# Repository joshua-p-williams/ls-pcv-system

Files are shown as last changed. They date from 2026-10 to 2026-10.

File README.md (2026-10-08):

# LS PCV System

Build a **crankcase health monitoring system** for a **2002 Pontiac Trans Am WS6 with a naturally aspirated 408 CID Gen III LS-based stroker** and Holley Terminator X. Measure crankcase pressure/vacuum to establish normal behavior, investigate changes over time, and design and validate the ventilation system.

This repository is an engineering notebook and a practical learning resource: mechanical design, hardware, firmware, calibration, and test results belong together. It explains how the parts work, why the design uses them, and how to assemble and evaluate the system as the project develops.

## Project purpose

Crankcase pressure is an additional **engine-health signal**. It reflects the balance between combustion gases leaking past the pistons into the crankcase (**blow-by**) and the positive crankcase ventilation (**PCV**) system removing those gases. Pressure also depends on ventilation restrictions, available intake vacuum and operating conditions. A change can therefore indicate a change in the engine, the ventilation system, or both. [Motorservice's discussion of excess crankcase pressure](https://www.ms-motorservice.com/MediaAssets/1727614_ks_50003605-02_web.pdf) describes both increased blow-by and ventilation faults as possible causes.

The goal is to measure that behavior repeatably, establish a baseline, and compare later observations under similar conditions. The instrumentation also gives ventilation design and tuning a measurable basis rather than relying on appearance, assumptions or the absence of visible oil leaks.

### Justifiable uses

- **Investigate increasing blow-by:** pressure changes may warrant checking ring, cylinder or piston condition after accounting for ventilation behavior; pressure alone does not measure blow-by flow.
- **Identify possible PCV restrictions or failures:** investigate plugged restrictors, blocked hoses, valve faults or catch-can problems when readings depart from the baseline.
- **Evaluate ventilation capacity under load:** measure behavior at high engine speed and wide-open throttle (WOT), when manifold-vacuum evacuation is reduced on this naturally aspirated engine.
- **Recognize abnormal positive pressure:** flag behavior that warrants investigation for oil leakage, seal problems, dipstick displacement or excessive oil carryover, without promising warning before damage occurs.
- **Compare PCV changes objectively:** evaluate restrictor sizes, relief-valve settings, hose routing and catch-can configurations using repeatable measurements.
- **Establish a fresh-engine baseline:** record known-good behavior to support later comparisons.
- **Provide a condition-monitoring signal:** reveal significant changes that may deserve attention even when drivability appears normal.
- **Support diagnostics:** correlate pressure with engine speed, load/manifold absolute pressure (MAP), throttle position and other available engine data.
- **Trend behavior over time:** supplement occasional compression and leak-down tests with observations from comparable operating conditions.
- **Evaluate ventilation strategies:** assess whether atmospheric venting, manifold-vacuum PCV or another arrangement meets the project's measured pressure and flow needs. Pressure performance alone does not establish suitability in every other respect.

### Intended role and interpretation

This is a **condition-monitoring and early-warning signal**, not a standalone instrument for identifying a specific mechanical failure. The same pressure change can result from increased gas production or reduced ventilation capacity. Further inspection, compression/leak-down testing and other evidence may be needed to distinguish causes.

The most useful indication is a repeatable departure from the engine's normal behavior under comparable conditions, rather than a single universal pressure threshold. Compare similar engine speed, load, temperature and ventilation configurations, using consistent sensor calibration and pressure-tap placement. A ventilation change may require a new baseline.

For a **hypothetical example, not project data or an alarm setting**:

> If the engine repeatedly produces +2 inH2O at 6,000 RPM/WOT and later produces +8 inH2O under comparable conditions, the increase warrants investigation. It does not, by itself, establish worn rings or any other specific failure.

The project has two connected purposes: monitor changes in crankcase behavior and provide the instrumentation needed to design and validate the ventilation system. Firmware, automated trending, alarm behavior and correlation with engine data remain development goals; the current prototype does not yet implement those capabilities. See the [measurement architecture](hardware/architecture/measurement-system.md), [firmware requirements](firmware/README.md) and [test plan](docs/testing/test-plan.md) for the work toward them.

## System concept

```text
Crankcase -> catch can -> interchangeable fixed restrictor -> manifold vacuum
                 |
                 +-> low-cracking-pressure relief -> atmosphere

Pressure measurement: upstream of the restrictor, referenced to atmosphere
Gauge: FTP sensor -> conditioning -> ADS1115 -> ESP32-S3 -> GC9A01 display
```

The [engine PCV overview](hardware/architecture/pcv-system.md) records the selected fresh-air and evacuation paths. Exact ports, fittings, physical hose routing and sensor mounting remain open.

## Current baseline

The baseline combines reported installation and purchase information, imported artifacts, and current design choices. Purchased and modeled components have not yet established measured system performance. The [original project context](docs/LS_PCV_SYSTEM_CONTEXT.md) preserves earlier reasoning and superseded proposals.

| Area | State |
| --- | --- |
| Catch can | Installed as an earlier project on 2026-09-13 in temporary vented mode; manifold-vacuum PCV remains incomplete |
| Restrictor | 3.0 mm baseline; 2.0 and 4.0 mm comparison variants; initial PAHT-CF print reported complete |
| Relief | Three EVIL ENERGY valves purchased; advertised 0.5 PSI opening pressure; approximately 0.1 PSI desired, modification/bench validation pending |
| Instrumentation | FTP sensor on hand; HiSport 13585316 pigtail not yet received; actual identity/pinout, fit and calibration pending |
| Power | [SSLHONG B09NVG35CX](hardware/components/gauge-power-supply/README.md) purchased for USD 13.99; advertised 8-60 V input, 5 V / 3 A USB-C output; validation pending |
| Gauge | ESP32-S3 bench/XIAO boards, GC9A01 TFTs, and ADS1115 modules purchased; ADC conditioning, wiring, final display layout, and enclosure pending; no firmware yet |
| Repository | Documentation, catch-can photos, native restrictor CAD, 3MF variants, and model views imported; measured data still pending |

Primary pressure unit: **inH2O**, relative to atmosphere; negative means vacuum. Approximately -3 to -8 inH2O at hot idle/light cruise is a provisional tuning target, not a GM specification or a validated limit. The 3 mm restrictor is a baseline, not a proven final choice.

## Repository map

| Location | Contents |
| --- | --- |
| [AGENTS.md](AGENTS.md) | Instructions for Codex and other coding assistants |
| [Hardware documentation](hardware/README.md) | Architecture, interfaces, wiring and component navigation |
| [Diagram inventory](hardware/DIAGRAMS.md) | Existing drafts and proposed diagrams/interface pages |
| [A04: engine PCV overview](hardware/architecture/pcv-system.md) | Planned airflow, relief, restrictor and pressure tap |
| [A01: overall gauge architecture](hardware/architecture/gauge-system.md) | Planned measurement, controller, display and power boundaries |
| [A02: power architecture](hardware/architecture/power-system.md) | Supply paths, returns and bench/vehicle/USB modes |
| [A03: measurement signal chain](hardware/architecture/measurement-system.md) | Calibration, validity, peak capture and display smoothing |
| [Diagramming standard](docs/diagramming-and-wiring-standard.md) | Formats, folder responsibilities, evidence and tooling |
| [W01 bench harness](hardware/wiring/bench/README.md) | Full wiring draft, proposed GPIOs, generated connection schedule and phased assembly checks |
| [L01 / Wokwi](simulation/wokwi/README.md) | Complete intended bench connections, visual-part mappings and future simulation limits |
| [Wokwi adoption](docs/wokwi-adoption.md) | Tool responsibilities and illustration/simulation scope |
| [cad/pcv-restrictor/](cad/pcv-restrictor/README.md) | Restrictor design intent and source/export conventions |
| [Hardware components](hardware/components/README.md) | Component descriptions, design decisions and import records |
| [hardware/bom/parts.md](hardware/bom/parts.md) | Parts, procurement status, and unresolved selections |
| [Gauge electronics](hardware/components/gauge-electronics/README.md) | Integration and reading/building path; separate N16R8, XIAO and GC9A01 component guides |
| [Pressure sensor and pigtail](hardware/components/fuel-tank-pressure-sensor/README.md) | Purchased parts, connector references, and verification needs |
| [ADS1115 acquisition](hardware/components/adc/README.md) | ADC selection, preliminary conditioning, and sampling plan |
| [Gauge power supply](hardware/components/gauge-power-supply/README.md) | Converter selection, power plan, and mounting reference |
| [Check valve / relief](hardware/components/check-valve-relief-valve/README.md) | Purchased valve, vendor claims, and relief-validation needs |
| [Datasheets](hardware/datasheets/README.md) | Preserved vendor revisions and official source links |
| [firmware/](firmware/README.md) | Gauge requirements and planned ESP32-S3 development environment |
| [docs/testing/](docs/testing/test-plan.md) | Planned bench and vehicle validation |
| [Open questions](docs/open-questions.md) | Follow-up questions, evidence needed and bench-harness dependencies |
| [docs/status.md](docs/status.md) | Next work and unresolved decisions |
| [Catch-can installation](docs/installation/2026-09-13-catch-can.md) | Earlier vented installation, timeline, and photos |
| [data/](data/README.md) | Calibration and measurement record conventions |
| [Original context](docs/LS_PCV_SYSTEM_CONTEXT.md) | Historical rationale; superseded choices are not current instructions |

Create `cad/gauge/` and `docs/research/` with their first useful content. Native FreeCAD source belongs in `cad/<component>/source/`; the current restrictor 3MF variants are together in `cad/pcv-restrictor/printing/`. Add intentional STL/STEP exports under a component's `exports/` if needed. Keep installation photos in `media/photos/`, model views/diagrams in `media/diagrams/`, and vendor illustrations in `media/reference/`.

## Working in this repository

Start with this README and the relevant component document. Use the original context for background; dated measurements and updated design documents should explain any changes to that baseline. Keep assumptions, published claims, physical observations, and measured results distinct.

Use the BOM for current purchase/inventory facts, component READMEs for current design details, and `docs/status.md` for open work. Dated installation/import records preserve what was observed or imported at that time. Native CAD defines saved geometry; physical records define what was actually built and measured. Reconcile conflicts explicitly instead of assuming the historical context or a filename is authoritative for every question.

Use UTF-8, LF line endings, descriptive lowercase kebab-case names where practical, and explicit units. Preserve native CAD source and raw measurements. For important changes, record the reason, evidence, validation, and unresolved questions alongside the affected component.

There are no firmware dependencies, build commands, or automated tests yet. Review Markdown links, units, and consistency, and run `git diff --check` for unstaged changes and `git diff --cached --check` for staged changes. Review new untracked files separately; before committing, ensure the staged versions include the intended edits. Add build/test instructions when executable code is introduced.

## Private intake workflow

Place new source material in `_staging/inbox/<batch>/` (for example, a dated project folder). The entire root `_staging/` directory is ignored by Git. Assistants may use `_staging/work/<batch>/` for processing while preserving your inbox originals.

Ask for a batch to be imported. The import should select useful engineering content, remove personal/sensitive information and embedded image metadata, and place reviewed public copies in the appropriate project folders. A public import record should explain provenance, transformations, omissions, and unresolved claims without linking to private files. Originals stay in the inbox unless you request cleanup.

Ignored directories are local only. On a fresh clone, create the inbox with `New-Item -ItemType Directory -Force _staging/inbox` in PowerShell. Git ignore is protection against accidental adds, not encryption or a substitute for reviewing public files; never force-add the staging tree.

## Next steps

1. Verify physical variants, measured bores, and slicer behavior against the [adopted restrictor CAD design](cad/pcv-restrictor/README.md).
2. Confirm current parts status and final plumbing; the earlier vented installation is documented separately.
3. Finalize ADS1115 conditioning/configuration and verify sensor, board, and display electrical interfaces before bringing up the ESP32-S3/GC9A01 prototype.
4. Characterize the sensor and relief valve on the bench before vehicle tuning.

This design is specific to this engine until evidence supports broader use. The gauge is a diagnostic instrument, not a certified safety device. See the [test plan](docs/testing/test-plan.md) for validation gates.

License selection is pending; this scaffold does not add a license grant.

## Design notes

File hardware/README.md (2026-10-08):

# Hardware documentation

Start with the [diagram inventory](DIAGRAMS.md) to choose upcoming documentation and the [diagramming/wiring standard](../docs/diagramming-and-wiring-standard.md) for formats, responsibilities, evidence labels and tooling.

- [Components](components/README.md): component descriptions, design notes and import records.
- [Architecture](architecture/README.md): system, PCV, power and measurement relationships. Current drafts: [A04: engine PCV overview](architecture/pcv-system.md), [A01: overall gauge architecture](architecture/gauge-system.md), [A02: power architecture](architecture/power-system.md), and [A03: measurement signal chain](architecture/measurement-system.md).
- [Pinouts](pinouts/README.md): module and connector identities and interface evidence.
- [Wiring](wiring/README.md): separate bench and vehicle harnesses.
- [Wokwi illustrations and simulation](../simulation/wokwi/README.md): L01's initial component-and-wire view, virtual/physical mappings and future ESP32 simulation.
- [Schematics and layouts](schematics/README.md): optional spatial illustrations and future circuit projects.
- [BOM](bom/parts.md): existing procurement authority.
- [Datasheets](datasheets/README.md): preserved reference revisions.

Use the [gauge integration guide](components/gauge-electronics/README.md#reading-and-building-path) for the learning and assembly path. Separate component guides cover the [N16R8 development board](components/esp32-s3-dev-board/README.md), [XIAO](components/xiao-esp32s3/README.md), [GC9A01 display](components/gc9a01-display/README.md), [ADC](components/adc/README.md), [sensor/pigtail](components/fuel-tank-pressure-sensor/README.md), [power supply](components/gauge-power-supply/README.md), and [relief valve](components/check-valve-relief-valve/README.md). Interface pages link to these explanations; the BOM retains procurement responsibility.

## Organization

Keep this directory as the entry point for hardware documentation. Only shared navigation and inventory documents live directly here; group substantive content by purpose in the directories above. New component records belong in `components/<component>/` and are listed in the [component index](components/README.md).

Architecture, pinouts, harnesses, schematics, procurement and datasheets remain shared categories alongside `components/`. Reuse those categories before introducing a new one. Native CAD and media retain their existing repository locations; component pages connect the relevant records through links.

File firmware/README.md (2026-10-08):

# Crankcase pressure gauge firmware

Status: planned; no firmware, dependencies, or build/test commands yet. The selected direction is **ESP32-S3**, with an N16R8 development board and XIAO ESP32-S3 finished-gauge target. The first display is a **240 x 240 GC9A01 SPI TFT**. Planned development uses VS Code, PlatformIO, the Arduino framework for ESP32, and C/C++. See [gauge integration guide](../hardware/components/gauge-electronics/README.md) and [procurement BOM](../hardware/bom/parts.md). This supersedes the earlier Nano/OLED candidates.

Separate PlatformIO environments should eventually share application code while isolating board-specific GPIO/configuration. Exact board definitions, platform/library versions, and pins remain unselected; no environment files are created by this import.

See [A01: overall gauge architecture](../hardware/architecture/gauge-system.md) for acquisition, controller, display and control boundaries, and [A04: PCV system overview](../hardware/architecture/pcv-system.md) for the pressure being observed. Both are planned-system drafts, not verified hardware configurations.

See [A03: pressure measurement signal chain](../hardware/architecture/measurement-system.md) for acquisition/calibration responsibilities, fault handling and separation of peak capture from display smoothing.

Use [P01: bench-board interface](../hardware/pinouts/esp32-s3-devkit.md) and the [W01 proposed controller table](../hardware/wiring/bench/generated/connections.md#proposed-controller-assignments) when defining the N16R8 environment and GPIO configuration. W01 owns the proposed wiring; actual board identity and assignments still require verification.

Use [P02: XIAO interface](../hardware/pinouts/xiao-esp32s3.md) for the XIAO alias/GPIO mapping and pin-budget constraints; the final project assignments remain open.

## Board configurations

The [Wokwi bench illustration](../simulation/wokwi/README.md) covers the intended measurement chain using original visual placeholders where no functional model is selected. No runnable project simulation exists yet. When PlatformIO environments are introduced, add `wokwi.toml` beside the maintained diagram under `simulation/wokwi/`, with paths to actual firmware/ELF outputs and explicit registration of any compiled custom chips; select that configuration in VS Code. Preserve hardware GPIO decisions, identify synthetic measurements and keep measurement logic independent of physical versus simulated acquisition. Visual stubs provide no device behavior; virtual geometry does not establish physical compatibility.

Use explicit build-time configurations for the N16R8 development board and standard XIAO ESP32-S3, selected through separate PlatformIO environments when firmware is introduced. Both use ESP32-S3, so chip identity alone does not identify the carrier or its wiring. Automatic board detection is not a requirement; the build/upload target must be chosen explicitly.

Each configuration must identify its board and harness revision, GPIO mapping, bus assignments, enabled peripherals/controls, and applicable memory, USB and upload settings. Use named functions such as display chip-select and ADC clock rather than scattering board-specific pin numbers through application code. Keep peripheral settings and calibration identity explicit where the assembled hardware differs; calibration is not interchangeable merely because the controller profile changes.

Share measurement, calibration, peak tracking and display behavior across boards. Require a supported board configuration rather than silently falling back to another pin map, and expose the selected configuration in startup diagnostics. Check both builds and validate each on its matching hardware; building successfully does not verify wiring or power compatibility. Exact environment IDs, GPIOs and implementation remain pending.

## Intended first implementation

- Read the actual GM-style FTP sensor through the selected ADS1115 external ADC and required signal conditioning; the shared 5 V supply and +/-6.144 V range are selected; the initial analog filter is 470 ohm / 1 uF; rate/address candidates, filter response and any additional protection remain under review. See the [ADC plan](../hardware/components/adc/README.md).
- Apply measured calibration and display signed pressure in `inH2O`.
- Provide deliberate atmospheric zero and min/max reset controls.
- Capture positive and negative peaks independently of display smoothing.
- Detect implausible readings and invalid calibration visibly rather than presenting them as valid zero pressure.

Never automatically zero while the engine runs. Zero requires the pressure port to be equalized to atmosphere. One multifunction button is selected; its initial gesture mapping is selected below; physical wiring remains open. Persistent user settings are required as described below; storage details, warning thresholds, sampling rate and filtering parameters remain design decisions.

W01 selects native ESP32-S3 USB for programming/console/debugging; configure the matching USB interface when firmware is introduced and preserve GPIO19/20. UART COM remains a separate recovery option, not the W01 source. Firmware must run the gauge without a computer attached. USB diagnostics must not indefinitely block startup or acquisition while waiting for host enumeration or a serial-console connection.

## Multifunction button

Use one multifunction button for both controller configurations, with [BetterButton](https://github.com/joshua-p-williams/BetterButton) as the planned input library. Its README documents click, double-click and long-press events, a normally open button from GPIO to ground, and an internal pull-up configured by `begin()`. This is the intended interface direction; the physical switch, GPIO, cable and any additional filtering remain to be selected for the harness.

The reviewed [header](https://github.com/joshua-p-williams/BetterButton/blob/master/BetterButton.h) defines 2000 ms long-press, 500 ms double-click monitoring and 60 ms debounce constants. These are upstream reference values, not accepted gauge timing requirements. The README and header were reviewed; implementation audit, ESP32-S3 compatibility and behavior under display/acquisition load remain pending. Pin an exact revision and retain license attribution when integrating; no dependency or source code has been imported yet.

Read button events regularly and handle each returned event once. Keep gesture detection separate from gauge actions and avoid blocking measurement or peak capture. Q24 selects the following initial actions in the normal gauge view:

| Gesture | Action |
| --- | --- |
| Click | Clear min/max using the accepted peak-reset behavior; do not change calibration or zero |
| Double-click | Unassigned; no gauge action |
| Long press | Open an atmospheric-zero confirmation prompt; do not change zero merely by opening it |

Q25 selects the atmospheric-zero prompt behavior:

- Long press from the normal gauge view opens the prompt with **Cancel** selected. Opening it does not change zero.
- Show a reminder to equalize the sensor to atmosphere before confirming.
- A single click toggles between **Cancel** and **Zero**.
- A double-click selects the highlighted action: Cancel dismisses unchanged; Zero requests deliberate atmospheric zero using a valid measurement/configuration.
- Inactivity dismisses the prompt without changing zero. The timeout duration remains a firmware tuning parameter.

Keep prompt actions separate from the normal-view peak-reset action; a prompt click must not clear min/max. Verify that the double-click selecting Zero does not first toggle the selection as a single-click action. The interaction does not establish atmospheric conditions automatically or replace calibration/validity checks.

 Distinguish normal-view and prompt-state handling, and verify that double-click/long-press recognition does not also invoke a single-click reset. Gesture timing and physical behavior require testing on both controllers. A long press is not proof that the pressure port is at atmosphere. Deliberate zero must retain the atmospheric-condition requirement. Q23 selects the brightness policy below. The initial mapping remains in effect until a later settings-menu design explicitly replaces it.

## Brightness and persistent settings

Use a fixed brightness default for the initial build. Keep the requested brightness/default configurable in software where the verified display hardware supports adjustment. The numeric default, range and mechanism remain TBD. P05/Q06 have not established backlight control on this seven-pin module; a software setting alone cannot establish that capability. Do not add an unverified dimming circuit or GPIO merely to expose a setting, and do not present an unsupported brightness setting as functional.

Plan persistent user settings for later firmware and in-car configuration: explicit initial defaults apply when no valid saved settings exist, and accepted saved choices are restored after power loss/restart. This is the requested EEPROM-style persistence behavior; the storage API/backend and data format remain to be selected during implementation. No external EEPROM component is selected. Keep user preferences distinct from calibration records and board pin configuration; this decision does not settle calibration or peak persistence.

A future single-button settings menu is proposed: long press to enter the menu, single click to advance through items, and double-click to select or edit. It is not yet the finalized interaction mapping. Resolve entry/exit, editing, confirmation, cancellation, save behavior and atmospheric-zero access under Q26, reconciling Q24/Q25 when that menu is adopted. Menu interaction must not suspend acquisition or peak capture.

Persist accepted changes rather than continuously writing unchanged settings. Define validation, format versioning, recovery from invalid/incomplete saved data and restoration of defaults. Verify retention across restart and behavior after interrupted saves on each controller configuration. Firmware and storage implementation remain future work.

## Hardware prerequisites

Document verified sensor terminal positions, signal voltage range, external ADC input limits/reference and bus logic, board power inputs, display supply/interface, grounding, and power protection. W01 proposes N16R8 GPIOs for the ADC's I2C and display's SPI interfaces; XIAO allocation remains separate. A 5 V sensor supply does not establish compatibility with a 3.3 V input. Draft wiring identifies unresolved connections with question IDs; confirm compatibility before treating those connections as assembly-ready or attaching hardware.

Use calibration of the actual sensor rather than an assumed OE transfer function. Retain raw ADC data and reference information alongside the [calibration records](../data/README.md).

The ADS1115 and sensor share 5 V, with A0 single-ended and +/-6.144 V range selected for the assumed 0-5 V signal. The ESP32 side remains 3.3 V through an I2C translator. Remove divider compensation from this configuration; 187.5 uV/count is the nominal ADC voltage conversion at the selected range, not a pressure calibration. [W01](../hardware/wiring/bench/README.md#adc-bring-up-candidate) retains provisional address, rate and polling settings. Measure acquisition timing independently of display refresh and record the hardware/configuration with calibration.

## Implementation boundaries

Keep acquisition, calibration, filtering, peak capture, display, buttons, and persistence separable without creating a framework before it is needed. Optional serial/SD logging and Holley integration can follow the standalone gauge.

Render a shared gauge state rather than coupling sensor/calibration code to GC9A01 or its 240 x 240 resolution. The initial goal is one pressure display; multiple small displays or a larger approximately 2.1-inch module remain future options pending readability evaluation.

When firmware implementation begins, document exact tool versions, setup, build, upload, and test commands here. Software checks should cover calibration/sign conventions, invalid inputs, peak preservation, and zero/reset behavior; bench checks must establish actual electrical and timing behavior.

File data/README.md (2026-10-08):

# Calibration and test records

No measurements have been imported yet. Create `calibration/` and `logs/` with their first real records; do not populate them with invented example readings.

See [A03: pressure measurement signal chain](../hardware/architecture/measurement-system.md) for the distinction between raw counts, calibrated pressure, display values and calibration/zero changes.

## Storage conventions

- Keep original acquisition files unchanged, including native logger formats.
- Use CSV for portable tabular exports with explicit units in column names. Preserve timestamps or elapsed time, and raw ADC counts alongside calibrated pressure when available.
- Give each run a stable ID such as `2026-10-05-run-001`; use ISO dates and record timezone for wall-clock timestamps.
- Use a neighboring Markdown file with the same stem for setup, provenance, and observations.
- Store processed results separately with links to raw inputs and the script or calculation used. Do not overwrite original data during recalibration.
- Missing values are missing, not zero. Explain blanks, dropped samples, fault flags, and unavailable channels.

## Calibration metadata

Record sensor ID/exact part, terminal mapping, date, pressure reference and sign convention, supply/reference voltage, ADC module identity/resolution, gain, conversion rate/mode, channel/address, conditioning component values, hardware/firmware revision, atmospheric zero procedure, applied pressures, raw readings, repetitions, fitted model/coefficient units, residuals, and validity range. Identify which calibration a vehicle run uses.

## Vehicle-run metadata

Record run ID, date/timezone, vehicle configuration, source commit when available, restrictor measured bore, hose routing, relief configuration and test record, pressure tap, calibration ID, sample rate, filtering/peak method, operating conditions, and observations. Include actual channels and their units; RPM/MAP/TPS are optional if not recorded.

Suggested pressure channel names: `elapsed_ms`, `raw_adc_counts`, `adc_input_voltage_v`, `sensor_voltage_v`, `pressure_inh2o`, `display_pressure_inh2o`. Record the actual ADC range; the selected shared-5 V design has no divider correction. Keep sensor and ADC-node measurements distinct when investigating filter drop or wiring error. Historical divider configurations require their own recorded ratio. This is a naming guide, not a required logger schema or fabricated dataset. A voltage column requires a known conversion/reference; a computed voltage is not an independently measured value.

Follow the [test plan](../docs/testing/test-plan.md) and keep assumptions separate from evidence.

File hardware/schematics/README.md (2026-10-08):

# Schematics and physical layouts

Follow the [standard](../../docs/diagramming-and-wiring-standard.md). Use [Wokwi](../../simulation/wokwi/README.md) for instructional electronics component-and-wire views and temporary solderless breadboard illustrations. L01's complete intended bench connection view lives there; it does not reproduce a permanent protoboard's solder-hole map or actual module footprints.

Create `drawio/` with the first selected installation/spatial illustration that other tools do not express well; use editable `.drawio.svg` with embedded diagram data. Detailed permanent perfboard mapping may use DIY Layout Creator if needed; it is not a current dependency.

A physical-layout illustration is not an electrical schematic or dimensional CAD authority. Circuit schematics, if needed, belong in a named circuit subdirectory with native KiCad files and reviewed exports. Analog conditioning or protection complexity may justify a schematic even without a custom PCB. No detailed carrier layout or circuit schematic has been created yet; see the [inventory](../DIAGRAMS.md).

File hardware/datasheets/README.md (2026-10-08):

# Vendor datasheets

Reference copies preserve the document revision used by the project. Vendor copyright, attribution, and notices remain intact; these documents are not project-authored material. Check the official source for later revisions before relying on a stored copy for new design work.

| Local reference | Publisher | Document / revision | Printed revision date | Imported | Official source |
| --- | --- | --- | --- | --- | --- |
| [ADS111x datasheet](ads1115-datasheet.pdf) | Texas Instruments | SBAS444E, Rev. E | December 2024 | 2026-10-06 | [TI ADS1115 datasheet](https://www.ti.com/lit/ds/symlink/ads1115.pdf) |

The 57-page PDF covers ADS1113, ADS1114, and ADS1115. It was supplied in the `ADC` source batch and copied without modification. Document metadata identifies TI and its publishing tools; no personal annotations or embedded attachments were found. The printed revision date identifies the datasheet revision, even though PDF generation timestamps are later.

Verified the document title/revision, rendered the first page for visual inspection, and confirmed source and repository copies have identical SHA-256:

```text
eefff4d412ce2dcd7e659f47238edc9b2fa02e5971f2625af730502033701834
```

See the [ADC hardware reference](../components/adc/README.md) for how the device is intended to be used. The datasheet does not authenticate the purchased third-party breakout modules.

## ESP32-S3-WROOM-1 and WROOM-1U

[Local module datasheet](esp32-s3-wroom-1_wroom-1u-datasheet-v1.8.pdf): Espressif Systems, version 1.8, revision history dated 2026-03-02, 53 pages. Imported 2026-10-06 from `bench-board-verification`. [Official source](https://www.espressif.com/sites/default/files/documentation/esp32-s3-wroom-1_wroom-1u_datasheet_en.pdf).

Preserved unchanged, including publisher notices. Reviewed metadata, attachment absence and link-only annotations; no personal annotations or local-file links were found. Rendered the cover and checked module variants and revision history. This reference does not establish the third-party carrier's schematic or authenticate the received module. See the [board evidence record](../components/esp32-s3-dev-board/bench-board-reference.md).

Source and repository SHA-256 match:

```text
27d71971da07c280c6068d08c74720d1a25b8f20cf8494dc1765bdd28d40d435
```

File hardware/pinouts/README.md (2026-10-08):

# Module and connector interfaces

Create a module page when selected from the [inventory](../DIAGRAMS.md). Follow the [standard](../../docs/diagramming-and-wiring-standard.md); each page identifies its source evidence and outstanding physical checks.

Each page records exact module/revision, connector identity, viewing orientation and evidence, followed by a table with terminal/cavity, printed label, function, voltage domain, direction, evidence state and source. Explicitly distinguish chip pins from module headers and GPIO aliases. Put unresolved details in a short verification checklist. Link to the authoritative harness for destinations.

Initial candidates are the N16R8 bench board, XIAO ESP32-S3, ADS1115 module, GC9A01 display, purchased FTP sensor/pigtail, and SSLHONG converter. Verify actual variants; generic chip documentation does not prove a module's header order. Optional controls follow selection.

[P01: ESP32-S3 N16R8 bench board](esp32-s3-devkit.md) provides an image-based header map, GPIO restrictions and pending interface assignments. Physical board verification remains open.

[P03: ADS1115 module](ads1115.md) documents the image-based header order, TI pin functions, address options, 5 V ADC supply and translated 3.3 V controller interface; physical module verification and configuration remain open.

[P02: XIAO ESP32-S3](xiao-esp32s3.md) documents the manufacturer edge-pin map, aliases, power references and allocation constraints for the finished-gauge controller.

[P04: FTP sensor and pigtail](ftp-sensor.md) records connector-view conventions, unresolved terminal assignments, planned electrical/pressure interfaces and the evidence needed before wiring.

[P05: GC9A01 display](gc9a01.md) documents the pictured SPI header, controller signal budget and selected 3.3 V supply/logic and remaining current/backlight checks.

[P06: SSLHONG converter](buck-converter.md) records labeled input polarity, the USB-C power-output boundary and checks for power distribution, returns and USB coexistence.

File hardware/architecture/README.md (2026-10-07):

# System architecture

Use Markdown with embedded Mermaid for conceptual PCV, gauge, power and measurement relationships. See the [standard](../../docs/diagramming-and-wiring-standard.md) and [inventory](../DIAGRAMS.md).

The [engine PCV overview](pcv-system.md) describes the planned airflow and instrumentation. Each selected page should define its scope, show known subsystem boundaries, distinguish proposed/current states and label unresolved interfaces. Do not use architecture diagrams as pin-to-pin assembly instructions. Firmware-specific diagrams belong near firmware and test workflows near test procedures; index both centrally.

The [overall gauge architecture](gauge-system.md) expands A04's gauge block into measurement, controller, display, control and power boundaries.

The [gauge power architecture](power-system.md) expands A01 into supply paths, return references, operating modes and unresolved power decisions (A02).

The [pressure measurement signal chain](measurement-system.md) details calibration, zero, validity and independent peak/display paths (A03).

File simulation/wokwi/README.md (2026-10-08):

# Wokwi bench illustration and simulation

**L01 state: Draft; complete intended bench connectivity, not assembly-ready.** [diagram.json](diagram.json) illustrates the controller substitute, display, ADS1115, BSS138 translator, FTP sensor, built RC filter, button and supply distribution. The [W01 harness](../../hardware/wiring/bench/README.md) owns the electrical design; [interface-map.json](interface-map.json) maps its terminals into this view. The complete USB cable is annotated because the virtual board has no matching cable endpoint.

See the [adoption decision](../../docs/wokwi-adoption.md), [standard](../../docs/diagramming-and-wiring-standard.md) and [inventory](../../hardware/DIAGRAMS.md). No gauge firmware or functioning peripheral models are included. Construction remains solderable protoboard with secure connections, removable modules and mechanical support.

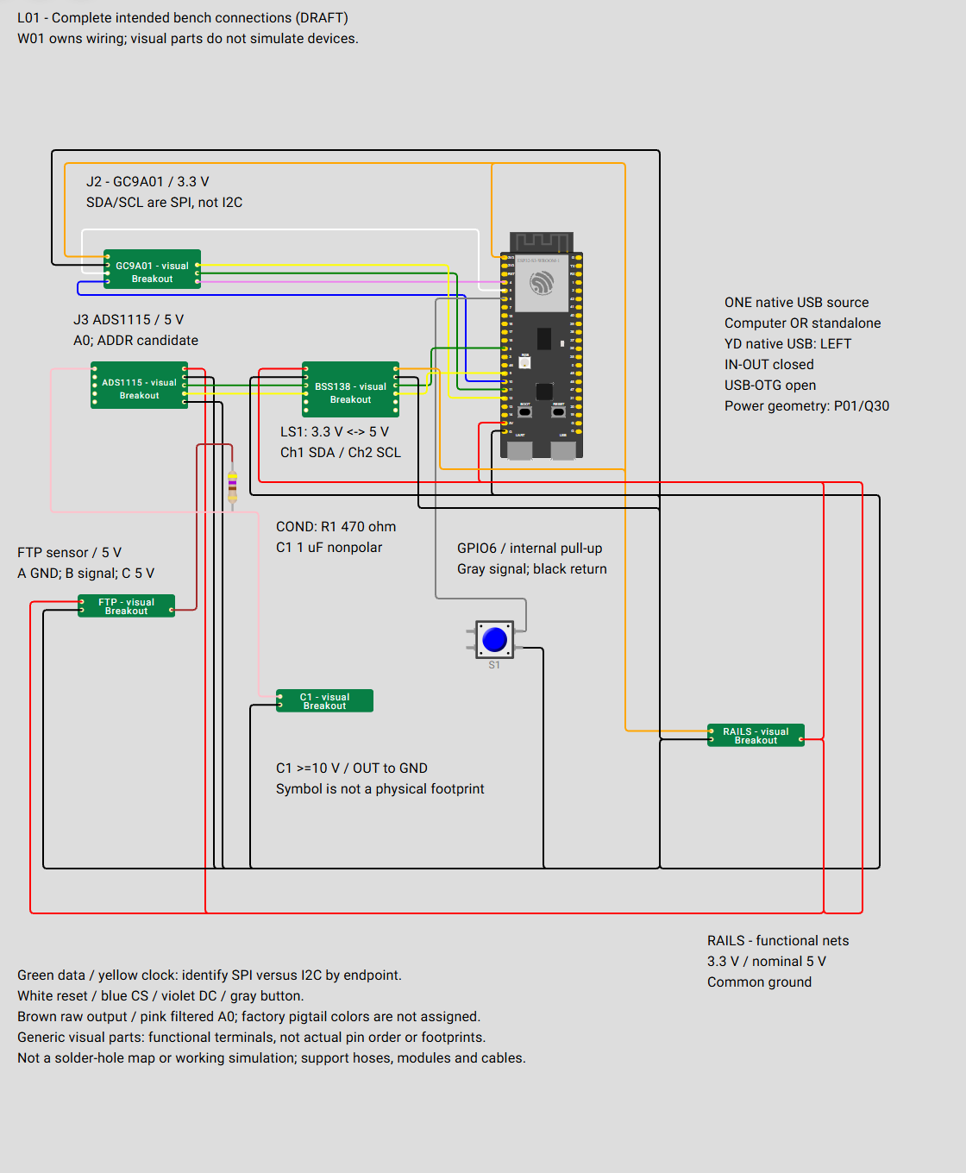
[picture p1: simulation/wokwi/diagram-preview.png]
L01 bench component-and-wire illustration


Open the [full PNG](diagram-preview.png) to zoom. This is a generated preview of [diagram.json](diagram.json), not an additional wiring source.

## Read the connections

**FTP.B** carries the raw sensor output through the brown lead to **R1**, the selected 470 ohm series resistor. The other lead is **COND.OUT**, the pink node shared by ADC **A0** and **C1**. C1 is the selected 1 uF nonpolar capacitor from OUT to ground. This shows the [RC filter](../../hardware/components/rc-input-filter/README.md)'s series/shunt topology; there is no divider or simulated filter response. The pink R1-to-C1 connection represents an internal node, not another required harness cable.

ADC and sensor share nominal **5 V**. ADC SDA/SCL connect through **LS1.HV1/HV2** to **LV1/LV2**, then controller GPIO8/9 at **3.3 V**. LV/HV supply references stay separate; both translator ground pads join common return. Channels 3/4 are unused. See the [translator](../../hardware/components/i2c-level-shifter/README.md) and [ADC interface](../../hardware/pinouts/ads1115.md).

Display VCC is **3.3 V**, with W01's five SPI/control wires. Display SDA/SCL mean SPI data/clock, not the ADC I2C bus. No MISO or backlight wire is added. ADC ADDR-to-GND is a candidate under Q08/Q18; A1-A3, ALERT and unused translator channels remain unconnected.

**S1** connects GPIO6 to ground when pressed. Planned firmware enables the internal pull-up: released HIGH, pressed LOW. The generic switch's `1.l`/`1.r` legs are internally common, as are `2.l`/`2.r`; the drawing uses opposite contacts `1.r` and `2.r`. No button supply is needed. See [button requirements](../../firmware/README.md#multifunction-button).

Colors follow [W01](../../hardware/wiring/bench/generated/connections.md#wire-color-convention): black ground, red nominal 5 V, orange 3.3 V, green data, yellow clock, white reset, blue CS, violet DC, gray button, brown raw analog and pink filtered A0. Endpoints distinguish SPI from I2C. These describe added wiring, not factory pigtail colors.

## Representation and mapping

J1 is Wokwi's ESP32-S3-DevKitC-1 using its [official definition](https://github.com/wokwi/wokwi-boards/blob/main/boards/esp32-s3-devkitc-1/board.json), substituting for the purchased YD-style N16R8. Attributes approximate 16 MB flash / 8 MB octal PSRAM and select native USB serial; GPIO19/20 stay reserved.

**Virtual header positions, footprint, USB ports and power paths differ.** Follow [P01](../../hardware/pinouts/esp32-s3-devkit.md) and [the power plan](../../hardware/components/esp32-s3-dev-board/power-plan.md). W01 selects one source at native USB, IN-OUT closed, USB-OTG open, and L21 nominal 5 V distribution. Native USB is left on the purchased board's front view. The virtual 5V terminal only illustrates that functional feed; it does not validate jumpers, diode drop or current capacity.

| Part | Representation |
| --- | --- |
| J1 | Native board GPIO functions; supply aliases `3V3.1`, `GND.1`, `5V` |
| J2 / J3 | Original GC9A01 / ADS1115 visual parts with all module terminal names |
| LS1 | Original BSS138 visual part with all channel/reference names and both ground aliases |
| FTP | Original visual part; A/B/C functions from the adopted [P04 map](../../hardware/pinouts/ftp-sensor.md) |
| RAILS | Separate functional 3V3, GND and 5V nodes, not a purchased terminal block |
| R1 | Native 470 ohm resistor; pin 1=COND.IN, pin 2=COND.OUT |
| C1 | Original visual part; OUT/GND are node aliases on a nonpolar capacitor, not polarity |
| S1 | Generic normally open button; opposite contacts map CONTACT_A/B |

Custom symbols use generic breakout presentation. **Leg order/package shape do not reproduce actual connector order or footprints.** Use hardware pinout/component references to identify real terminals. Exact aliases are in [interface-map.json](interface-map.json), checked against W01.

## Open online

1. Open a [new ESP32-S3 project](https://wokwi.com/projects/new/esp32-s3).
2. For each of the six names in the [visual-parts guide](chips/README.md), click **+**, select **Custom Chip**, enter the exact name, choose C and click **Create Chip**.
3. Replace the created `.chip.json` and `.chip.c` contents with the matching repository files. Online filenames are flat; repository files are grouped under `chips/`. Move or remove the automatically added instances as you go so they do not cover the editor toolbar; the final JSON restores them in their intended positions.
4. Finally replace `diagram.json` with [this source](diagram.json), removing the temporary instances and restoring the maintained view.
5. Hover over endpoints for labels. Use **F** with the diagram focused or the **Fit** menu, then zoom/pan as needed. See [editor controls](https://docs.wokwi.com/guides/diagram-editor).

Viewing needs no simulation run or chip compilation. Saving online is optional; Git holds the source. The template sketch is unrelated example code. The original C stubs only print an illustration notice when initialized; they implement no device behavior or gauge firmware.

## VS Code and future simulation

Use the **Wokwi Simulator** extension's [setup guide](https://docs.wokwi.com/vscode/getting-started). [Editor plans](https://docs.wokwi.com/vscode/diagram-editor) currently allow viewing/text editing on Community/Hobby; graphical editing requires Hobby+ or Pro. Keep credentials local.

**Expanded custom parts require registration in VS Code.** JSON alone may show missing chips and omit wires. [Custom-chip configuration](https://docs.wokwi.com/vscode/project-config#custom-chips) needs compiled `.chip.wasm`, adjacent definitions and `[[chip]]` entries, not yet provided. Use the online workflow for the complete editable illustration.

No active `wokwi.toml` or firmware build exists. When firmware is introduced, place its Wokwi configuration beside the diagram, reference actual firmware/ELF outputs under `firmware/`, and use **Wokwi: Select Config File** for this subfolder. Follow the [configuration](https://docs.wokwi.com/vscode/project-config) and [PlatformIO](https://docs.wokwi.com/vscode/platformio) guides; keep generated binaries local.

## Model coverage and next work

Native controller/button representations are supported, but have no project firmware to run. ADS1115, GC9A01, translator, sensor, distribution and C1 are **terminal-only visual parts**. They implement no conversion, SPI commands, translation, pressure output, internal pad joining, supply distribution or capacitance. R1's native simulation is [limited](https://docs.wokwi.com/parts/wokwi-resistor); RC response is not validated. USB behavior is annotated, and the vehicle converter/XIAO configuration remains outside this N16R8 view.

ADS1115/GC9A01 are absent from the documented [built-in list](https://docs.wokwi.com/getting-started/supported-hardware). A [community ADS1115 example](https://wokwi.com/projects/375022400134910977) was located, but its reuse license and coverage are not established; no code was imported. No GC9A01 candidate was established by this review. The [original definitions](chips/README.md) use the documented [custom format](https://docs.wokwi.com/chips-api/chip-json).

Future synthetic measurements can exercise shared calibration, validity, peaks, display and button logic. They do not test an ADC driver or I2C fault without the corresponding model/bus path. Keep acquisition separate from display smoothing and never automatically zero with the engine running. Add scenarios with useful content and describe what each tests. Physical rails/current, filter response, sensor calibration and retention still require actual tests.

## Check and maintain

### Refresh the PNG

[render-preview.mjs](render-preview.mjs) loads the source and six visual definitions into an unsaved online Wokwi project and captures only the diagram canvas in light mode. It does not save, share or start the simulation. The PNG contains no editor UI or template sketch. Node.js and Puppeteer are optional documentation tools; they are not firmware dependencies. Run from the repository root:

```powershell
npm install --prefix _staging/work/wokwi/tools puppeteer@25.12.0
node simulation/wokwi/render-preview.mjs
```

The renderer accepts an optional path to an existing npm tooling directory as its first argument. It needs internet access to Wokwi and may need adjustment if the online editor UI changes. Output is [diagram-preview.png](diagram-preview.png), captured at 1120 x 1360 pixels using Puppeteer 25.12.0 / Node.js 24.15.0. Inspect the image after regeneration and refresh it whenever diagram connections, labels, positions or custom visual definitions change. The crop removes surrounding editor controls without changing diagram content.

### Check connectivity

Reuse W01's [pinned Python tooling](../../hardware/wiring/bench/README.md#rendering-and-validation); this checker uses existing PyYAML, not a firmware dependency. From the repository root:

```powershell
& _staging/work/w01/tools/venv/Scripts/python.exe simulation/wokwi/check.py
```

[check.py](check.py) compares all harness endpoints/colors with W01, validates native/custom pins and unique IDs, and checks the internal R1/C1 connection. Only the annotated whole USB cable is omitted. After an authorized W01 change, refresh projected connections with:

```powershell
& _staging/work/w01/tools/venv/Scripts/python.exe simulation/wokwi/check.py --sync
```

Unchanged directed connections retain routes; changed wires may need routing. Update aliases when interfaces change, then inspect the full view and check documentation links/whitespace. Keep unrelated positions stable; do not change hardware decisions to fit virtual parts.

Validation used Python 3.12.10 and W01's existing PyYAML environment: 20 parts and 29 wires passed endpoint/color, unique-ID, native/custom pin and RC-topology checks. The six original definitions were loaded into an unsaved online Wokwi ESP32-S3 project and the complete view was rendered and visually inspected using Puppeteer 25.12.0 / Node.js 24.15.0. The editor reported no missing chips or diagnostics. Relative-link/case and Git whitespace checks passed. These checks establish documentation consistency/presentation; no chip compilation, gauge firmware execution, physical fit or measured performance was tested.

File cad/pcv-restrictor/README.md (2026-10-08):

# PCV restrictor

The restrictor uses a short metering throat with interchangeable 2, 3 and 4 mm variants. The design files include native FreeCAD 1.1.1 CAD, three 3MF files and two model views; provenance is documented in the [import record](import-2026-10-05.md). An initial QIDI PAHT-CF print is reported; alternate variants are described inconsistently as printed and planned/printed, so their physical completion and measured bores remain unconfirmed.

See [A04: PCV system overview](../../hardware/architecture/pcv-system.md) for the restrictor between the proposed pressure tap and intake-vacuum return.

## Imported files

| Artifact | Purpose |
| --- | --- |
| [source/pcv-restrictor.FCStd](source/pcv-restrictor.FCStd) | Authoritative native model, currently 3 mm; editable feature tree |
| [printing/pcv-restrictor-2mm.3mf](printing/pcv-restrictor-2mm.3mf) | FreeCAD mesh export in millimeters; no slicer profile supplied |
| [printing/pcv-restrictor-3mm.3mf](printing/pcv-restrictor-3mm.3mf) | QIDI Studio project with 3 mm mesh and print settings |
| [printing/pcv-restrictor-4mm.3mf](printing/pcv-restrictor-4mm.3mf) | QIDI Studio project with 4 mm mesh and print settings |
| [Import record](import-2026-10-05.md) | Provenance, sanitization, validation, and evidence limits |

No STL or STEP exports were supplied or generated. Separate native source revisions for the 2 and 4 mm exports were not supplied. Public filenames use kebab-case; geometry and slicer settings were preserved.

## Adopted CAD design

The supplied native CAD geometry defines the current prototype design. It supersedes the earlier written dimensional targets; the comparison below retains those targets only as design history. Physical fit, durability and flow performance remain to be tested.

The supplied native model differs from the [historical context](../../docs/LS_PCV_SYSTEM_CONTEXT.md) and accompanying prose notes. These are native dimensions inspected in FreeCAD 1.1.1, not as-built measurements. Mesh inspection agrees apart from intentional metering variants and mesh approximation. All dimensions are in mm.

| Feature | Adopted CAD geometry | Superseded written target |
| --- | ---: | ---: |
| Metering ID | 3.0 native; 2.0 / 3.0 / 4.0 meshes | 3.0 baseline |
| Straight metering length | 3.0 | 3.0 |
| Overall length | 67.0 | Not specified |
| Maximum body OD | 14.0 | 14.0 |
| Main / barb straight passage ID | 6.4 | 8.0 main / 6.0 barb |
| Internal taper into throat | 8.0 long, 6.4 to metering ID | 6-8 long, 8 to 3 ID |
| Internal taper out of throat | 8.0 long, metering ID to 6.4 | 15 long, 3 to 8 ID |
| Separate 8 to 6 ID transition | Not present | 4-5 long |
| Barb root OD | 9.8 | 9.8 |
| Retention crest OD | 10.9 | Approximately 10.5 |
| Tip OD | Approximately 8.716 | Approximately 8.8-9.0 |
| Tip taper length | 3.0 | 3-4 |
| Straight root/clamp section | 15.0 each end | Clamp land approximately 8-10 |
| Tip-to-body-taper axial span | 19.0 each end; not measured hose engagement | Engagement approximately 16-18 |
| External body-to-root taper length | 3.0 each end | Approximately 7-8 |

Target hose ID is 3/8 in (9.525 mm). Compare 2.0, 3.0, and 4.0 mm metering variants; 2.5 and 3.5 mm may follow if measurements justify them.

## Design intent

### What the restriction changes

A **fixed restrictor** limits flow through a small passage rather than actively controlling a pressure setpoint. In this PCV system, the intake-vacuum path draws through the restrictor while blow-by and the fresh-air path affect crankcase pressure. The measured pressure is therefore a result of the whole system, not a pressure value assigned by the bore diameter.

The metering throat is the narrow passage that provides the intended restriction. Changing its diameter gives a repeatable design variable to compare on the bench and vehicle. Doubling a circular bore's diameter multiplies its area by four; that does not guarantee four times the flow, because pressure difference, passage geometry and gas behavior also matter. The adopted area calculations below explain why small diameter changes deserve measurement.

The catch can and restrictor have separate jobs: the can is intended to collect entrained liquid before the intake return, while the restrictor meters that return path. A clean-looking can, a modeled bore or an atmospheric zero reading alone does not establish the final PCV performance. Use the [test plan](../../docs/testing/test-plan.md) to compare actual configurations.

### Adopted prototype

The short metering section localizes restriction. The adopted internal tapers are symmetric: each is 8 mm long between the 6.4 mm passage and the metering throat. The earlier 15 mm diffuser and separate 8-to-6 mm passage transition are superseded proposals. The 3 mm throat is the initial tuning baseline, with 2 and 4 mm comparison variants; final sizing remains subject to measurements.

The actual 6.4 mm bore and 9.8 mm root OD leave nominal radial wall thickness `(9.8 - 6.4) / 2 = 1.7 mm`. This is a geometric calculation, not a strength or flow validation. Orifice areas are approximately 3.14, 7.07, and 12.57 mm² for 2, 3, and 4 mm respectively; area ratios alone do not establish actual flow.

The baseline material is QIDI PAHT-CF. Reported print orientation is vertical with the fitting axis along Z; keep support out of the passage. Inspect passages, hose-entry edges, and layer integrity. Record actual bore measurements and any finishing operation; a nominal filename does not establish the finished orifice diameter.

## Printing projects

The 3 and 4 mm projects identify QIDI Studio `02.07.02.60`, an X-Plus 4 printer, 0.4 mm nozzle, 0.2 mm layer height, and the `QIDI PAHT-CF @Qidi X-Plus 4 0.4 nozzle` filament profile. These are saved settings, not verified print-history records or universal printing recommendations. Slicer opening and slicing were not performed during import. Material suitability, finished bore, hose retention, sealing, and heat/vibration durability still require physical validation.

## CAD views

These are supplied model views, not photographs of printed parts; internal dimensions cannot be established from them alone.

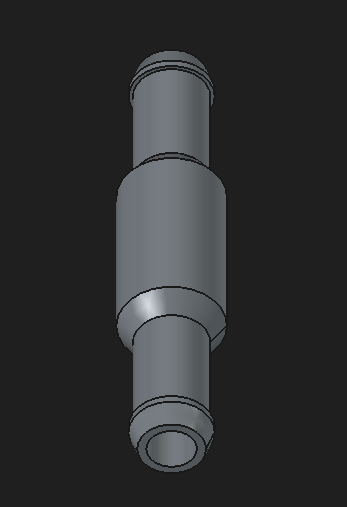
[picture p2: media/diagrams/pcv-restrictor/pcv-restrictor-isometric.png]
Isometric restrictor view


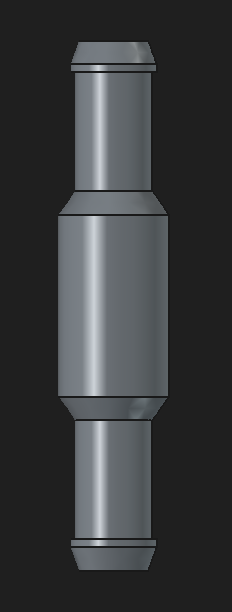
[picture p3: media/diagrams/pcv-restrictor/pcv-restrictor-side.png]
Side restrictor view


## Validation and further exports

Original and sanitized native files opened and fully recomputed in FreeCAD 1.1.1 with one valid solid and unchanged volume. All three meshes have valid indices and each undirected edge shared by two triangles. These checks do not establish physical suitability or constitute a full mesh self-intersection/slicer validation.

For future exports, record source revision, variant, units, application version, and tessellation settings. Export tessellation settings and exact source-to-export revision history were not supplied for this batch. Do not label these prototypes as validated releases.

Compare configurations using the [test plan](../../docs/testing/test-plan.md).

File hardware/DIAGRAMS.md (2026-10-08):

# Diagram and interface inventory

A01-A04 document the planned system architecture. P01-P06 document the controller, ADC, sensor, display and converter interfaces using available product imagery and manufacturer references. P04 adopts a sourced GM-family sensor map as a working assumption; physical verification remains pending throughout. The remaining entries are proposed documentation, grouped by priority and dependency. Follow the [standard](../docs/diagramming-and-wiring-standard.md).

Paths in code are planned destinations, not links to existing artifacts. As documentation is developed, add the artifact link and evidence state; use Proposed, Selected, Draft, Reviewed or Superseded for document progress. Track physical verification separately.

| ID | Priority | Candidate and question answered | Format / planned source | Readiness or dependency |
| --- | --- | --- | --- | --- |
| A01 | 1 | Overall gauge: how do sensor, conditioning, ADC, controller, display, controls and power relate? | Mermaid in [overall gauge architecture](architecture/gauge-system.md) | **Planned design**. Controller alternatives, signal/power boundaries and optional expansion; interfaces TBD |
| A02 | 1 | Power: where do power and returns flow in bench/vehicle and USB modes? | Mermaid in [power architecture](architecture/power-system.md) | **Planned design**. 3.3 V display and W01 USB arrangement selected; source/load validation, converter protection and simultaneous-power handling remain open |
| A03 | 1 | Measurement chain: how does pressure become calibrated readings, peaks and display values? | Mermaid in [measurement signal chain](architecture/measurement-system.md) | **Planned design**. Calibration, validity, zero, peak and display paths; timing/thresholds TBD |
| A04 | 1 | PCV system: where are the fresh-air path, catch can, restrictor, relief and pressure tap? | Mermaid in [PCV system overview](architecture/pcv-system.md) | **Planned design**. Planned routing; proposed sensor tap/mount and exact ports require review |
| P01 | 2 | N16R8 bench-board interface | Markdown [bench-board interface](pinouts/esp32-s3-devkit.md) | **Draft**. Header map and restrictions documented; native USB/jumper/L21 power arrangement selected from family schematic; normal received-board and load checks pending |
| P02 | 2 | XIAO ESP32-S3 interface | Markdown [XIAO interface](pinouts/xiao-esp32s3.md) | **Draft**. Manufacturer pin/alias map documented; revision, regulator-current discrepancy, USB handling and project assignments pending |
| P03 | 2 | ADS1115 module interface | Markdown [ADS1115 interface](pinouts/ads1115.md) | **Draft**. Image-based header map and TI electrical limits documented; fitted IC, board connections, pull-ups, address and configuration pending |
| P04 | 2 | FTP sensor and purchased pigtail interface | Markdown [FTP sensor interface](pinouts/ftp-sensor.md) | **Draft**. Pigtail view convention, planned functions and verification workflow documented; working A/B/C map adopted; as-built lead/fit checks and calibration pending |
| P05 | 2 | GC9A01 display interface | Markdown [GC9A01 interface](pinouts/gc9a01.md) | **Draft**. Seven-position SPI header and listed 3-5 V supply documented; 3.3 V VCC/logic selected; current/backlight, GPIO checks and operation pending |
| P06 | 2 | SSLHONG converter interface | Markdown [converter interface](pinouts/buck-converter.md) | **Draft**. Vendor-labeled input polarity and USB-C power output documented; actual wiring, output/return behavior, USB handling and protection pending |
| W01 | 3 | First bench harness: complete N16R8 single-display measurement-chain wiring with phased assembly/testing | [Guide and diagrams](wiring/bench/README.md), WireViz [source](wiring/bench/bench-harness.yml) | **Draft, not assembly-ready**. Proposed GPIOs and ADC setup; full drawing, four derived section views and connection schedule. Shared 5 V ADC/sensor and translated I2C selected; native USB/L21 takeoff and 3.3 V display selected (Q30/Q31); rail/load checks, translator bring-up, actual interfaces, wire sizing and filter power/protection review remain open; initial 470 ohm / 1 uF filter nodes are documented |
| W02 | 3 | FTP sensor subassembly | WireViz `wiring/bench/ftp-harness.yml` if separate | Verify terminals and conditioning boundary; otherwise include in W01 |
| W03 | 3 | Display subassembly | WireViz `wiring/bench/display-harness.yml` if separate | Confirm module and GPIO choices; otherwise include in W01 |
| W04 | 3 | ADC subassembly | WireViz `wiring/bench/adc-harness.yml` if separate | Confirm I2C, address, analog inputs and conditioning; otherwise include in W01 |
| F01 | 3 | Firmware acquisition/calibration/peak/display data flow | Mermaid in `../firmware/data-flow.md` | After acquisition/configuration decisions; no firmware implementation implied |
| T01 | 3 | Sensor calibration and relief-test workflows | Mermaid in `../docs/testing/test-plan.md` | Add only if a flow clarifies the existing procedure; link real data when available |
| L01 | 4 | Instructional bench component-and-wire illustration | Wokwi [guide](../simulation/wokwi/README.md), [JSON source](../simulation/wokwi/diagram.json) and [PNG preview](../simulation/wokwi/diagram-preview.png) | **Draft, complete intended connectivity**. All non-USB W01 conductors plus internal RC node; USB annotated. DevKitC substitutes for N16R8; unsupported modules use original terminal-only visual parts. Not physical footprints, assembly-ready wiring or working simulation; W01 owns connectivity |
| W05 | 4 | Vehicle gauge harness | WireViz `wiring/vehicle/gauge-harness.yml` | Separate design after source/fuse/ground/routing/connectors and bench findings are resolved |
| L02 | 4 | Gauge enclosure/electronics placement | Draw.io layout or CAD-associated view | After display/enclosure choices; choose destination with CAD work to avoid duplicate drawings |
| S01 | Conditional | Analog conditioning/protection circuit | KiCad under `schematics/` if warranted | Revisit if component-level connectivity needs a real schematic/ERC; not selected now |

## Next documentation

The architecture, P01-P06 interfaces and [W01 harness draft](wiring/bench/README.md) are in place. Use the [open-questions register](../docs/open-questions.md) to resolve the remaining design and interface checks before assembly-ready W01 wiring. W01's section views cover the display, ADC and sensor boundaries without separate competing sources; W02-W04 remain optional subassembly candidates.

[L01](../simulation/wokwi/README.md) now illustrates the complete intended bench wiring using native controller/button/resistor parts and original terminal-only placeholders. Preserve W01's 5 V ADC/sensor, translated I2C and 3.3 V display decisions. Functional models, VS Code custom-chip registration and actual firmware remain future work; see the [model limitations](../simulation/wokwi/README.md#model-coverage-and-next-work) and [adoption decision](../docs/wokwi-adoption.md).

## Inputs already available

Use [gauge electronics](components/gauge-electronics/README.md), [power](components/gauge-power-supply/README.md), [ADC](components/adc/README.md), [sensor](components/fuel-tank-pressure-sensor/README.md), [relief](components/check-valve-relief-valve/README.md), [adopted restrictor](../cad/pcv-restrictor/README.md), [test plan](../docs/testing/test-plan.md) and [current status](../docs/status.md). Existing CAD views and installation photos remain evidence in their component records, not new diagram deliverables.

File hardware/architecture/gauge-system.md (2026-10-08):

# Overall gauge architecture

A01 describes the planned single-channel, single-display gauge and its bench and XIAO controller variants. The embedded Mermaid is the conceptual source. Module interfaces and electrical validation remain pending.

## System boundaries

```mermaid
flowchart TD
    tap["PCV pressure tap: upstream of restrictor"]
    sensor["FTP pressure sensor"]
    conditioning["Analog filtering and protection"]
    adc["ADS1115 acquisition module: 5 V"]
    translator["Bidirectional I2C level translator"]
    controller["ESP32-S3 controller: one board per build"]
    display["GC9A01 display: 3.3 V; live pressure and min/max"]
    controls["User controls: zero and peak reset; hardware TBD"]
    source["Switched vehicle supply / selected bench source"]
    protection["Input fuse and protection: design TBD"]
    converter["SSLHONG converter: nominal 5 V output"]
    distribution["Power distribution and returns: rail details TBD"]
    future["Future channels / displays / logging / Holley link"]

    tap ---|"Pressure sense hose"| sensor
    sensor -->|"Analog voltage"| conditioning
    conditioning -->|"Filtered analog signal; no divider"| adc
    adc <-->|"I2C: 5 V side"| translator
    translator <-->|"I2C: 3.3 V side"| controller
    controls -->|"Deliberate user actions"| controller
    controller -->|"SPI and display control"| display
    source ==>|"Supply power"| protection
    protection ==> converter
    converter ==>|"5 V"| distribution
    distribution ==>|"Planned 5 V supply"| sensor
    distribution ==>|"Shared 5 V branch"| adc
    distribution ==>|"5 V side reference"| translator
    controller ==>|"3V3 low-side reference"| translator
    distribution ==>|"Verified board input required"| controller
    controller ==>|"Selected 3V3 module supply"| display
    controller -.->|"Optional expansion; not initial scope"| future

    classDef measurement fill:#e8f3fc,stroke:#245a81,color:#142c3e
    classDef power fill:#fff1d6,stroke:#956000,color:#493000
    classDef interaction fill:#e8f4e8,stroke:#376b37,color:#173717
    classDef optional fill:#f3f3f3,stroke:#666,color:#333,stroke-dasharray:5 5
    class tap,sensor,conditioning,adc,translator,controller measurement
    class source,protection,converter,distribution power
    class controls,display interaction
    class future optional
```

**Legend:** solid thin arrows are signals; the bidirectional arrow is the I2C interface; the line without an arrow is pressure sensing; thick arrows are conceptual power paths; the dashed arrow denotes optional future scope. Every path is planned. Arrow styles distinguish function, not evidence quality. The distribution block includes supply/return planning; separate ground wires and connector pins are not shown.

## Controller variants and first-build scope

Use one controller per build: the **ESP32-S3 N16R8 development board** for initial bench work, or the **Seeed Studio XIAO ESP32-S3** for the intended finished gauge and a matching bench configuration. These are alternative implementations of the controller block, not two processors connected together. Board-specific power inputs, GPIOs and firmware configuration must be documented separately. See [gauge electronics](../components/gauge-electronics/README.md).

Start with one FTP sensor, one ADS1115 module and one 1.28-inch GC9A01 display. Firmware converts readings using measured calibration, maintains signed pressure and independent positive/negative peaks, and renders live and min/max values in inH2O. Negative pressure means vacuum. Acquisition and peak capture remain independent of display smoothing. Invalid readings/calibration should be visible rather than presented as zero.

User controls provide deliberate atmospheric zero and peak reset; count, type and pin assignments are TBD. Zero requires the pressure port to be equalized to atmosphere and must not happen automatically with the engine running. No firmware or control hardware is implemented by this diagram. See [firmware requirements](../../firmware/README.md).

## Interfaces and unresolved decisions

| Boundary | Current intent | Still to establish |
| --- | --- | --- |
| PCV to sensor | Proposed tap at catch-can outlet before restrictor, as shown in [A04](pcv-system.md) | Physical tap, sense hose, mount/adapter, liquid protection and pressure difference from crankcase |
| Sensor to conditioning | Analog signal from the selected FTP sensor; planned 5 V sensor supply | Actual pinout, range, reference arrangement and calibration |
| Conditioning to ADC | Built 470 ohm / 1 uF RC filter ahead of 5 V ADS1115 A0; no divider | Actual stock parts, loading/response, power/fault behavior and input limits; [component guide](../components/rc-input-filter/README.md) |
| ADC to controller | I2C through translator: ADC at 5 V, ESP32 side at 3.3 V | hiBCTR BSS138 selected; actual pull-ups/bus checks, address, GPIOs and conversion rate pending; +/-6.144 V selected |
| Controller to display | SPI plus module control signals | 3.3 V VCC/logic selected from listing; GPIOs, current/backlight, driver and readability |
| Controls to controller | Deliberate zero and peak reset | Button count/type, wiring, debounce and interaction design |
| Power to electronics | Converter output feeds the planned gauge supply arrangement | Fuse/protection, rail generation/capacity, returns, grounding and load budget |

The [ADC notes](../components/adc/README.md) contain preliminary conditioning values, not a final schematic. This diagram deliberately shows the conditioning boundary rather than implying a direct sensor-to-ADC connection. [P04](../pinouts/ftp-sensor.md) supplies an adopted family terminal map; the measured transfer curve remains calibration work.

## Power scope

The selected [SSLHONG converter](../components/gauge-power-supply/README.md) supplies the nominal 5 V system for vehicle/converter operation. The FTP sensor and ADS1115 share that regulated branch. The ESP32's 3V3 output supplies the translator low-side reference and compatible peripherals; the translator high side uses the shared 5 V domain. This replaces the former 3V3 ADC arrangement. The [hiBCTR BSS138 module](../components/i2c-level-shifter/README.md) is selected; physical bus checks and rail capacity remain to be established; display VCC is selected at 3.3 V (Q31), with current/backlight behavior remaining to check.

A selected bench source can exercise the converter path shown here. W01 selects native USB for programming/debugging and single-source power with IN-OUT closed and USB-OTG open; simultaneous USB/converter power remains unresolved; this overview does not authorize connecting USB and converter power together. Power/ground connections for any active conditioning or controls will depend on their final circuits. [A02: power architecture](power-system.md) expands supply modes, rail responsibilities and return references.

## Future scope and validation

Additional conditioned sensors, displays, logging and a possible digital Holley interface remain optional. No expansion wiring, spare-pin assignment or timing capacity is established here. [A03: pressure measurement signal chain](measurement-system.md) expands calibration, validity handling and the separate peak/display paths. Detailed firmware and wiring remain separate work.

Before physical assembly, verify the component interfaces and power arrangement, then create the selected harness and follow the [test plan](../../docs/testing/test-plan.md). No bench or vehicle verification is claimed. Track further diagram selection in the [inventory](../DIAGRAMS.md).

## Diagram validation

Rendered and visually reviewed with Mermaid CLI 12.0.0 and Node 24.15.0. Checked label readability, signal/power distinction, branch routing and absence of clipping. This is presentation validation only. The preview remains private scratch output; the embedded Mermaid is the published source.

To reproduce, extract the Mermaid block to `gauge-system.mmd` in a scratch directory and run:

```powershell
npx.cmd --yes --package @mermaid-js/mermaid-cli@12.0.0 mmdc -i gauge-system.mmd -o gauge-system.png --size 2000 -b white
```

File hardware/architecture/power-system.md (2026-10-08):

# Gauge power architecture

A02 describes the planned power paths for the single-channel gauge using either the N16R8 bench board or the XIAO ESP32-S3. The embedded Mermaid views expand [A01](gauge-system.md). Exact pins, protection parts, fuse rating and simultaneous-power handling remain unresolved.

For the XIAO implementation, [P02](../pinouts/xiao-esp32s3.md) documents the manufacturer pin functions, USB-linked VBUS and conflicting regulator-current references. The available peripheral budget and combined-power arrangement remain unresolved.

[P06: converter interface](../pinouts/buck-converter.md) records the vendor-labeled input leads, USB-C output and converter checks needed to resolve these power paths.

The [selected N16R8 USB power plan](../components/esp32-s3-dev-board/power-plan.md) uses native USB, IN-OUT closed and USB-OTG open, with L21 supplying the shared nominal 5 V branch. This adopts the official V1.4 board-family circuit as a working assumption for the pictured V1.3 board. The input diode remains; Q05/Q12 retain actual voltage/load checks. Display VCC is selected at 3.3 V within its listed 3-5 V range (Q31).

## Supply and distribution

This view expands the converter modes and unresolved combined-source mode. The separate USB-only W01 path is defined in its [harness](../wiring/bench/README.md) and [board power plan](../components/esp32-s3-dev-board/power-plan.md); it does not pass through the vehicle converter or the unresolved combined-source boundary below.

```mermaid
flowchart TD
    vehicle["Switched vehicle supply"]
    bench["Bench DC supply: setting and limit TBD"]
    chosen["One selected DC source; not a combining circuit"]
    fuse["Input fuse: rating and location TBD"]
    protection["Input protection and filtering: design TBD"]
    converter["SSLHONG converter: nominal 5 V output"]
    railFive["5 V distribution"]
    sensor["FTP sensor: planned 5 V supply"]
    board["Selected ESP32-S3 board: verified power input"]
    railThree["Board-regulated 3.3 V: available capacity TBD"]
    adc["ADS1115 module: shared 5 V supply"]
    translator["I2C translator: separate 5 V and 3.3 V references"]
    display["GC9A01 module: selected 3.3 V supply"]
    usb["USB host: combined-source mode only"]
    usbBoundary["Simultaneous USB/converter handling: unresolved"]

    vehicle -.->|"Vehicle mode"| chosen
    bench -.->|"Bench converter mode"| chosen
    chosen ==> fuse ==> protection ==> converter
    converter ==>|"5 V"| railFive
    railFive ==> sensor
    railFive ==>|"Board input arrangement TBD"| board
    board ==> railThree
    railFive ==> adc
    railFive ==>|"High-side reference"| translator
    railThree ==>|"Low-side reference"| translator
    railThree ==>|"Selected 3.3 V VCC"| display
    usb -.-> usbBoundary
    usbBoundary -.->|"Mode-specific; verify before connecting"| board

    classDef supply fill:#fff1d6,stroke:#956000,color:#493000
    classDef load fill:#e8f3fc,stroke:#245a81,color:#142c3e
    classDef unresolved fill:#f3f3f3,stroke:#666,color:#333,stroke-dasharray:5 5
    class vehicle,bench,fuse,protection,converter,railFive,railThree supply
    class sensor,board,adc,translator load
    class display load
    class chosen,usb,usbBoundary unresolved
```

**Legend:** thick arrows are intended supply paths; dashed arrows are alternative sources, unresolved interfaces or candidate rails. All are planned, not tested. The source-selection node describes a build/operating choice, not a purchased switch, multiplexer or automatic supply-sharing circuit.

The converter's USB-C output is a power output, not the programming host. One selected controller is used per build. The sensor and ADC share regulated 5 V; the I2C translator separates its 5 V bus from ESP32 3.3 V logic. The board's 3V3 output supplies the translator low-side reference and compatible peripherals. No additional regulator is selected. Verify available current and actual distribution separately for N16R8 and XIAO. Display VCC uses board 3V3; module current/backlight behavior and rail margin remain checks.

## Returns and reference domains

```mermaid
flowchart LR
    sourceReturn["Selected DC source return"]
    inputReturn["Converter input negative"]
    outputReturn["Converter output return"]
    gaugeReference["Gauge supply return and signal reference"]
    analogReturns["FTP / conditioning / ADC returns"]
    digitalReturns["Controller / translator / display / controls returns"]
    hostGround["USB host ground: programming mode"]

    sourceReturn --- inputReturn
    inputReturn -.-|"Internal relationship: verify actual converter"| outputReturn
    outputReturn --- gaugeReference
    gaugeReference --- analogReturns
    gaugeReference --- digitalReturns
    hostGround -.-|"Additional path via selected board; assess"| digitalReturns
```

**Legend:** solid lines indicate intended return/reference relationships; dotted lines indicate relationships requiring verification. This is a logical reference view, not a prescribed star-ground layout, chassis-bond map, isolated-supply claim or wire routing. Separate analog and digital groups make noise/return-current review visible; they do not specify disconnected grounds.

Use a compatible common reference for sensor, conditioning, ADC, translator and controller as described in the [power component notes](../components/gauge-power-supply/README.md). Verify the converter's input/output return relationship and each board's USB-ground relationship before specifying physical bonds. Select the actual vehicle ground point, return conductors, splice locations and signal routing in the harness design. A USB host can add a return path; assess it with the selected power mode rather than assuming it is isolated.

## Operating modes

| Mode | Intended source | Scope and unresolved condition |
| --- | --- | --- |
| Vehicle operation | Switched vehicle supply through fuse/protection/converter | Normal target; no USB host in this baseline. Exact source, ground point and installed behavior remain unverified. |
| Bench converter evaluation | One selected bench DC source through the converter path | Input voltage/current limit must suit the actual converter and test plan. Verify unloaded output before connecting loads. |
| W01 USB development | Computer USB through N16R8 native USB | Selected operating approach: power plus programming/debugging, with converter disconnected. IN-OUT closed exposes L21 nominal 5 V; L1 supplies display/translator 3V3. Physical voltage and source/load margin remain Q05/Q12. |
| W01 standalone USB operation | Suitable standalone USB supply through N16R8 native USB | Selected alternative: disconnect computer, change source and restart. Supply selection and full-load capability remain pending; no simultaneous sources. |
| Converter-powered debugging with USB | Converter plus USB host | Unresolved: requires documented board power-path behavior and a selected backfeed/isolation strategy. Not an approved connection configuration yet. |

No onboard battery, direct bench 5 V injection or automatic source switching is selected. Q03 selects alternate USB sources for W01, with restart accepted between modes; see the [bench power requirements](../wiring/README.md#bench-power-requirements). Full-gauge USB operation is intended, not electrically verified. The distribution diagram retains the converter path for vehicle and converter evaluation work; W01 defines the selected USB-fed distribution separately, with phased electrical checks. Check signal connections to unpowered modules when choosing a test configuration.

## Rail and load responsibilities

| Domain | Intended users | Evidence / remaining work |
| --- | --- | --- |
| Vehicle/bench input | Converter through fuse and selected input conditioning | The converter's advertised 8-60 V range is a vendor claim, not automotive transient qualification; verify actual operating conditions. |
| Nominal 5 V | Selected controller's appropriate power input, shared FTP/ADS1115 branch and translator high side | Sensor requirements, converter output performance, connectors and board power path need verification. |
| Board-regulated 3.3 V | Controller internally, translator low side and compatible peripherals | Verify regulator margin, actual ADC module, I2C pull-ups and logic voltage. |
| Display supply | One GC9A01 module | 3.3 V VCC and logic selected from the purchased listing range and ESP32 compatibility; current/backlight and margin remain Q06/Q12. |
| Conditioning and controls | Depends on the chosen circuit | Passive elements need a reference; any active circuitry needs an explicitly selected supply. No extra regulator is selected here. |

The converter's advertised 5 V / 3 A output does not establish available current from a controller board's regulator. The earlier 0.5-1 A input-fuse range remains a preliminary note, not a selection. Component ratings, wire gauge, protection location and startup/operating currents must be reconciled together.

The [ADC decision](../components/adc/conditioning-review.md) removes analog divider scaling by sharing regulated 5 V between sensor and ADC. I2C translation maintains ESP32-compatible logic. Keep the sensor and ADC on the same branch; evaluate local rail differences, power transitions and translator behavior when one domain is absent. Sharing a supply does not establish ratiometric measurement or calibration accuracy because the ADS1115 uses an internal reference.

## Design and validation work remaining

1. Identify actual board revisions, power pins/connectors, USB power paths, regulator limits, display requirements and converter return relationships.
2. Measure converter output and rail noise under representative loads, including startup and display activity; record instrument, conditions and configuration.
3. Establish a power budget with measured startup/operating current and margin for the selected board, sensor, ADC and display. Do not reserve expansion capacity based only on the converter label.
4. Select fuse, wiring and input protection/filtering. Reverse-polarity and transient behavior, cranking dropout and recovery remain unresolved.
5. Resolve powered/unpowered signal behavior, grounding and USB backfeed before producing assembly-ready wiring.
6. Document and validate the selected bench configuration before deriving the separate vehicle harness. Follow the [test plan](../../docs/testing/test-plan.md) and retain [measurement records](../../data/README.md).

This architecture records current intent and pending decisions; it does not report electrical tests or define vehicle stop limits. Other diagrams remain selectable through the [inventory](../DIAGRAMS.md).

## Diagram validation

Both views were rendered and visually reviewed with Mermaid CLI 12.0.0 and Node 24.15.0. Checked labels, branching, alternative-path styling and return relationships; no clipping was observed. This validates presentation only. Previews remain private scratch output; the Markdown blocks are the published source.

To reproduce, extract the first and second Mermaid blocks to `power-system-1.mmd` and `power-system-2.mmd` in a scratch directory, then run:

```powershell
npx.cmd --yes --package @mermaid-js/mermaid-cli@12.0.0 mmdc -i power-system-1.mmd -o power-system-1.png --size 2000 -b white
npx.cmd --yes --package @mermaid-js/mermaid-cli@12.0.0 mmdc -i power-system-2.mmd -o power-system-2.png --size 1600 -b white
```

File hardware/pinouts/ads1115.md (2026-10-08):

# P03: ADS1115 module interface

**Document state: Draft.** This page maps the purchased ADC module's vendor-image header to TI ADS1115 functions for the bench and finished-gauge designs. Actual module revision, fitted IC and board connectivity remain unverified. Procurement and conditioning decisions belong in the [ADC component record](../components/adc/README.md).

## Identity and orientation

The [front image](../../media/reference/adc/adc-front.jpg) carries `GY-ADS1115/ADS1015`. This shared board marking does not identify the populated converter. Manufacturer, PCB revision and connector part number are unknown; do not infer ADS1115 resolution or timing from an I2C response alone.

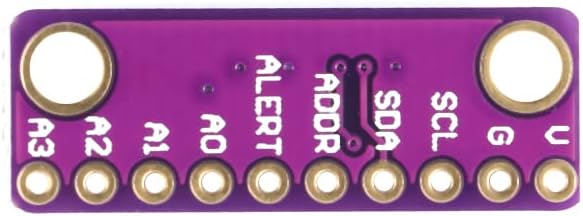
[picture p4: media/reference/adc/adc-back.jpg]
ADC module back with header labels


View the **back as pictured above**, with the two mounting holes at the top and the single ten-position header row at the bottom. Read left to right: `A3 A2 A1 A0 ALERT ADDR SDA SCL G V`. The positions below are documentation coordinates, not manufacturer pin numbers. A front-side view reverses this order; match the printed labels before wiring. Header pitch, installed connector and mating orientation require physical confirmation.

## Header map

Directions are relative to the ADC. Header order/labels have **Vendor Listing** evidence from the back image; electrical functions have **Manufacturer Spec** evidence from TI section 4, conditional on an ADS1115 and matching board traces. The shared 5 V supply and +/-6.144 V range are **Selected**; A0 wiring is planned. No row is bench verified.

| Back-view position, left to right | Printed label | ADS1115 function (IC pin) | Direction | Project voltage domain / use |
| --- | --- | --- | --- | --- |
| 1 | A3 | AIN3 (7) | Analog input | GND to VDD; future channel, unused handling TBD |
| 2 | A2 | AIN2 (6) | Analog input | GND to VDD; future channel, unused handling TBD |
| 3 | A1 | AIN1 (5) | Analog input | GND to VDD; future channel, unused handling TBD |
| 4 | A0 | AIN0 (4) | Analog input | Conditioned pressure signal, proposed single-ended input relative to GND |
| 5 | ALERT | ALERT/RDY (2) | Open-drain output | Unused in W01; a future connection needs a documented pull-up/translation arrangement |
| 6 | ADDR | ADDR (1) | Digital input | Address selection; strap and existing board bias TBD |
| 7 | SDA | SDA (9) | Bidirectional, open-drain | I2C data on 5 V side of translator |
| 8 | SCL | SCL (10) | Digital input | I2C clock from translator, 5 V side |
| 9 | G | GND (3) | Power return / reference | Shared ADC, controller and conditioning reference |
| 10 | V | VDD (8) | Power input | Shared regulated 5 V sensor/ADC branch |

Parenthesized numbers are **TI IC package pins**, from the ADS1115 column of Table 4-1 for RUG, DYN and DGS packages. They are not breakout header numbers, and the associations above still require continuity checks on the purchased module. Sources: [vendor back image](../../media/reference/adc/adc-back.jpg) and [TI datasheet, section 4](../datasheets/ads1115-datasheet.pdf#page=3).

## Power, logic and analog boundary

The design supplies this module and the FTP sensor from the same regulated 5 V branch; see [A02](../architecture/power-system.md). TI specifies a 2.0-5.5 V IC supply. Check module connections and decoupling during assembly; TI specifies 100 nF at VDD to GND. Include ADC consumption in the 5 V load budget, not the controller's 3V3 peripheral budget.

SDA and SCL connect through a bidirectional I2C voltage translator: 5 V pull-ups on the ADC side and 3.3 V pull-ups on the ESP32 side. Account for fitted module and translator pull-ups before adding resistors. TI specifies VIH >= 0.7 x VDD (3.5 V with a 5 V supply), so 3.3 V pull-ups alone do not guarantee a valid high at this ADC supply. Do not connect the two bus domains directly. The [hiBCTR BSS138 translator](../components/i2c-level-shifter/README.md) is selected under Q28 without an enable GPIO; physical pull-up/bus/power checks remain Q29. ALERT is unused with polling; any future use requires its own compatible interface. Sources: [TI sections 4, 5 and 7](../datasheets/ads1115-datasheet.pdf).

Each analog input must stay between **GND and VDD in normal operation**, regardless of PGA range. GND - 0.3 V and VDD + 0.3 V are stress limits, not design headroom. Sharing regulated 5 V with the nominal 5 V sensor removes the need for divider scaling; the initial [470 ohm / 1 uF RC filter](../components/rc-input-filter/README.md) is selected separately and does not establish arbitrary fault tolerance. Keep sensor and ADC on the same branch without independently switching one during normal use. Assess local rail differences, startup/shutdown and retained filter charge under Q17. Sources: [TI sections 5.1 and 5.3](../datasheets/ads1115-datasheet.pdf#page=4).

Select **+/-6.144 V** to cover the assumed 0-5 V sensor signal without divider scaling. Actual input remains limited by VDD. At this range the nominal LSB is 187.5 uV; single-ended readings use the positive portion of the signed conversion range. This is code spacing, not pressure accuracy. Calibrated negative pressure comes from the atmospheric reference, not a negative A0 voltage. Sources: [TI section 7.3.3](../datasheets/ads1115-datasheet.pdf#page=15) and [A03](../architecture/measurement-system.md).

## I2C address and acquisition choices

TI defines these **7-bit** addresses; they are not shifted read/write address bytes:

| ADDR connection | Address |
| --- | --- |
| GND | `0x48` |
| VDD | `0x49` |
| SDA | `0x4A` |
| SCL | `0x4B` |

The module's existing strap/bias and project address are TBD. Do not assume `0x48` or connect ADDR to a different net without checking existing board connections. TI recommends using GND, VDD and SCL selections first; SDA selection has an additional timing requirement. See [TI section 7.5.1.1](../datasheets/ads1115-datasheet.pdf#page=20).

A0 single-ended pressure acquisition is proposed. The +/-6.144 V range is selected; data rate, mode, bus speed and polling remain bring-up candidates. The [component record](../components/adc/README.md#sampling-peaks-and-calibration) owns sampling goals and calibration requirements. Record configuration with measurements and verify fresh-conversion timing; a successful bus scan alone does not confirm converter identity or performance.

[W01](../wiring/bench/README.md#adc-bring-up-candidate) now proposes N16R8 bus GPIOs, a GND address strap and an initial acquisition configuration with readiness polling. These are candidates pending module and circuit checks, not verified settings. W01 owns exact destinations; [P02: XIAO](xiao-esp32s3.md) still requires its own allocation. Optional ALERT use would add a GPIO requirement. This interface page does not assign harness connector identifiers.

## Verification before harness design

- [ ] Identify the received module and IC markings; compare conversion format and timing against the claimed ADS1115. Record each module used for calibration.
- [ ] Confirm the pictured header order, connector orientation and continuity to IC supply, ground and signal pins.
- [ ] Identify pull-up values/rails, ADDR bias and decoupling. Verify 5 V ADC supply and separate 5 V / 3.3 V bus levels through the translator before controller connection.
- [ ] Finalize conditioning, rail/fault limits, power sequencing and unused-channel handling; validate the ADC-node voltage across the intended sensor range.
- [ ] Select address, controller GPIOs, gain, rate, conversion mode and readiness method; verify communication and fresh conversions on the bench.
- [ ] Link measured results and the resulting harness. Calibrate the complete sensor/conditioning/ADC chain before interpreting pressure.

## Source reference

Electrical functions above use the preserved [TI ADS111x datasheet](../datasheets/ads1115-datasheet.pdf), **SBAS444E, December 2024**. Its [provenance and checksum](../datasheets/README.md) identify the local revision. Header evidence is the supplied vendor imagery preserved in the [component record](../components/adc/README.md#supplied-board-references); it does not establish the received board's schematic or tested behavior.

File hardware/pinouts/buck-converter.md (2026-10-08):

# P06: SSLHONG converter interface

**Document state: Draft.** This page records the pictured input leads and USB-C power output of the selected SSLHONG converter, plus the checks needed for bench and vehicle integration. Actual polarity, output performance and power-path behavior remain unverified. The [power component record](../components/gauge-power-supply/README.md) owns procurement, advertised specifications and mounting dimensions.

## Identity and connection reference

The purchased listing is SSLHONG B09NVG35CX. The supplied product label states DC-DC conversion, 8-60 V input and 5 V / 3 A maximum Type-C output. An exact model/revision beyond the listing identity is not established.

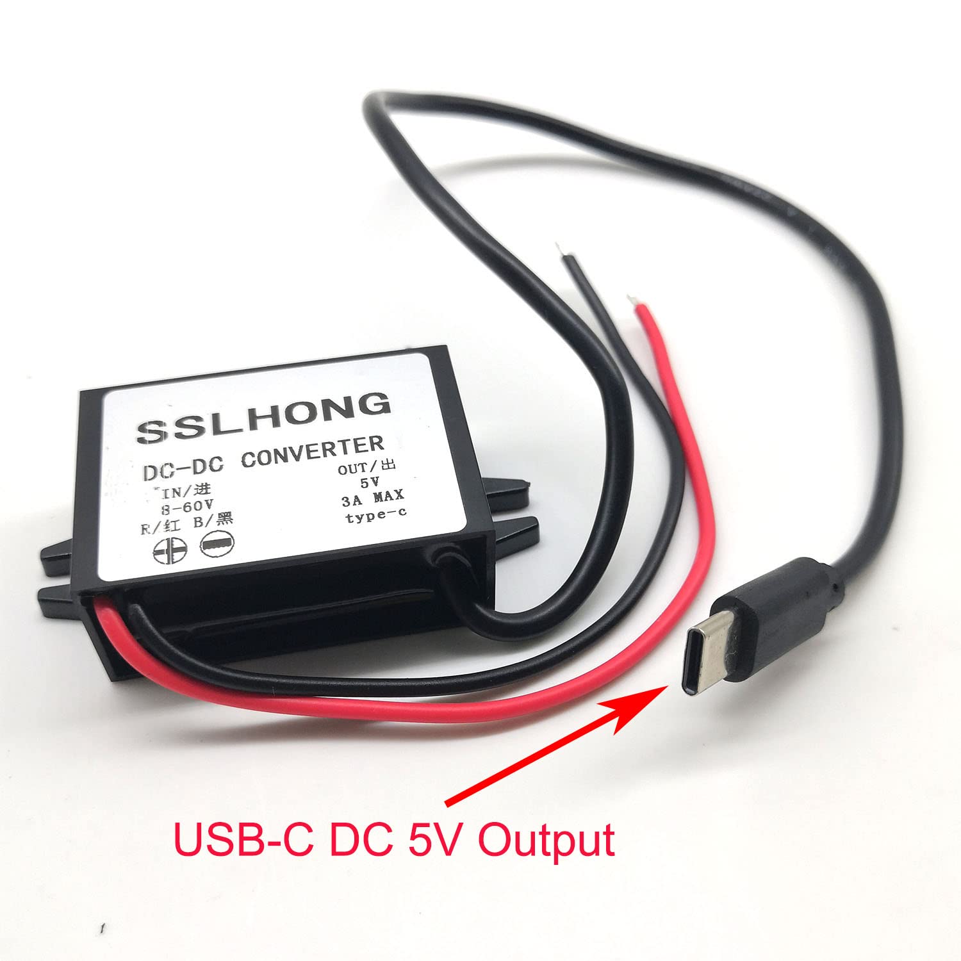
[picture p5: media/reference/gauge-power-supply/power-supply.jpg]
Vendor converter label, input leads and output plug


Use the **label-facing product view** above to identify the two separate input leads and the captive output cable. The label associates `R` / red with input positive and `B` / black with input negative. This is a vendor-labeled association, not a generic wire-color rule. Match the actual unit's label before connection. Cable position in the image does not define a terminal number.

The output is pictured as a USB-C plug. Its individual contacts, internal wiring and configuration circuitry are not established by this image. No cavity numbering or USB contact map is assigned here. If a breakout or adapter is selected, document its exact part, connector view and verified terminal mapping in the harness; do not infer its pad order from this photo.

## Interface map

Directions are relative to the converter. All pictured functions and ratings below have **Vendor Listing** evidence from the product image and [component record](../components/gauge-power-supply/README.md#published-specifications). None is bench verified.

| Connection / identification | Function | Direction | Domain / evidence limit |
| --- | --- | --- | --- |
| Separate red lead; label `R`, positive symbol | DC input positive | Power input | Advertised 8-60 VDC relative to input negative; actual unit labeling and lead specification require verification |
| Separate black lead; label `B`, negative symbol | DC input negative | Input return | Return to the selected DC source; internal relationship to output return unknown |
| Captive USB-C plug, labeled output | Regulated power delivery to the load | Power output and return | Advertised 5 VDC, 3 A maximum; actual contact wiring, tolerance and load capability unverified |
| USB-C shell and any other contacts | Functions not established by available references | Unknown | Do not treat shell as a designed return or assume data, configuration or shielding connections |

The 3 A figure is an advertised **output** limit. It does not specify input current, fuse size, usable controller `3V3` capacity or proven continuous output under installation conditions. The 8-60 V input range does not establish automotive transient qualification or behavior below 8 V during cranking.

## Power integration

Follow [A02: power architecture](../architecture/power-system.md) for source selection, returns and operating modes. The planned path is switched vehicle supply or one selected bench DC source, through the chosen fuse/input protection, into the converter. Its nominal 5 V output then supplies the designed gauge distribution. Exact source, fuse, conductors, connectors and protection remain TBD; the component record's preliminary fuse range is not a selected harness specification.

The selected ESP32-S3 board regulates the planned controller/peripheral `3V3` rail. Check the appropriate board input and power paths in [P01: bench board](esp32-s3-devkit.md) or [P02: XIAO](xiao-esp32s3.md). The sensor remains planned for 5 V subject to [P04](ftp-sensor.md); display VCC is selected at 3.3 V in [P05](gc9a01.md), with rail capacity still to verify. A USB-C plug does not by itself define how the separate sensor and display branches receive power.

A02's input/output return relationship remains unresolved. Verify it on the actual converter and document intended source, gauge and USB-host return paths. Do not claim galvanic isolation from an open continuity reading or assume a particular chassis bond from enclosure appearance.

The converter output is a power source, not the USB programming host. USB data, Power Delivery, current advertisement and attachment behavior have not been established by the supplied reference. Validate compatibility with the exact intended board or breakout, including both plug orientations where applicable. Do not connect the converter output to a host USB port or combine it with host-supplied power through an improvised adapter.

For USB-only controller bring-up, A02 keeps the converter disconnected. Converter-powered debugging with a USB host remains unresolved until the selected board and adapter power paths are documented and a backfeed strategy is selected. Reverse-current blocking and unpowered-converter behavior are not established by the converter label.

## Mechanical and harness boundary

Use the [dimension reference](../components/gauge-power-supply/README.md#mechanical-reference) when planning placement, then verify the actual mounting ears, fasteners, cable clearance and retention. Lead lengths, conductor gauge, insulation ratings, input termination and output strain relief are TBD. The advertised IP67 rating does not establish sealing of the exposed input splices, USB connection or completed gauge.

W01 and W05 will own bench and vehicle connectivity respectively; see the [inventory](../DIAGRAMS.md). Record any output breakout/pigtail and distribution connectors there, with orientation, polarity and current suitability. This page does not prescribe cable cutting or select an adapter.

## Verification before harness design

1. Identify the received converter and compare its label, input leads and output plug with the reference. Record any model/revision and differences before using the advertised ratings.
2. With power disconnected, verify the chosen test adapter's contact mapping and inspect connections for shorts. Characterize input/output return and shell relationships without treating a continuity check as an isolation qualification.
3. Define a current-limited bench source and input protection appropriate to the actual unit. Verify input polarity before energizing. Check output polarity and voltage through the intended connector/test fixture before attaching gauge electronics; record attachment conditions if output depends on a connected load.
4. Evaluate the intended load progressively. Record input voltage/current, startup behavior, output at the load, ripple, cable drop and temperature under representative conditions. Compare results with the requirements of the connected devices rather than assuming the label supplies a complete tolerance specification.
5. Check shutdown, supply interruption and recovery, including powered/unpowered signal paths. Evaluate cranking conditions within a defined test plan; do not use the vehicle or attached controller as an exploratory transient/protection test fixture.
6. Finalize the power budget, fuse, conductors, protection, return routing and USB programming arrangement from the results. Link the resulting harness and [measurement records](../../data/README.md); follow the [test plan](../../docs/testing/test-plan.md) before vehicle integration.

## Source reference

The [product image](../../media/reference/gauge-power-supply/power-supply.jpg) supplies the visible polarity and output-label evidence. The [dimension image](../../media/reference/gauge-power-supply/power-supply-dimensions.jpg) supplies mounting references. Their provenance and advertised protection claims are preserved in the [component record](../components/gauge-power-supply/README.md). No internal schematic, USB implementation specification or measured converter performance is currently recorded.

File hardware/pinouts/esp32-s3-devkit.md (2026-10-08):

# ESP32-S3 N16R8 bench-board interface

P01 documents the bench controller used by the [gauge architecture](../architecture/gauge-system.md). The header map below is transcribed from the supplied product image. Electrical functions are qualified against Espressif references where applicable; the received board, PCB revision and wiring have not been verified. The purchased board has not yet arrived; all supplied images are online references. [W01](../wiring/bench/README.md#proposed-signal-allocation) proposes project GPIO assignments, subject to actual-board verification.

## Board identity and evidence

| Item | Available evidence | Remaining check |
| --- | --- | --- |
| Purchase identifier | Amazon ASIN B0D93DLB6Q; see [component record](../components/esp32-s3-dev-board/README.md) | Identify actual PCB manufacturer and revision |
| Module marking in product image | `ESP32-S3-WROOM-1`, `N16R8` | Compare with the received module |
| Memory configuration | Espressif identifies WROOM-1-N16R8 as 16 MB quad-SPI flash and 8 MB octal-SPI PSRAM | Confirm populated variant and detected memory during bring-up |
| Header arrangement | Two rows of 22 positions in the product image | Compare every label and orientation on the physical board |
| Other visible features | Two USB-C receptacles, RST/BOOT buttons and RGB LED | USB roles, bridge chip, LED GPIO, regulator and power-path circuit |

Module specifications do not identify the carrier PCB or establish that it uses Espressif's DevKitC-1 circuit. The [Espressif module datasheet](https://www.espressif.com/sites/default/files/documentation/esp32-s3-wroom-1_wroom-1u_datasheet_en.pdf) defines the N16R8 memory configuration; it does not define this carrier's connectors or regulator capacity.

## Additional board-family references

The [bench-board evidence record](../components/esp32-s3-dev-board/bench-board-reference.md) provides additional front/back product images and annotated port/header references. They corroborate the 44-position map and suggest the YD-style family; the rear reference reads `YD-ESP32-23`, `2022-V1.3`. These are pictured markings, not a verified received revision (Q04).

In the front-view orientation below, the annotations identify left USB-C as native USB/OTG and right USB-C as CH343P USB-to-UART. Port operation and actual routing remain to be checked under Q05. Serial-console access through a UART bridge and native USB/JTAG debugging are distinct functions.

The [selected USB power plan](../components/esp32-s3-dev-board/power-plan.md) adopts the designer's V1.4 circuit as the working family reference: IN-OUT closed exposes the internal USB-fed rail at left row 21 / 5Vin; USB-OTG remains open. Native USB is selected for power and debugging (Q30). The pictured V1.3 revision is not claimed identical; routine rail/current checks remain Q05/Q12.

The [local module datasheet v1.8](../datasheets/esp32-s3-wroom-1_wroom-1u-datasheet-v1.8.pdf) preserves the manufacturer reference for N16R8 memory and module restrictions.

## Header orientation and label map

View the component side, with the antenna at the top and both USB-C receptacles at the bottom, exactly as pictured. Count each row independently from top to bottom. **Left/right and row numbers below are documentation coordinates**, not manufacturer connector designators or chip pin numbers. Looking from the solder side reverses left and right.

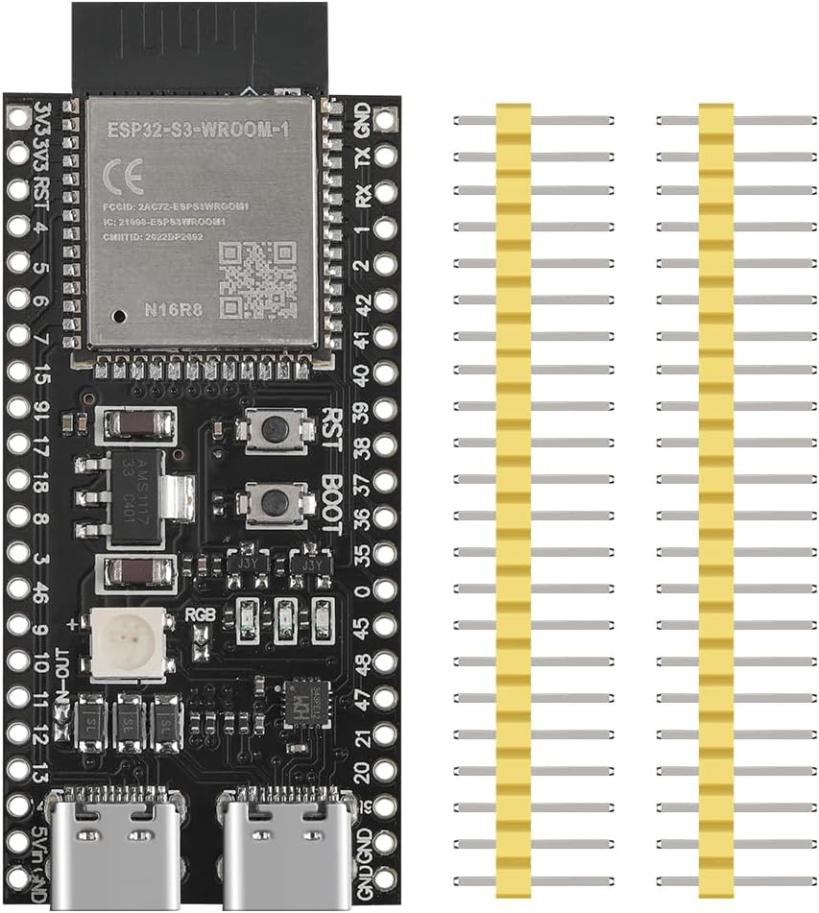
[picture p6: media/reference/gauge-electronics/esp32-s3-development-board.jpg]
Supplied product image of the N16R8 development board


Every entry in this table has **Vendor Listing** evidence: it describes the pictured silkscreen, not a continuity-tested signal. The bottom-left power label is transcribed as `5Vin`; confirm the complete label on the actual PCB before using it.

| Row from antenna end | Left label | Right label |
| --- | --- | --- |
| 1 | `3V3` | `GND` |
| 2 | `3V3` | `TX` |
| 3 | `RST` | `RX` |
| 4 | `4` | `1` |
| 5 | `5` | `2` |
| 6 | `6` | `42` |
| 7 | `7` | `41` |
| 8 | `15` | `40` |
| 9 | `16` | `39` |
| 10 | `17` | `38` |
| 11 | `18` | `37` |
| 12 | `8` | `36` |
| 13 | `3` | `35` |
| 14 | `46` | `0` |
| 15 | `9` | `45` |
| 16 | `10` | `48` |
| 17 | `11` | `47` |
| 18 | `12` | `21` |
| 19 | `13` | `20` |
| 20 | `14` | `19` |
| 21 | `5Vin` | `GND` |
| 22 | `GND` | `GND` |

Numeric silkscreen labels are interpreted as GPIO numbers by comparison with Espressif's [DevKitC-1 v1.0 header reference](https://documentation.espressif.com/esp-dev-kits/en/latest/esp32s3/esp32-s3-devkitc-1/user_guide_v1.0.html). That reference maps TX/RX to UART0 GPIO43/GPIO44 and RST to the enable/reset function. These are comparison mappings, not confirmation that the purchased carrier is an official DevKitC-1. Verify its traces or board documentation before treating this map as assembly instructions.

## Power, reset and communication interfaces

| Header location / label | Intended function and direction | Domain | Evidence and project use |
| --- | --- | --- | --- |
| Left rows 1-2 / 3V3 | Board-regulated supply output for this design | Nominal 3.3 V | Pictured labels; source selected for the I2C translator low side and compatible peripherals. Verify the two pins' relationship, actual voltage and available current. No direct external 3.3 V injection is selected. |
| Left row 21 / 5Vin | Selected USB-derived output in W01 with IN-OUT closed | Nominal 5 V after USB input diode | Board-family schematic adopted under Q30; feeds sensor, ADC and translator HV. No external supply injection selected; check actual voltage/load during bring-up. |
| Left row 22; right rows 1, 21-22 / GND | Supply return and signal reference | Ground | Pictured labels; verify common return and USB-ground relationships. |
| Left row 3 / RST | Reset/enable input | Board control signal | Comparison reference; confirm reset circuit and active level before external use. Not a spare GPIO. |
| Right row 2 / TX | UART0 transmit, comparison mapping GPIO43 | 3.3 V logic design domain | Reserve for console/programming until onboard bridge routing is established. |
| Right row 3 / RX | UART0 receive, comparison mapping GPIO44 | 3.3 V logic design domain | Reserve for console/programming until onboard bridge routing is established. |
| Right rows 20 / 19 and 19 / 20 | GPIO19 USB D- and GPIO20 USB D+ | Native USB interface | Chip functions documented by Espressif; actual USB-C routing unverified. Preserve for native USB. |
| Other numeric labels | GPIO input/output roles depend on configuration and restrictions below | 3.3 V logic design domain | W01 proposes gauge signals; header exposure does not prove availability. |

The [power architecture](../architecture/power-system.md) defines supply modes. Keep board-derived `3V3` distinct from the shared 5 V sensor/ADC supply and converter output. Display VCC is selected at 3.3 V under Q31, within its listed 3-5 V module range. Regulator margin and simultaneous USB/external-power behavior remain unresolved; selected wiring is a design assumption, not a measured rail.

## GPIO restrictions and allocation policy

Espressif's [GPIO reference](https://docs.espressif.com/projects/esp-idf/en/v5.3.3/esp32s3/api-reference/peripherals/gpio.html) identifies boot-strapping, USB and memory-interface restrictions. The policies below preserve those resources until the board and firmware configuration are known.

| Pins / pictured locations | Constraint | Allocation policy |
| --- | --- | --- |
| GPIO35, 36, 37 / right rows 13, 12, 11 | The N16R8 variant uses octal PSRAM; these module pins serve memory even though exposed on this carrier. | Exclude from gauge wiring. |
| GPIO0, 3, 45, 46 / right row 14, left row 13, right row 15, left row 14 | Boot-strapping pins; external circuits can affect startup. | Avoid for initial peripheral assignments. |
| GPIO19, 20 / right rows 20, 19 | Native USB signals. | Reserve for USB bring-up/debugging. |
| GPIO43, 44 / TX, RX | UART0 comparison mapping; possible bridge connection. | Reserve until programming/console use is resolved. |
| GPIO39-42 / right rows 9-6 | JTAG functions in the DevKitC comparison reference. | Preserve if external JTAG is needed; otherwise evaluate during pin assignment. |
| RGB LED connection | Board-family research identifies GPIO48 as a candidate; the received connection is unverified. | Reserve GPIO48 provisionally; confirm the actual circuit and RGB jumper before reuse. |

The memory restriction follows the [WROOM-1 module specification](https://www.espressif.com/sites/default/files/documentation/esp32-s3-wroom-1_wroom-1u_datasheet_en.pdf) and the chip GPIO reference. GPIO33-34 are not shown on these headers; do not infer missing pins from a generic ESP32-S3 pinout. No table here labels unallocated pins as tested or universally safe.

## Gauge interface allocation

| Interface | Required signals | Direction at controller | Assignment |
| --- | --- | --- | --- |
| ADS1115 | SDA, SCL | Bidirectional data; controller-generated clock | Proposed in [W01 controller table](../wiring/bench/generated/connections.md#proposed-controller-assignments); 3.3 V bus to translator; ADC side is 5 V |
| GC9A01 | Clock, MOSI/data, CS, DC, reset | Outputs | Proposed in W01 controller table; module logic/supply checks pending |
| Controls | Deliberate zero and peak reset | Inputs | One multifunction button selected; GPIO proposed in W01 controller table |
| ADC ready notification | ALERT/RDY if selected | Input | W01 proposes polling, leaving ALERT unwired; Q18 pending verification |
| FTP pressure signal | Analog to conditioning and ADS1115 | No direct MCU analog connection | See [measurement chain](../architecture/measurement-system.md) |

Firmware should use explicit GPIO numbers in the bench-board configuration rather than photo row numbers or XIAO aliases. Board environment, flash/PSRAM settings and shared application structure remain in the [firmware plan](../../firmware/README.md). Pinout documentation describes available interfaces; [W01](../wiring/bench/README.md) owns proposed destinations and wiring.

## Verification needed before bench assembly

1. Compare the received board labels/orientation with the listing and adopted family reference during assembly; record the build identity and any discrepancies. New photographs or independent identity authentication are not prerequisites for continuing design.
2. Obtain a schematic for that carrier if available. Verify power/ground/reset connectivity with the board unpowered, and identify regulator, USB bridge and RGB LED connections.
3. Establish supported power modes and measure 3V3 before attaching peripherals. Determine usable regulator current with the board's own consumption and intended loads included.
4. Confirm programming/console port roles, detected module memory and successful boot before using proposed I2C/SPI/control GPIOs.
5. Follow the selected power plan and W01 phase checks; record results and revise the documented assumptions if a concrete discrepancy appears.

The header transcription and cited restrictions have been reviewed as documentation. No continuity checks, power measurements, firmware builds or physical tests have been performed for P01. Purchase details remain in the [BOM](../bom/parts.md).

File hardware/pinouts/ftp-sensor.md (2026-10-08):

# P04: FTP sensor and pigtail interface

**Document state: Draft.** This page adopts a sourced GM-family terminal map for the purchased FTP sensor and HiSport pigtail. Applying the family map to the listed replacement is a working assumption. Physical fit and lead continuity are assembly checks; sensor calibration follows bring-up.

## Parts and evidence

| Item | Recorded identity | Evidence and limits |
| --- | --- | --- |
| Sensor | Aftermarket listing B0CNZ2Q1F2; cross-references 16196060 / 16238399 / 12219388 | **Working assumption based on Vendor Listing**: use this replacement family for design. Sensor is on hand and reported unmarked; no further identity check is required absent a discrepancy |
| Pigtail | HiSport listing B09NVW46W2, advertised as 13585316 | **Vendor Listing**. Three-terminal connector and leads pictured; exact housing/terminal identifiers and fit remain unverified |

The [component record](../components/fuel-tank-pressure-sensor/README.md) owns purchase details, source links, dimensions and image provenance. PT2782 and PT2646 are historical cross-references. Use advertised sensor/pigtail compatibility as the prototype basis; a separate authenticity check is not required.

The terminal reference is GM Service Information, **Document ID 1706435, page 19 of 45**, Engine Controls Connector End Views for the 2007 Cadillac Escalade / related C/K applications, preserved in an [externally hosted GM service-document copy](https://forum.efilive.com/attachment.php?attachmentid=8885&d=1282840114#page=19). It depicts the female harness connector, OEM 12059595 / service 88986451, with latch up, A at left and C at right, and assigns A low reference, B pressure signal and C 5 V reference. These reference connector numbers are not additional purchases. The page was visually checked against its table; applying it to the purchased replacement family is an explicit design inference, not a measured pinout. The external document is linked rather than republished.

## Connector views and position record

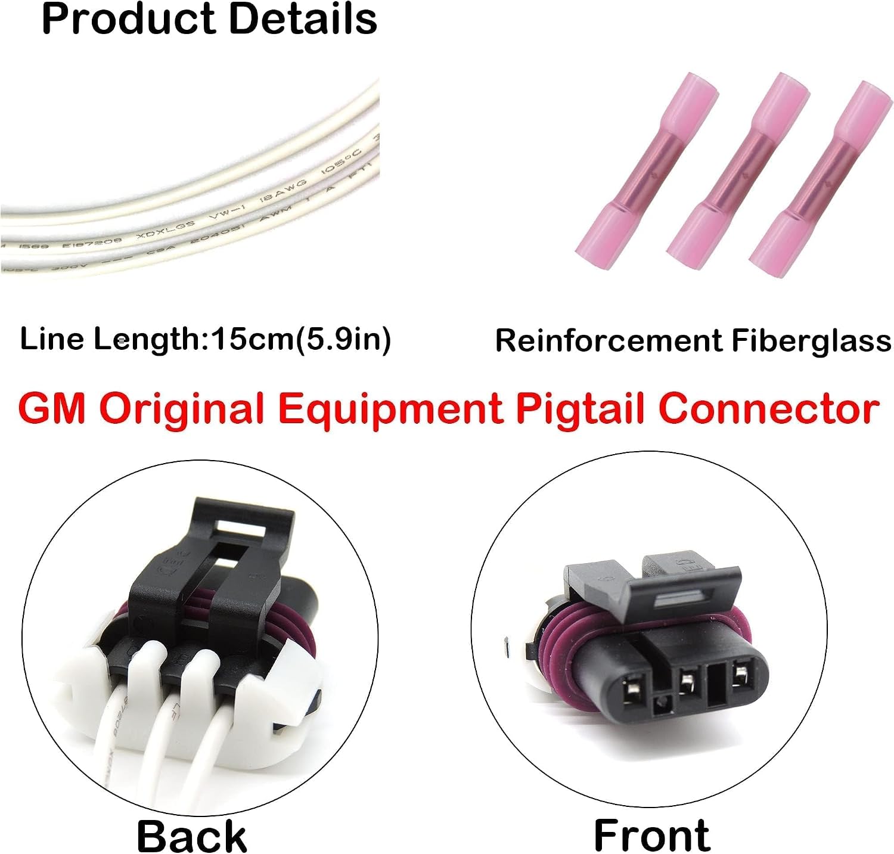
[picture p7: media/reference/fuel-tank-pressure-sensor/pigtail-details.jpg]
Vendor pigtail views


Use the lower-right **Front** inset as the pigtail **mating-face view**: look into the three terminal openings with the latch above the row. The lower-left **Back** inset shows the wire-entry side. These are angled vendor views, not orthographic connector drawings. Left and right reverse when switching between mating-face and wire-entry views while keeping the latch above the row.

The positions below use the GM female connector mating-face convention. They apply to the pigtail with its latch above the row, not the wire-entry side. A/B/C are adopted reference IDs even if the purchased housing has no readable letters.
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

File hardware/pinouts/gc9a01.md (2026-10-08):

# P05: GC9A01 display interface

**Document state: Draft.** This page maps the vendor-image header for the selected Hosyond 1.28-inch round TFT and records the electrical checks needed for one display on either ESP32-S3 controller. Actual module identity, supply compatibility and operation remain unverified. The [display component page](../components/gc9a01-display/README.md) records the selection and explains its role; the BOM owns procurement status.
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

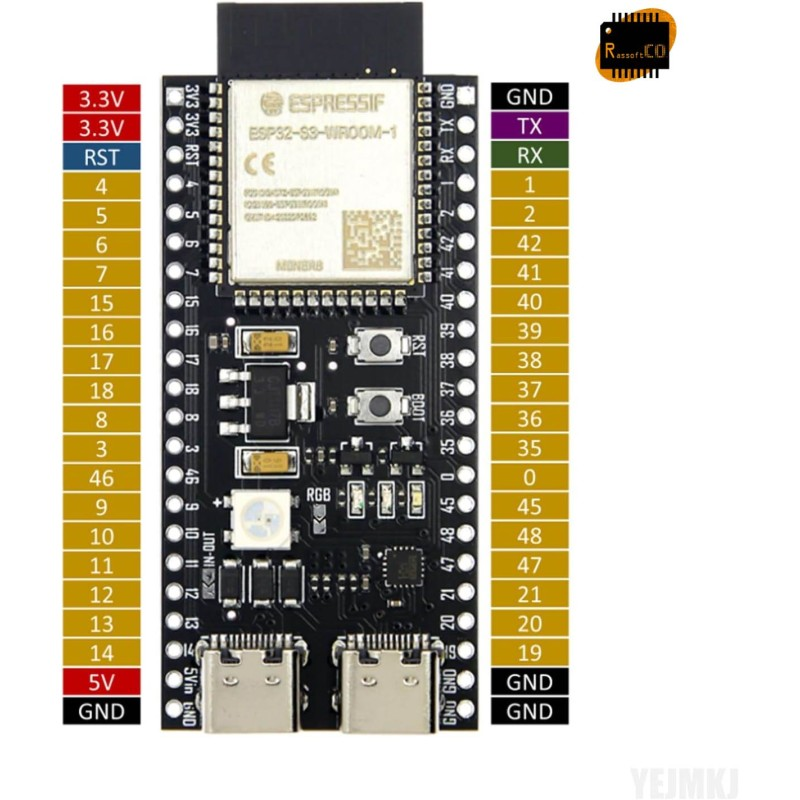
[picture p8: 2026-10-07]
media/reference/gauge-electronics/bench-board/header-reference.png

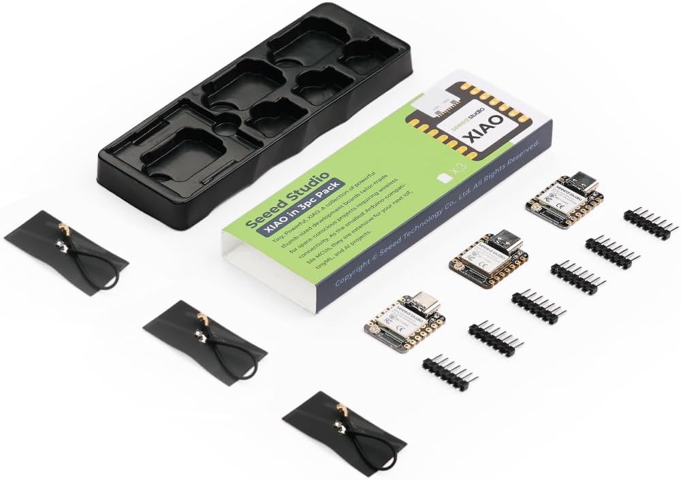
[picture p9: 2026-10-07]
media/reference/gauge-electronics/xiao-esp32s3-pack.jpg

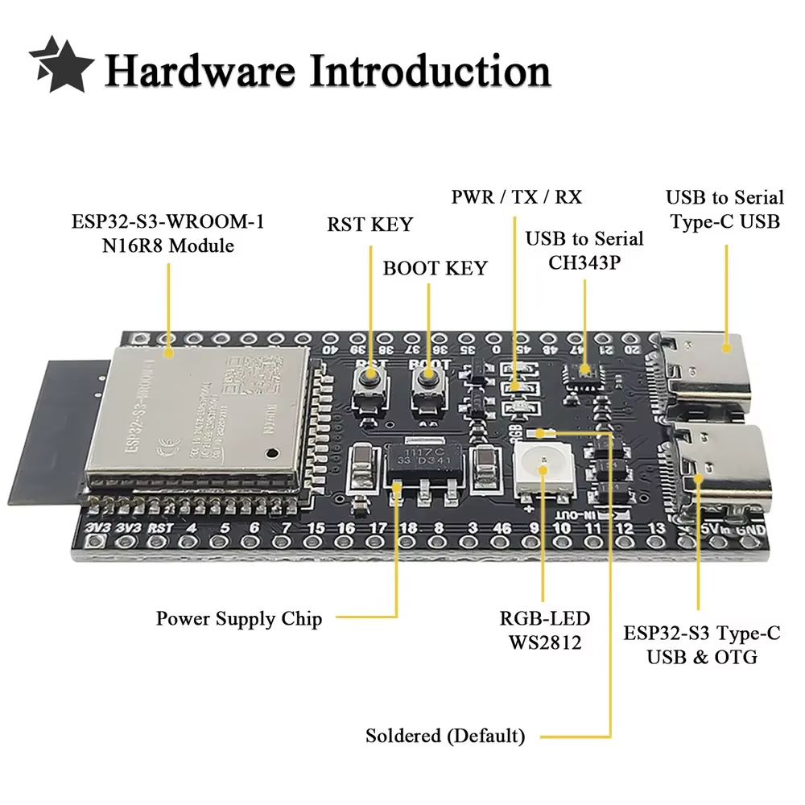
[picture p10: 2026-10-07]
media/reference/gauge-electronics/bench-board/hardware-introduction.png

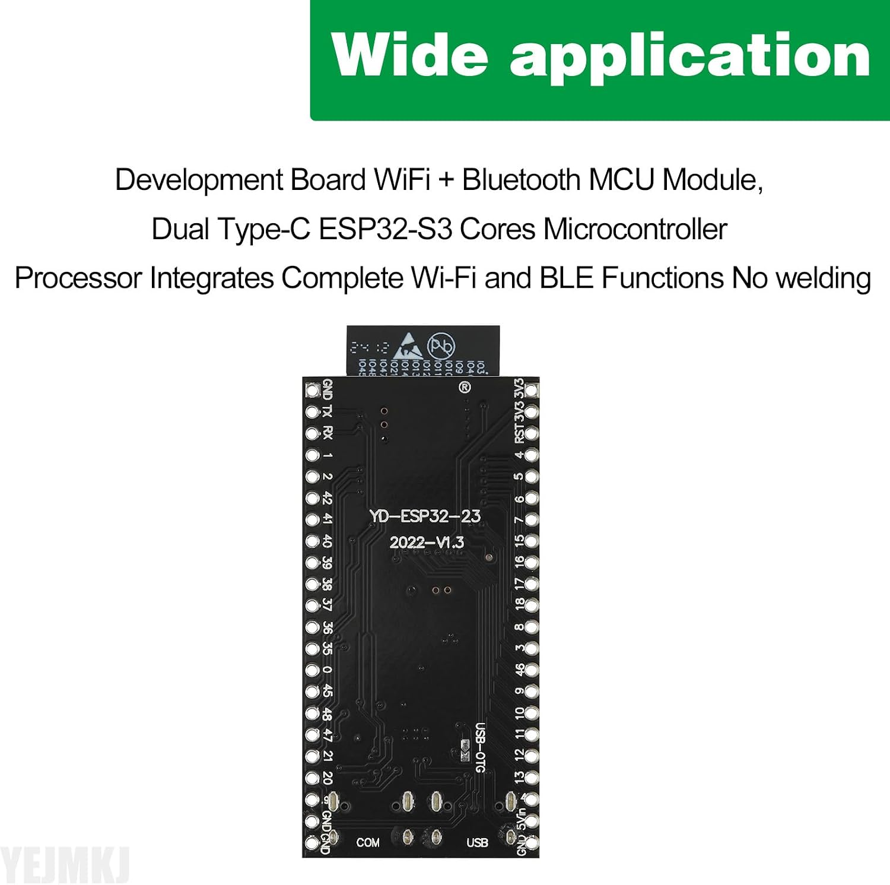
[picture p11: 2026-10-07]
media/reference/gauge-electronics/bench-board/board-back-reference.png

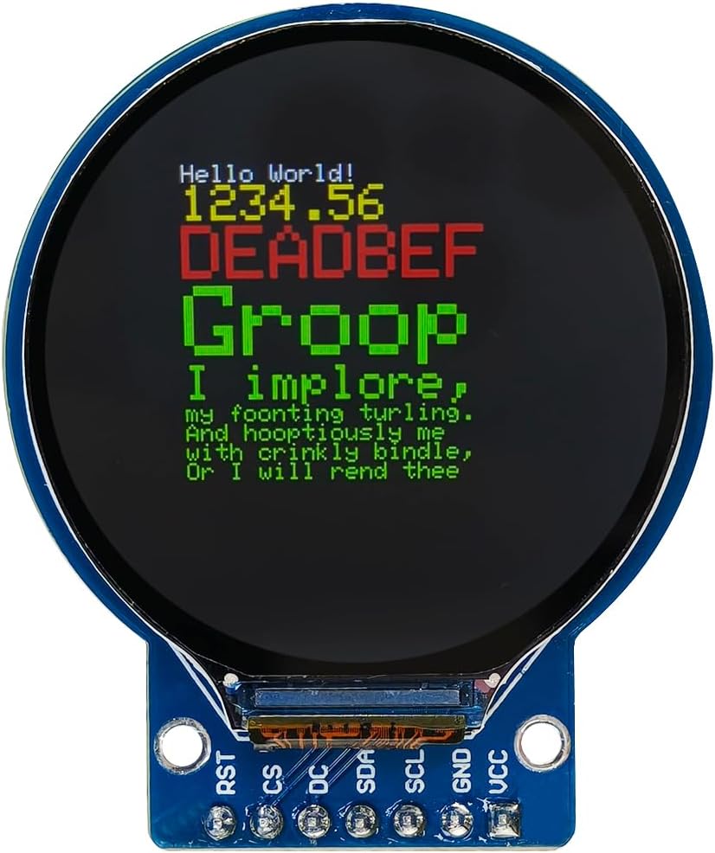
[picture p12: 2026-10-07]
media/reference/gauge-electronics/gc9a01-display.jpg

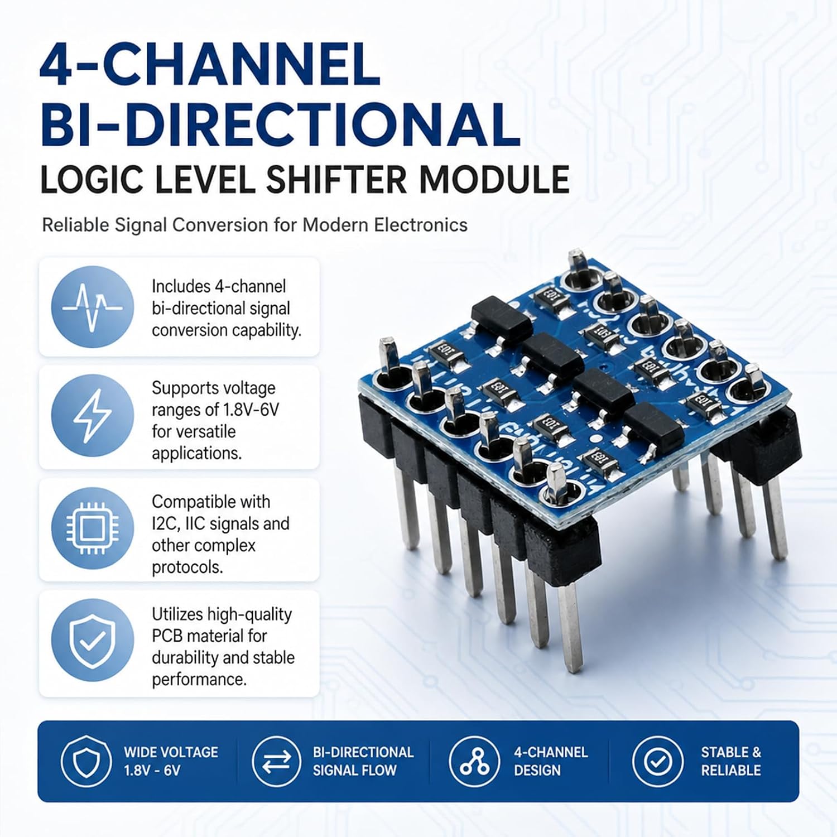
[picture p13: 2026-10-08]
media/reference/i2c-level-shifter/module-overview.jpg

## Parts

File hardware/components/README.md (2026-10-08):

# Hardware components

Component-specific descriptions, design decisions, integration notes and import records belong in `hardware/components/<component>/`. Each component or closely related group has a `README.md` as its entry point.

Read a component page first to understand its job and operating principle, then follow its links to exact interfaces, wiring and tests. The [documentation improvement plan](../../docs/component-documentation-plan.md) tracks the instructional pass and adopted electronics organization.

| Component or group | Contents |
| --- | --- |
| [Gauge electronics](gauge-electronics/README.md) | Integration guide and reading/building path |
| [N16R8 development board](esp32-s3-dev-board/README.md) | Bench controller, memory, power/debugging and board evidence |
| [XIAO ESP32-S3](xiao-esp32s3/README.md) | Compact controller, pin aliases, power and firmware configuration |
| [GC9A01 display](gc9a01-display/README.md) | TFT/SPI concepts, module selection and readability |
| [I2C level shifter](i2c-level-shifter/README.md) | Digital bus translation, purchased module, terminals and pull-ups |
| [RC input filter](rc-input-filter/README.md) | Built resistor/capacitor circuit, operating principle, values and assembly |
| [ADC](adc/README.md) | ADS1115 modules, conditioning and acquisition requirements |
| [Pressure sensor and pigtail](fuel-tank-pressure-sensor/README.md) | Selected FTP sensor, connector references and calibration prerequisites |
| [Gauge power supply](gauge-power-supply/README.md) | Converter specifications, integration and mounting references |
| [Check valve / relief valve](check-valve-relief-valve/README.md) | Relief component, published specifications and validation needs |

## Adding a component

Create a descriptive lowercase kebab-case folder here and add it to this index. A component may be a purchased module or a built subassembly such as the RC input filter; document its function either way. For built circuits, record the internal connectivity and design values, while the BOM distinguishes constituent stock parts from purchases. Explain the component's purpose, selected design, source evidence and unresolved integration details. Keep closely related items together when they share a useful record; create additional subfolders only with content that needs them.

Lead with what the component is, how it works and why the project uses it. Define new terminology and include a practical example when useful. Explain the important interface implications and link to the pinout/harness for exact connections. Label example values as hypothetical, separate published claims from measurements, and keep purchase/import history after the instructional and design material. This approach also applies to mechanical components and future firmware or assembly guides.

Use the shared hardware categories for other artifacts: [architecture](../architecture/README.md), [pinouts](../pinouts/README.md), [wiring](../wiring/README.md), [schematics](../schematics/README.md), [BOM](../bom/parts.md), and [datasheets](../datasheets/README.md). Link to these records from the component page. Purchase inventory belongs in the BOM; native CAD belongs under `cad/`; product reference images remain under `media/reference/<component>/`.

The [hardware index](../README.md) defines the overall organization. Component folders belong here rather than directly under `hardware/`.

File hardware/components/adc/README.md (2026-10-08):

# ADS1115 acquisition modules

In the PCV/crankcase-pressure monitor we’ve been designing, the **ADS1115 is there primarily because we care about accurately measuring very small changes in the FTP sensor’s analog voltage**. It sits between the pressure sensor and the ESP32.

The basic chain is:

**Crankcase pressure → FTP sensor → analog voltage → ADS1115 → digital I²C data → ESP32 → display/logging**

### What the ADS1115 actually is

The ADS1115 is a **16-bit analog-to-digital converter (ADC)**. It has four analog inputs, an internal voltage reference, a programmable gain amplifier (PGA), and communicates with the ESP32 digitally using I²C. TI specifies up to 860 samples/sec and four single-ended analog channels. [Texas Instruments](https://www.ti.com/product/ADS1115?DCM=yes\&ds_k=ADS1115+Datasheet\&utm_source=chatgpt.com)

So when the FTP sensor says something like:

> "The pressure I'm seeing corresponds to 2.487 volts."

the ADS1115 measures that voltage very precisely and sends a number to the ESP32.

The ESP32 then applies our calibration equation:

$$
V_{\text{sensor}} \rightarrow P_{\text{crankcase}}
$$

and gives us something useful such as:

**−1.8 inH₂O**<br>
or<br>
**−4.5 mbar**<br>
or<br>
**−0.065 PSI**

depending on how we decide to display it.

---

## Why not just connect the FTP sensor to the ESP32?

The ESP32 has ADC inputs, so a design could use them with suitable input conditioning. The 5 V sensor output cannot simply be connected to a 3.3 V input.

The ESP32-S3 already contains ADC inputs.

But crankcase pressure is a particularly good application for the ADS1115 because we're looking for **small pressure differences around atmospheric pressure**, not something enormous like 0–100 PSI.

For example, imagine the FTP sensor operates over roughly a 0.5–4.5 V range. A very small crankcase-pressure change might only move its output by a few millivolts.

For a simplified comparison, a 12-bit converter spanning 0-3.3 V would have nominal code spacing of:

$$
\frac{3.3V}{4096} \approx 0.806\,mV/\text{count}
$$

This calculation is an illustration, not a characterization of the ESP32-S3's actual input range or accuracy, which also depends on attenuation, calibration, noise and nonlinearity.

The ADS1115 gives us **16-bit conversion plus a precision internal reference and PGA**. TI specifically designed it for precision sensor measurement. [Texas Instruments](https://www.ti.com/product/ADS1115?DCM=yes\&ds_k=ADS1115+Datasheet\&utm_source=chatgpt.com)

At the ±6.144 V range, for example, the ADS1115 scale is about:

$$
187.5\,\mu V/\text{count}
$$

or:

**0.1875 mV per count.**

That is finer code spacing than the simplified 12-bit comparison. **Resolution is not accuracy:** a smaller voltage step does not remove sensor error, noise or calibration error. The complete chain still needs the project's calibration procedure.

And at lower PGA ranges, the ADS1115 gets even more sensitive.

---

# The "amplifier" part is a little misleading

The Amazon description calling it an **"Amplifier Module"** can make it sound like we're using it to boost the FTP sensor's voltage.

We're not, really.

The ADS1115 has a **Programmable Gain Amplifier (PGA)** internally. It changes the measurement range of the converter.

TI gives these programmable full-scale ranges:

- ±6.144 V
- ±4.096 V
- ±2.048 V
- ±1.024 V
- ±0.512 V
- ±0.256 V [Texas Instruments](https://www.ti.com/lit/ds/symlink/ads1115.pdf?utm_source=chatgpt.com)

Suppose we were measuring a signal that only moved between 0 and 0.5 V.

Instead of wasting most of the ADC's available measurement range, we could configure it for ±0.512 V and get much greater effective resolution.

That's what the "gain" feature is doing.

It **does not produce a boosted analog output** for us.

---

# Why this matters especially for the PCV system

The goal isn't merely:

> "Do I have vacuum?"

We want to characterize what the PCV system is actually doing with the engine, the catch can, and the interchangeable restrictors.

We want to eventually be able to log things like:

| Engine condition | Crankcase pressure |
|---|---:|
| Engine off | ~0 relative pressure |
| Warm idle | Negative pressure in inH2O; value to measure |
| 1,700 RPM cruise | Signed pressure in inH2O; value to measure |
| Deceleration | Signed pressure in inH2O; value to measure |
| Wide-open throttle (WOT) | Signed pressure in inH2O; value to measure |
| 3 mm restrictor | X |
| 2 mm restrictor | X |
| 4 mm restrictor | X |

That's considerably different from simply installing an idiot light.

As a **hypothetical comparison, not project measurements or acceptance targets**, consider:

**2 mm restrictor:** -7 inH2O at idle<br>
**3 mm restrictor:** -3 inH2O at idle<br>
**4 mm restrictor:** -1 inH2O at idle<br>
**Wide-open throttle:** +5 inH2O

that's extremely useful information.

Compare measured pressure with manifold absolute pressure (MAP), engine speed (RPM) and operating condition to evaluate restrictor sizing. The hypothetical values above do not predict how the actual variants will behave.

The ADS1115 provides the voltage measurements for these comparisons; sensor calibration and repeatable test conditions determine whether the pressure results are meaningful.

---

# Think of each piece this way

In our system:

**FTP sensor = pressure → electricity**

It physically senses the crankcase pressure and generates an analog voltage.

**ADS1115 = electricity → accurate number**

It measures that voltage accurately.

**ESP32-S3 = number → intelligence**

It converts voltage into pressure, applies calibration, filters the reading, drives the display, logs data, possibly communicates over Wi-Fi/Bluetooth, etc.

So:

```text
        PCV / Catch Can
              │
              │ pressure tap
              ▼
        ┌─────────────┐
        │ FTP Sensor  │
        └──────┬──────┘
               │
         Analog voltage
               │
               ▼
        ┌─────────────┐
        │   ADS1115   │
        │  16-bit ADC │
        └──────┬──────┘
               │
              I²C
         SDA + SCL
               │
               ▼
        ┌─────────────┐
        │  ESP32-S3   │
        └──────┬──────┘
               │
        Calculate pressure
        filter / log / display
```

---

## There's one important electrical issue we need to handle

This is the piece we particularly want to remember when we wire the bench.

**The ADS1115's programmable ±6.144 V range does NOT mean we can put 6.144 V into it regardless of its power-supply voltage.**

The allowable analog input voltage is constrained by the ADC's supply rails.

The ADS1115 itself can operate from **2.0–5.5 V**. [Texas Instruments](https://www.ti.com/product/ADS1115?DCM=yes\&ds_k=ADS1115+Datasheet\&utm_source=chatgpt.com)

So if our FTP sensor is powered from 5 V and is capable of producing approximately **0.5–4.5 V**, we can't casually do this:

```text
5V FTP sensor
     │
0.5-4.5V output
     │
     ▼
ADS1115 powered at 3.3V   ← problem
```

because the sensor can produce a voltage above the ADS1115's 3.3 V supply.

We need to deliberately choose the architecture.

### One good architecture

The selected bench and gauge architecture is:

```text
              regulated 5V
                 │
        ┌────────┴─────────┐
        │                  │
        ▼                  ▼
   FTP Sensor          ADS1115
        │                  │
        └── 0.5-4.5V ─────► A0
                           │
                           │ I²C
                           ▼
                     level shifting
                           │
                         3.3V
                           │
                           ▼
                       ESP32-S3
```

That lets the ADS1115 comfortably measure the entire sensor output.

The **SDA/SCL lines must not feed 5 V into the ESP32's 3.3 V GPIO**. Use a bidirectional I²C translator, with pull-ups in each voltage domain. At a 5 V supply the ADS1115 requires a logic high of at least 3.5 V, so moving its pull-ups to 3.3 V alone is not a guaranteed interface. The [hiBCTR BSS138 module](../i2c-level-shifter/README.md) is selected under Q28; physical pull-up and bus checks remain Q29.

There are other valid ways to build it, including running the ADS1115 at 3.3 V and scaling the FTP output with a resistor divider.

---

## And we get three extra analog channels for free

That's another reason I like it for the project.

The ADS1115 gives us:

**A0, A1, A2, A3**

We're presently using one for crankcase pressure.

That leaves three precision analog channels available for future experimentation.

For example:

```text
ADS1115
│
├─ A0 → Crankcase FTP pressure
├─ A1 → Future sensor
├─ A2 → Future sensor
└─ A3 → Future sensor
```

So we could eventually measure another pressure transducer, battery/system voltage through an appropriate divider, a second PCV pressure point, or some other analog diagnostic channel.

---

### The shortest explanation

If someone asked why the thing is in the PCV controller, I'd say:

> **The FTP sensor produces an analog voltage representing crankcase pressure. The ADS1115 is a high-resolution 16-bit ADC that accurately measures that voltage and sends the result digitally to the ESP32. We use it instead of relying on the ESP32's comparatively crude onboard ADC because we're trying to measure very small crankcase pressure changes accurately.**

# ADS1115 Module Selection

Selected external ADC: **ADS1115 modules**, [Amazon B0BXDLZLZS](https://www.amazon.com/dp/B0BXDLZLZS). Supplied notes confirm **three modules purchased for USD 5.98 total**. Planned allocation is one bench module, one finished-gauge module, and one spare/expansion module. The modules have not yet arrived; chip identity and operation remain unverified.

The intended measurement path is FTP sensor, input filtering/protection, ADS1115 on 5 V, then translated I2C to ESP32-S3. The controller handles calibrated pressure, peak tracking, and display rendering. An external ADC keeps the acquisition design consistent between the N16R8 bench board and XIAO controller; changing the actual ADC or analog circuit still calls for calibration review.

See [A01: overall gauge architecture](../../architecture/gauge-system.md) for the ADC between analog conditioning and the controller, with signal and power boundaries distinguished.

See [A03: pressure measurement signal chain](../../architecture/measurement-system.md) for how conversion counts become calibrated pressure, validity state, peaks and display values.

See [P03: ADS1115 module interface](../../pinouts/ads1115.md) for header orientation, terminal functions, address options and electrical verification before wiring.

## Device specification reference

The exact reference revision is stored as the [local ADS111x datasheet](../../datasheets/ads1115-datasheet.pdf). See the [datasheet index](../../datasheets/README.md) for document identity, provenance, and checksum; retain the official TI links below for checking updates.

TI specifies the ADS1115 as a 16-bit delta-sigma ADC with a multiplexer for four single-ended or two differential measurements, programmable gain, internal reference/oscillator, and four selectable I2C addresses. Supply range is 2.0-5.5 V; the IC temperature range is -40 to +125°C. These IC specifications do not qualify the purchased breakout assembly. Reference: [TI ADS111x datasheet, SBAS444E, December 2024](https://www.ti.com/lit/ds/symlink/ads1115.pdf), consulted 2026-10-06.

Nominal output rates are **8, 16, 32, 64, 128, 250, 475, and 860 SPS**. The PGA range does not permit analog inputs beyond the supply rails in normal operation. Inputs are multiplexed, so the maximum conversion rate is not available independently on every channel at once. See sections 5.3, 7.3, and 8 of the [TI datasheet](https://www.ti.com/lit/ds/symlink/ads1115.pdf).

## Supplied board references

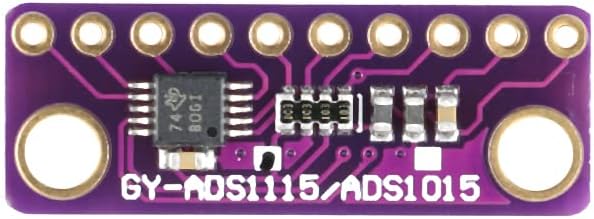
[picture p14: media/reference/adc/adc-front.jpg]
Vendor ADC front view


Vendor ADC back view

The front silkscreen says `GY-ADS1115/ADS1015`, which does not establish which device is populated. Verify the received IC and behavior before relying on ADS1115 specifications. The rear image labels `V`, `G`, `SCL`, `SDA`, `ADDR`, `ALERT`, and `A0` through `A3`. These vendor views do not establish the actual board schematic, pull-up supply, address configuration, or ESP32 GPIO assignments.

See the [N16R8](../esp32-s3-dev-board/README.md), [XIAO](../xiao-esp32s3/README.md) and [GC9A01](../gc9a01-display/README.md) introductions for how computation and display complement ADC acquisition. The [integration guide](../gauge-electronics/README.md#reading-and-building-path) provides a reading and assembly path.

## Preliminary electrical plan

- **Selected:** power the ADS1115 and FTP sensor from the same regulated nominal 5 V branch. This supersedes the earlier controller-3V3 ADC supply.
- Keep the ESP32 I2C side at 3.3 V and add a bidirectional I2C level translator to the ADC's 5 V side. The hiBCTR BSS138 module is selected under Q28; fitted pull-up and bus checks remain Q29; no direct 5 V bus connection to the ESP32 is intended.
- Use A0 single-ended for pressure and **+/-6.144 V full-scale range** for the assumed 0-5 V signal. Analog voltage must still remain between ground and ADC VDD; the range setting does not permit a 6.144 V input on a 5 V-powered part.
- Remove analog divider scaling from the baseline. Use the initial [470 ohm / 1 uF RC input filter](../rc-input-filter/README.md). Stock parts, response and power/protection behavior remain Q17. TI's 100 nF supply decoupling recommendation is separate from the A0 signal capacitor.
- ADDR-to-GND / 0x48, single-shot 128 SPS and readiness polling remain W01 bring-up candidates. ALERT stays unused.

The [conditioning review](conditioning-review.md) owns this decision, its rationale and remaining implementation work. It applies to the N16R8 bench and XIAO target; each still needs its own power distribution and GPIO configuration. [P03](../../pinouts/ads1115.md) describes the two voltage domains. The purchased module has not arrived; normal assembly checks confirm its connections against the listing.

## Sampling, peaks, and calibration

The notes propose approximately 100-200 samples/sec for acquisition and 20-30 display updates/sec. These are goals, not measured performance or final configuration. Choose a supported conversion rate (128 SPS lies within the proposed acquisition range), then measure effective throughput and peak response. Polling faster does not create new conversions. Channel expansion and display work must not silently reduce the pressure sample rate.

Keep peak capture separate from display smoothing, and evaluate the entire sensor, analog filter, ADC, and software response before claiming short spikes are captured. Resolution alone does not establish pressure accuracy or noise performance.

Calibrate the complete installed sensor/filter/ADC chain against a known pressure reference. Preserve raw counts, gain/rate/channel settings, module identity, analog component values, and calibration revision. Zero, slope, noise, linearity, and repeatability require measurement; a new module is not automatically interchangeable without rechecking calibration.

Future options include additional conditioned sensors, multiple displays, or additional addressed ADC modules. The notes prefer obtaining MAP digitally from Holley rather than using an analog channel; no Holley interface is implemented or verified. These options do not expand the initial one-pressure-channel scope.

## Import record - 2026-10-06

Imported project notes and two third-party product images from batch `ADC`. Public images are in `media/reference/adc/`; purchase details and selections are reflected in the [BOM](../../bom/parts.md), [gauge plan](../../components/gauge-electronics/README.md), and [firmware plan](../../../firmware/README.md).

Reviewed visible images for personal identifiers; none were observed. Removed embedded JPEG application/comment metadata without recompression, verifying unchanged orientation, dimensions, and decoded pixels. Preserved product labels; inbox originals remain unchanged. Product URL uses the canonical ASIN path.

Reviewed TI's supply, logic thresholds, gain scaling and input constraints for the shared 5 V design. No physical wiring, calibration, electrical testing or firmware build was performed. The [test plan](../../../docs/testing/test-plan.md) remains the basis for physical validation.

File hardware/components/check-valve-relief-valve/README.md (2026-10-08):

# Check valve / proposed pressure relief

## One-way flow and pressure relief

A **check valve** permits flow in one direction and resists flow in the reverse direction. In a spring-loaded design, forward pressure must overcome the closing force before the valve begins to open. That differential pressure is called **cracking pressure**. It is different from the pressure rating of the valve body and from the pressure needed to pass a useful flow rate.

This project proposes using the purchased check valve on a catch-can branch directed outward to atmosphere. During crankcase vacuum, that branch should remain closed rather than admitting unmetered air. During positive pressure, a suitably low opening threshold could provide an additional outward path. The restricted intake-vacuum branch remains a separate path; the relief valve does not meter normal manifold-vacuum evacuation.

### Why a check valve is still only a relief candidate

A one-way fuel valve is not automatically a characterized crankcase pressure-relief device. Its opening threshold, flow capacity, reverse leakage and behavior in vapor all matter here. A valve might begin opening at an acceptable pressure yet still require substantially more pressure to pass the required flow.

The supplied vendor image advertises 0.5 PSI cracking pressure, approximately **13.8 inH2O**. The project's provisional relief target is approximately **2.77 inH2O** (0.1 PSI). That difference explains the interest in characterization and possible spring changes; it does not establish a suitable modification. Reducing spring force can also change closure and leakage, so opening, reseating and reverse-flow checks belong together in the [bench-test plan](../../../docs/testing/test-plan.md).

The lesson for this component is to separate **direction**, **opening pressure** and **flow capacity**. None can be inferred solely from the hose size or maximum-pressure claim. The supplied internal illustration below is evidence of advertised construction, not a measured spring specification.

## Selected hardware

Purchased item: **EVIL ENERGY 1/2 in (12 mm) aluminum one-way fuel check valve**, black, three-piece pack with hose clamps, Amazon ASIN **B0FQJ71WZW**. Three valves were purchased for **USD 18.04 total**. See the [BOM](../../bom/parts.md).

This check valve is a candidate for the separate catch-can-to-atmosphere relief path. Receipt, disassembly, modification, installation, and bench performance have not been confirmed.

See [A04: PCV system overview](../../architecture/pcv-system.md) for the outward-only relief branch from the catch can to atmosphere and its relationship to the restricted intake return.

## Vendor reference images

These product-listing illustrations accompany the [Amazon listing](https://www.amazon.com/dp/B0FQJ71WZW). They are vendor claims, not inspection photographs of the purchased units or independent verification. Source branding and visible labels are preserved; images are third-party reference material, not project-created artwork.

### Published specifications

The supplied illustration states 6061-T6 aluminum, an anodized finish, **0.5 PSI opening pressure**, and **87 PSI maximum pressure**. The maximum-pressure claim is not an opening setting or evidence of adequate relief flow.

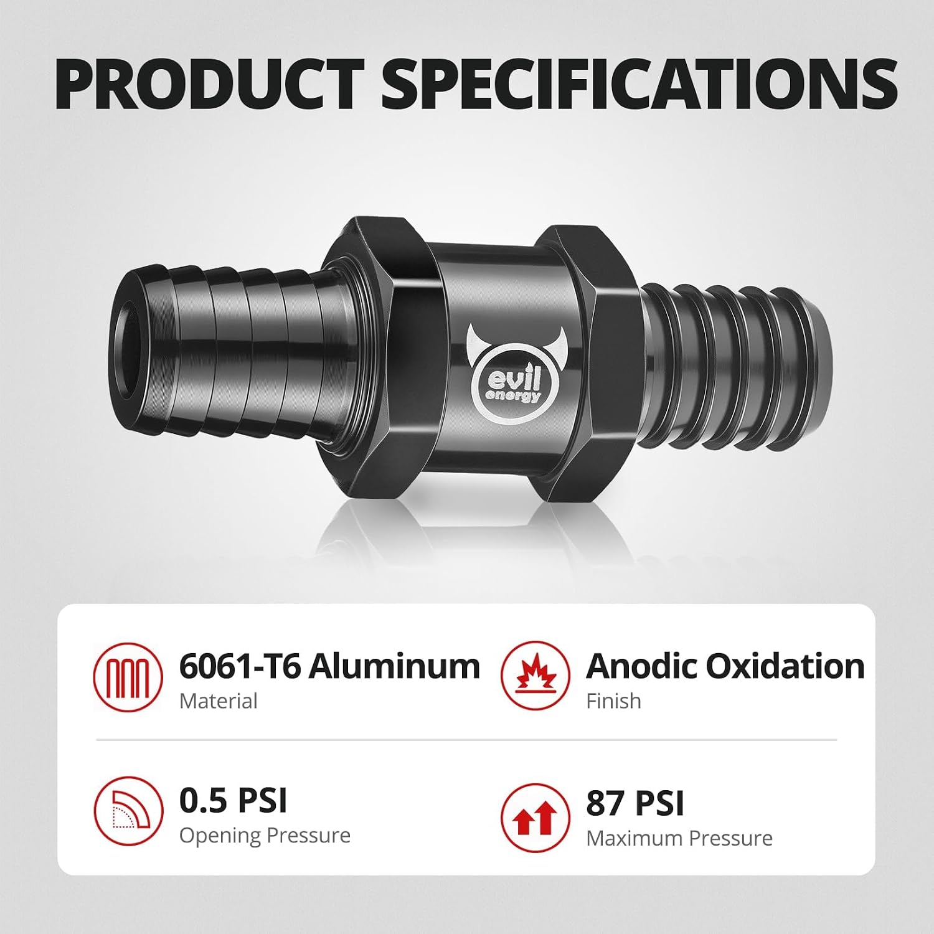
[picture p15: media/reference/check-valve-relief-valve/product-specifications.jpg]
Vendor specification illustration


### Internal construction

The exploded illustration labels an aluminum body, NBR O-ring, NBR gasket, and 304 stainless steel spring. Actual component dimensions and materials have not been inspected or verified.

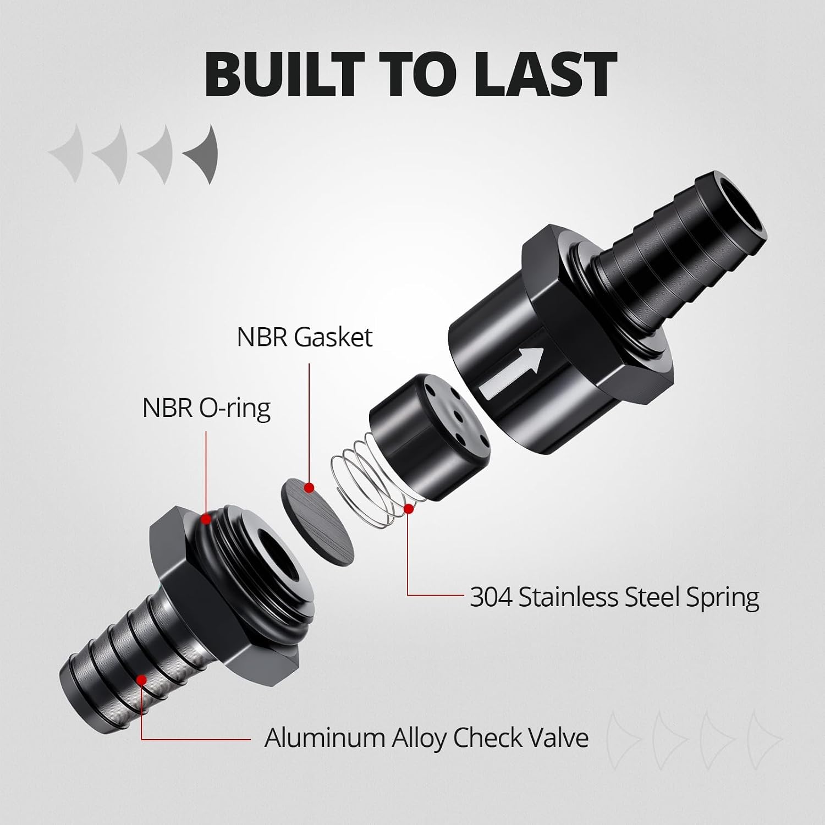
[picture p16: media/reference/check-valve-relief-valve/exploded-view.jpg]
Vendor exploded illustration


### Compatibility claims

The vendor illustration lists oil, coolant, air, diesel, methanol, ethanol, and E85. These claims do not establish durability or sealing performance in this project's crankcase-vapor environment.

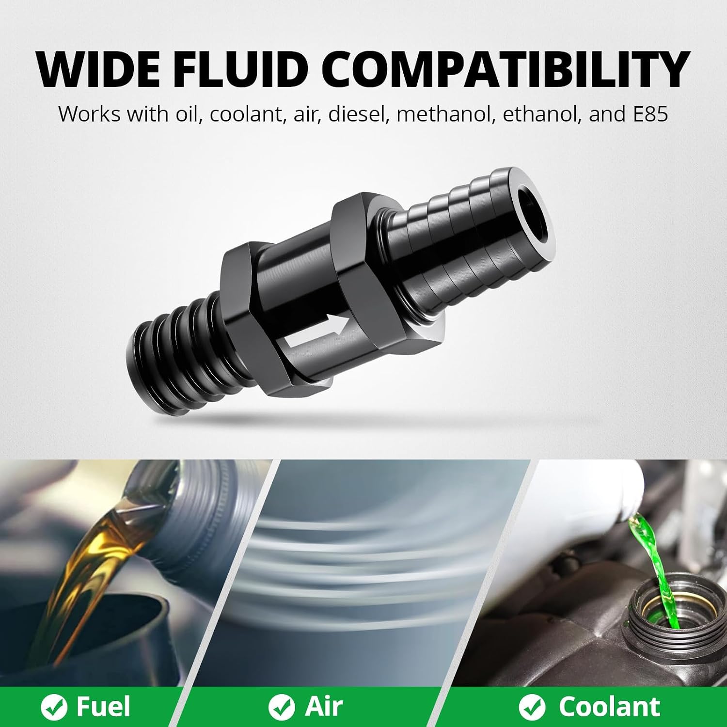
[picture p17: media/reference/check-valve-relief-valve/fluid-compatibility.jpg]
Vendor fluid compatibility illustration


## Validation still required

The listed 0.5 PSI opening pressure is approximately 13.8 inH2O, above the project's provisional relief-opening target of approximately 0.1 PSI (2.77 inH2O). The images support the origin of the published claim; they do not establish the purchased valves' actual cracking pressure.

Follow the [relief bench-test plan](../../../docs/testing/test-plan.md): confirm flow direction, measure opening/reseating pressure and reverse leakage, record any spring changes, and assess flow capacity separately. No spring change or acceptance of this valve as a validated relief device is implied by this import.

## Import record - 2026-10-06

Imported all three images from supplied batch `check-valve-relief-valve`. Inbox originals remain unchanged. Public copies use descriptive filenames under `media/reference/` to distinguish vendor illustrations from project photographs and CAD views.

| Supplied filename | Public filename |
| --- | --- |
| `713ecekBA6L._AC_SL1500_.jpg` | `product-specifications.jpg` |
| `61a4Vq6yuwL._AC_SL1500_.jpg` | `exploded-view.jpg` |
| `71h2DoDb4aL._AC_SL1500_.jpg` | `fluid-compatibility.jpg` |

Reviewed visible content for personal identifiers; none were observed. Removed JPEG application/comment metadata, preserving orientation and decoded pixels without recompression. Verified image decoding, dimensions, pixel equality, and absence of embedded metadata in the public copies. No visual redactions, generative edits, or physical tests were performed.

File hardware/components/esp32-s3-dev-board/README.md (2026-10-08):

# ESP32-S3 N16R8 bench development board

## What the board does

This board runs the bench gauge program: it reads the ADS1115, applies pressure calibration, tracks peaks, handles the button and updates the display. It is the selected controller for [W01](../../wiring/bench/README.md), where accessible headers support probing, protoboard construction and USB debugging. The [XIAO ESP32-S3](../xiao-esp32s3/README.md) is the compact finished-gauge target.

**ESP32-S3** names the microcontroller family. A **module** combines the chip with supporting parts; the **carrier/development board** provides headers, power and programming interfaces. Two carriers can use the same processor while exposing different pins and power paths. The board therefore needs its own [P01 interface map](../../pinouts/esp32-s3-devkit.md), rather than treating a chip pinout as a wiring diagram.

### Flash, RAM and N16R8

The purchased listing describes **16 MB flash and 8 MB PSRAM**, reflected in its N16R8 designation. Flash retains firmware and other stored content without power. RAM holds working state; PSRAM is additional working memory available to software. Extra memory can support buffers, but does not by itself increase sensor accuracy or guarantee acquisition timing. Pins associated with the memory configuration must remain available to that hardware; use P01's restrictions when assigning gauge signals.

As a practical distinction, a program image belongs in flash, while a temporary display buffer belongs in RAM. Calibration/settings persistence needs an explicit software storage design; it is not achieved by leaving a value in working RAM.

## Selected hardware and evidence

Purchased listing: [Amazon B0D93DLB6Q](https://www.amazon.com/dp/B0D93DLB6Q), reported **USD 7.99**. Quantity was not explicitly specified. The board has not yet arrived; supplied images are online references, not photographs of received hardware. The [BOM](../../bom/parts.md) owns procurement status.

Vendor development board image

The [bench-board evidence record](bench-board-reference.md) collects the YD-style candidate, pictured labels, USB roles and jumper questions. The [original electronics import record](../gauge-electronics/README.md#import-record---2026-10-06) retains provenance for the image above. Media paths remain unchanged.

## Power, signals and debugging

W01 selects computer USB for power/debugging or standalone USB for operation without a computer, one source at a time. Disconnect and restart when switching. The [selected power/debug plan](power-plan.md) uses native USB, IN-OUT closed and USB-OTG open. Left row 21 / 5Vin supplies the nominal 5 V branch, while left row 1 / 3V3 supplies the display and translator LV. This is a documented board-family assumption; rail and load checks remain Q05/Q12.

The sensor and ADC share a regulated 5 V branch. ESP32 signals remain 3.3 V, so the ADC's I2C data and clock connect through a bidirectional translator. The display uses a separate SPI interface. Exact GPIOs and electrical endpoints belong in P01 and W01; the [gauge integration guide](../gauge-electronics/README.md) explains the complete chain.

Firmware should select a board-specific pin/power configuration while sharing acquisition, calibration and UI logic with the XIAO build. No firmware implementation or successful bench operation is implied by this selection.

## Learning and bring-up

Follow [W01's phased assembly](../../wiring/bench/README.md#phased-assembly-and-verification). Controller-only startup checks programming and the chosen power path. Adding peripherals then tests combined load and interfaces. A successful unloaded boot does not prove that the board can supply the complete gauge.

Record the actual board, rail readings and configuration when hardware arrives. Q04/Q05/Q12/Q14 in the [question register](../../../docs/open-questions.md) track the remaining board, power and allocation work.

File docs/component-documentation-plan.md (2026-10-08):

# Component documentation improvement plan

The repository combines an engineering record with explanations that help readers understand and reproduce the project. Component READMEs introduce the underlying concepts; interface pages, harness sources, the BOM and test records retain responsibility for precise implementation details.

## Instructional approach

Each component page should answer the following questions, using only the sections and examples that are useful for that part:

1. What is it, and what does it do in this system?
2. How does it work, and which terms does a new reader need?
3. Why is it used here, and what tradeoff does that choice make?
4. How does it connect to the surrounding components?
5. What can an assembly check or experiment demonstrate, and what remains unknown?

Explain concepts before specifications and import history. Keep a distinction between hypothetical examples, selected design values, vendor claims and measured results. Link to the authoritative interface, harness or procedure instead of copying its tables. Explanations should follow the current shared-5 V ADC architecture and use inH2O for project pressure examples.

## Adopted electronics organization

The electronics use separate component folders, with a shared integration guide:

| Destination under `hardware/components/` | Responsibility |
| --- | --- |
| `esp32-s3-dev-board/` | N16R8 bench controller, chip/module/carrier distinctions, memory, USB and board-specific evidence |
| `xiao-esp32s3/` | Compact finished-gauge controller, aliases/pin budget and board power constraints |
| `gc9a01-display/` | TFT/display-controller concepts, SPI and display-control signals, layout/readability and module limitations |
| `gauge-electronics/` | Short integration guide explaining how the controller, ADC, translator, display and button work together; retain the original multi-component import record |

The bench-board evidence page is stored with its controller. Keep existing media paths stable; update relative links, plain-text references and any section anchors affected by the split. P01/P02/P05 remain the authoritative interface maps, and the BOM remains the procurement record. The sensor/pigtail stays together because it forms one useful interface assembly.

## Work sequence and progress

- [x] Establish the instructional purpose in the repository entry point, component index and AGENTS.md.
- [x] Add an initial explanation of sensor/calibration, converter/power and check-valve/relief concepts alongside the existing technical records.
- [x] Add an electronics introduction distinguishing acquisition, computation and display responsibilities.
- [x] Separate N16R8, XIAO and GC9A01 component pages; move bench-board evidence to N16R8, retain the shared integration/import guide and update references.
- [x] Review the ADC introduction for input-interface consistency, resolution versus accuracy and explicit hypothetical examples in inH2O, preserving its educational intent.
- [x] Introduce the restrictor's flow role, bore-area comparison and distinction from the catch can using the existing CAD record.
- [x] Connect the ADC introduction to the separate controller/display pages.
- [ ] Extend the catch-can/PCV explanation using the existing installation and architecture records.
- [x] Add a reading path through concepts, interfaces, complete wiring, phased assembly and calibration in the [gauge integration guide](../hardware/components/gauge-electronics/README.md#reading-and-building-path).

For each completed change, check links and filename case, current design consistency and whitespace. Render and inspect any changed diagrams. Documentation review does not establish physical performance or replace calibration and bench results.

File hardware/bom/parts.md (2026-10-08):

# Parts and procurement

This record tracks reported purchases, inventory status and unresolved selections. Prices are actual reported purchase amounts, not current quotes. Quantities distinguish individual items from packs where known; TBD means unknown, not zero or not required. Purchased does not imply received, installed, or tested. Published specifications and compatibility claims still require verification on the actual parts.

| Category / part | Manufacturer / identifier | Source | Status | Qty | Cost | Specification / purpose / notes |
| --- | --- | --- | --- | --- | --- | --- |
| Catch can | EVIL ENERGY; product B087LZHFGC reported | Amazon, purchase reported | Installed 2026-09-13 in earlier project | 1 | USD 35.29 | Reported purchase price; 300 ml baffled can; temporary vented mode, not completed manifold PCV; see [installation record](../../docs/installation/2026-09-13-catch-can.md) |
| PCV hose | Manufacturer / PN TBD | TBD | In use | TBD | TBD | 1/2 in SAE 30R7 reported; final routing/lengths TBD; restrictor targets 3/8 in ID hose |
| Catch-can bracket | Custom aluminum angle / steel assembly | Fabricated | Installed 2026-09-13 in earlier project | 1 assembly | TBD | Two reported 3.5 mm pop rivets, M10 x 1.5 bolt/washer, Permatex Seal+Lock; inspection after heat cycles pending |
| Restrictor filament | QIDI PAHT-CF | TBD | Used for initial print | TBD | TBD | Record spool and print settings with future builds |
| 3 mm restrictor | Custom | Printed | Initial print reported; CAD and QIDI project imported | TBD | TBD | Baseline; measured bore and vehicle validation pending; see [actual CAD dimensions](../../cad/pcv-restrictor/README.md) |
| 2 mm restrictor | Custom | Printed | FreeCAD mesh imported; physical print status unconfirmed | TBD | TBD | Comparison variant; no slicer settings supplied |
| 4 mm restrictor | Custom | Printed | QIDI project imported; physical print status unconfirmed | TBD | TBD | Comparison variant; saved profile does not establish print completion |
| Relief/check valve | EVIL ENERGY; Amazon ASIN B0FQJ71WZW | [Amazon listing](https://www.amazon.com/dp/B0FQJ71WZW), purchase reported | Purchased; receipt/installation unconfirmed | 3 valves (one 3-piece pack) | USD 18.04 total | Listed specifications: black aluminum one-way fuel check valves, listed as 1/2 in (12 mm), for gasoline, diesel and coolant, with universal hose clamps. Earlier context reports 0.5 PSI opening; actual cracking pressure remains unverified. Desired approximately 0.1 PSI requires modification/testing. |
| Replacement relief spring | TBD | TBD | Under consideration | TBD | TBD | Measure valve/spring and bench-test before selecting |
| FTP pressure sensor | Aftermarket; listed cross-references 16196060 / 16238399 / 12219388; ASIN B0CNZ2Q1F2 | [Amazon listing](https://www.amazon.com/dp/B0CNZ2Q1F2), purchase reported | On hand; installation/operation unverified | TBD | USD 7.89 reported purchase price | Purchased quantity not specified. 5 V, three-wire analog design concept; actual electrical requirements, pinout, and transfer function unverified |
| Sensor pigtail | HiSport 13585316; ASIN B09NVW46W2 | [Amazon listing](https://www.amazon.com/dp/B09NVW46W2), purchase reported | Purchased; not yet received | TBD | USD 7.99 reported purchase price | Quantity not specified. Verify terminal positions and physical fit; wire colors are not authoritative |
| Power converter | SSLHONG B09NVG35CX | [Amazon listing](https://www.amazon.com/dp/B09NVG35CX), purchase reported | Purchased; not yet received | TBD | USD 13.99 reported purchase price | Listed 8-60 V input, 5 V / 3 A USB-C output, IP67; quantity not specified; not established as OEM load-dump qualified; see [power reference](../components/gauge-power-supply/README.md) |
| Bench MCU board | ESP32-S3 N16R8; ASIN B0D93DLB6Q | [Amazon listing](https://www.amazon.com/dp/B0D93DLB6Q), purchase reported | Purchased; not yet received | TBD | USD 7.99 reported purchase price | Listed 16 MB flash / 8 MB PSRAM; bench development; exact board revision/pin assignments pending |
| Gauge MCU boards | Seeed Studio XIAO ESP32-S3; ASIN B0DJ6NQFKX | [Amazon listing](https://www.amazon.com/dp/B0DJ6NQFKX), purchase reported | Purchased; receipt/operation unconfirmed | 3 boards (one pack) | USD 21.59 total | Listed 8 MB flash / 8 MB PSRAM; intended finished-gauge controller, bench counterpart, and spare |
| Displays | Hosyond 1.28-inch GC9A01 round TFT; ASIN B0DYP4J9XP | [Amazon listing](https://www.amazon.com/dp/B0DYP4J9XP), purchase reported | Purchased; receipt/operation unconfirmed | 3 displays (one pack) | USD 14.39 total | Listed 240 x 240, 4-wire SPI; initial prototype display; final size/layout and voltage compatibility pending |
| External ADC modules | ADS1115 breakout modules; ASIN B0BXDLZLZS | [Amazon listing](https://www.amazon.com/dp/B0BXDLZLZS), purchase reported | Purchased; not yet received | 3 modules (one pack) | USD 5.98 total | Chip identity/operation unverified; bench, gauge, and spare allocation planned; see [ADC reference](../components/adc/README.md); shared 5 V and +/-6.144 V gain selected; translated I2C, remaining rate/address settings and implementation pending |
| RC input-filter subassembly | Custom protoboard circuit | [Design and assembly](../components/rc-input-filter/README.md) | Initial design selected; not assembled | 1 per build | No new purchase recorded | R1 in series, C1 from A0-side junction to ground; no divider. Power/fault behavior remains Q17 |
| RC filter R1 | 470 ohm resistor; exact stock part TBD | Existing inventory, reported | Stock selection pending | 1 per filter | Not recorded | 1% preferred / 5% acceptable, conventional 0.125 W or 0.25 W; record substitutions |
| RC filter C1 | 1 uF nonpolar capacitor; exact stock part TBD | Existing inventory, reported | Stock selection pending | 1 per filter | Not recorded | Film or suitable ceramic such as X7R; >=10 V rating; record type/tolerance/effective capacitance considerations |
| I2C level translator | hiBCTR BSS138 four-channel; ASIN B0DSZBC8K6 | [Amazon listing](https://www.amazon.com/dp/B0DSZBC8K6), purchase reported | Purchased; receipt/operation unconfirmed | 10 modules (one pack) | USD 6.88 total | One per build; channels 1/2 for SDA/SCL, 3/4 unused. [Component and terminal reference](../components/i2c-level-shifter/README.md); fitted pull-ups and bring-up Q29 |
| Multifunction button | TBD | TBD | Planned | 1 per gauge | TBD | Click clears min/max; long press opens zero confirmation; see [control design](../../firmware/README.md#multifunction-button) |
| Solderable protoboard | Generic; exact size/pad pattern TBD | Existing inventory | On hand, reported | TBD | Not recorded | W01 carrier; nominal 2.54 mm grid assumed for planning; inspect pad connectivity during layout |
| Male pin headers | Generic | Existing inventory | On hand, reported | TBD | Not recorded | Nominal 2.54 mm pitch assumed; module connections |
| Female header/socket strips | Generic | Existing inventory | On hand, reported | TBD | Not recorded | Nominal 2.54 mm pitch assumed; solder to carrier for removable modules; check fit and retention |
| Gauge enclosure / fasteners | Custom; material TBD | TBD | Planned | TBD | TBD | ASA is a candidate; mounting and heat exposure TBD |
| Input fuse / holder | TBD | TBD | Planned | TBD | TBD | 0.5-1 A proposed starting range; final rating, characteristics, location, and wiring pending load/startup measurements and electrical design |
| TVS / input filter | TBD | TBD | Under consideration | TBD | TBD | Select alongside power protection design |
| Wiring / connectors / USB-C breakout | TBD | TBD | Planned | TBD | TBD | Gauge installation and strain relief |

The [check-valve reference](../components/check-valve-relief-valve/README.md) includes the supplied vendor specifications, exploded view, and compatibility illustrations. Its specification image states the published 0.5 PSI opening pressure; actual valve behavior remains unmeasured.

The [FTP sensor and pigtail reference](../components/fuel-tank-pressure-sensor/README.md) includes reported purchase identifiers/prices, supplied product images, and advertised dimensions. The sensor is on hand; the pigtail has not yet arrived. Purchased quantities remain unspecified. Images do not establish a pinout or sensor calibration.

The [gauge electronics guide](../components/gauge-electronics/README.md) links the separate N16R8, XIAO and GC9A01 component records and explains integration with the ADC and firmware. Listed hardware specifications have not been independently verified.

For updates, record exact purchased identifiers, source link, quantity, actual cost/currency, and receipt/installation date when known. Keep candidate alternatives distinct from installed parts. Store verified wiring in `hardware/schematics/` when available; link manufacturer documentation with its revision/access date rather than inventing specifications.

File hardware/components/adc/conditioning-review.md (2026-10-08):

# Pressure-input conditioning and logic interface

## Selected electrical architecture

The FTP sensor and ADS1115 share the regulated **5 V branch**. ESP32-S3 logic remains **3.3 V**, with a bidirectional I2C translator between the controller and ADC. Q27 records this selection; it applies to both the N16R8 bench build and the XIAO gauge. The actual bench 5 V takeoff remains Q05/Q12.

The nominal sensor signal reaches A0 without divider scaling. The initial [RC input filter](../rc-input-filter/README.md) uses 470 ohm series resistance and 1 uF from the A0-side node to ground. W01 COND now names its IN/OUT/GND nodes. Q17 retains physical response, power transitions and any additional protection. The advertised sensor family and nominal 5 V analog interface are the working design basis, not a measured transfer curve. Calibrate the assembled chain under Q10/Q21.

The sensor is on hand and unmarked; its pigtail, ADC modules and project converter have not arrived. A multimeter and alternative bench/USB supplies are available, but their suitability depends on the particular test.

## Input range and acquisition

Select **+/-6.144 V** full-scale range for A0 single-ended measurement, giving **187.5 uV per count**. This covers the expected unscaled signal, including a nominal 0-5 V design envelope. The programmable range does **not** permit an input beyond the actual ADC supply: normal analog input voltage must remain between GND and VDD. A nominal 0.5-4.5 V sensor output fits a 5 V-powered ADC; the actual sensor response remains a calibration question.

Removing the divider avoids its attenuation and resistor-ratio error. Sharing the sensor/ADC supply reduces independent-rail mismatch, but does not prove transient behavior or guarantee that every fault is safe. The ADC uses an internal reference; shared supply does not automatically cancel a supply-dependent sensor response.

## I2C translation requirements

At VDD = 5 V, the ADS1115 minimum specified logic-high input is 0.7 VDD = **3.5 V**. Pulling its bus only to 3.3 V therefore does not provide a guaranteed interface. Use bidirectional translation suitable for open-drain I2C, with controller-side pull-ups to 3.3 V and ADC-side pull-ups to 5 V. Account for resistors already fitted to the breakout; do not expose ESP32 pins to 5 V.

Q28 selects the [hiBCTR BSS138 module](../i2c-level-shifter/README.md): LV at 3.3 V, HV at 5 V, common ground, channel 1 SDA and channel 2 SCL. No enable GPIO is required. Initial speed remains a 100 kHz candidate. Actual pull-ups, bus levels, communication and power transitions are bring-up work under Q08/Q29.

W01's LS1 now uses the selected module's visible terminal labels. GND_HV/GND_LV distinguish the two pads both marked GND; they are documentation aliases. Match the component's solder-side orientation reference. LV and HV signal ports must not be directly bridged.

## Filtering and power behavior

The built RC circuit is selected as an initial prototype: R1=470 ohm, C1=1 uF nonpolar, nominal cutoff 339 Hz and time constant 0.47 ms. Its [component guide](../rc-input-filter/README.md) owns internal connectivity, stock-part requirements, calculations and assembly. Earlier divider-based filter values are superseded. ADC supply bypassing is separate; inspect fitted decoupling under Q08. Q17 remains Investigating for stock-part recording, actual response and power/fault behavior; no clamp or isolation stage is selected.

Do not independently power the sensor while the ADC is off. Check local rail differences, startup/shutdown and any retained charge from the selected filter during bring-up. No analog isolation IC or op-amp is selected. Add one only if the resulting circuit or a demonstrated operating condition requires it.

## Superseded proposals

| Earlier proposal | Current decision |
| --- | --- |
| ADS1115 powered from 3V3 | Sensor and ADC share 5 V |
| 12/20 kohm example, then 15/20 kohm divider candidate | No analog divider |
| +/-4.096 V gain for a divided signal | +/-6.144 V for the unscaled signal |
| 100 nF signal capacitor with divider-derived cutoff | Initial 470 ohm / 1 uF RC selected; physical response and power/protection remain Q17 |
| Analog isolation switch / adapter as the next implementation choice | No default analog isolation stage; assess the shared-supply circuit |
| Direct 3.3 V controller-to-ADC I2C | Separate 3.3 V and 5 V segments through a translator |

## Remaining work

- Q29/Q08: account for fitted translator/ADC pull-ups and check bus levels, communication and power behavior during bring-up; Q28 selection is resolved.
- Q05/Q12: establish the USB-derived shared 5 V source and load budget.
- Q17: record stock R1/C1, validate the selected filter and review power transitions/any justified additional protection.
- Q18: settle address, conversion rate/mode and completion handling; gain range is selected.
- Q10/Q21: calibrate sensor response and validate the complete measurement chain.

Electrical limits and gain scaling come from the [preserved TI ADS1115 datasheet](../../datasheets/ads1115-datasheet.pdf), especially recommended operating conditions and programmable gain. These are design calculations and requirements; no physical test results are recorded here.

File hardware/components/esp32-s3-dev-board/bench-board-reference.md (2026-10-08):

# N16R8 bench-board reference evidence

The supplied references support a YD-style 44-position ESP32-S3 development-board family as the candidate for W01. They do not establish the identity or electrical behavior of the received unit. [P01](../../pinouts/esp32-s3-devkit.md) remains the interface map; Q04 and Q05 remain Investigating in the [question register](../../../docs/open-questions.md).

## Identification and source limits
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

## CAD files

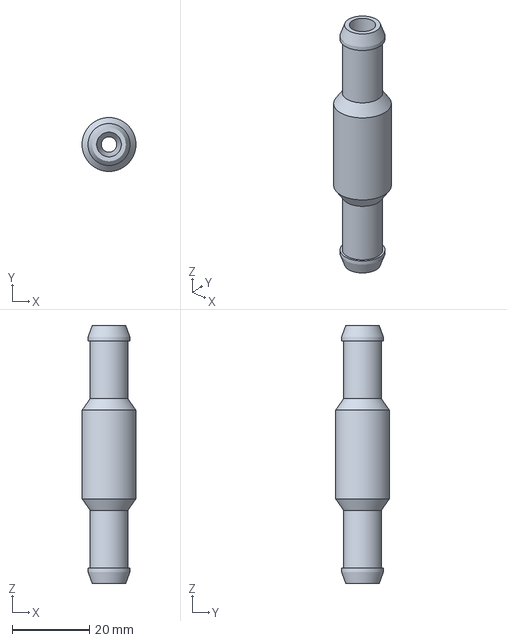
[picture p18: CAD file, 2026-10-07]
cad/pcv-restrictor/printing/pcv-restrictor-4mm.3mf
14.0 x 14.0 x 67.0 mm

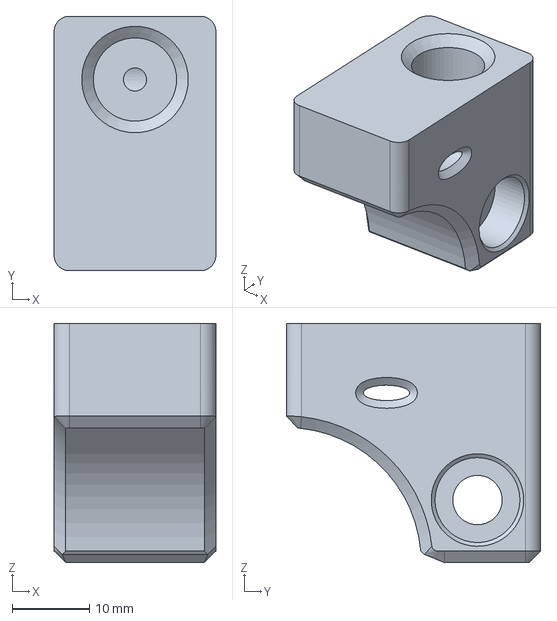
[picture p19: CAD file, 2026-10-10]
cad/pressure-tap/source/pressure-tap.FCStd
21.0 x 33.0 x 31.0 mm

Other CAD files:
cad/pcv-restrictor/source/pcv-restrictor.FCStd
cad/pcv-restrictor/printing/pcv-restrictor-3mm.3mf
cad/pcv-restrictor/printing/pcv-restrictor-2mm.3mf

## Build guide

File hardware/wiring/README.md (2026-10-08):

# Harness documentation

Use WireViz YAML for exact physical connectivity and adjacent Markdown for scope, interfaces, evidence and reproduction commands. Follow the [standard](../../docs/diagramming-and-wiring-standard.md) and select work from the [inventory](../DIAGRAMS.md).

Track unresolved power and interface dependencies in the [open-questions register](../../docs/open-questions.md). Q01 establishes the complete bench-design scope below and Q02 selects the N16R8 controller; Q03 selects alternate USB sources with a restart between modes. Power-path verification and pin assignments remain open.

The [W01 bench harness](bench/README.md) contains the complete design draft, proposed GPIO assignments, generated connection schedule and phased assembly views. `bench/` owns its YAML and adjacent `generated/` outputs. Add `vehicle/` with its first selected artifact; installed wiring remains a separate configuration.

Start with one bench harness. Sensor, display and ADC subassemblies are inventory candidates; split them into separate YAML only if they are physically separable and independently useful. Otherwise document them within the bench source to avoid conflicting maps. Vehicle wiring requires its own power, grounding, routing and service decisions.

Generated harness BOMs describe construction requirements; [parts.md](../bom/parts.md) remains the procurement record. Record tool versions, source revision/hash and the verified render command alongside each harness. Never hand-edit generated connectivity.

## W01 scope and assembly

W01 documents the complete intended bench wiring: controller, display, ADC, sensor, input conditioning, power distribution and one multifunction button. Its [assembly guide](bench/README.md#phased-assembly-and-verification) derives section views from the full source. Resolve the marked gaps and verify endpoint assignments before treating it as assembly-ready. Phased assembly does not reduce the overall design scope.

During drafting, mark unresolved terminals, component values or connections inline as TBD with their open-question IDs and a link to the register. Do not draw a guessed connection as established wiring. Resolve the applicable design and interface questions before issuing instructions to assemble or energize that section; measured performance remains a separate validation activity.

Include an assembly section describing the selected build order and verification gates. Each phase should identify the connections to assemble, required power/disconnection state, checks and expected results, and the conditions for proceeding. Smaller wiring views may highlight the relevant portion of the complete design, using the same connector, pin and net identifiers. Derive these views from the authoritative harness source rather than maintaining independent connectivity definitions. Identify any temporary test connections explicitly.

W01 proposes the sequence and verification gates; unresolved section prerequisites must be completed before use. Preserve measured results separately and update the main design if testing requires changes. Q01 selects this documentation approach; it does not resolve the remaining terminal, power or component questions.

## Controller configurations

W01 uses the N16R8 ESP32-S3 development board. The XIAO ESP32-S3 remains the finished-gauge target and requires the same complete wiring design, explicit pin assignments and phased assembly/verification approach. Bench results inform the XIAO design but do not verify its different power paths, GPIO allocation or load capacity.

Keep each board's physical connections explicit in its harness configuration, with shared functional names where useful. Match those assignments to the corresponding [firmware board configuration](../../firmware/README.md#board-configurations). A XIAO bench validation configuration and installed vehicle wiring have distinct operating conditions; do not substitute the N16R8 map or treat a board change as only a firmware change. Create the XIAO artifacts when their scope is selected, retaining W05 for vehicle wiring.

## Bench power requirements

The N16R8 bench setup must preserve USB programming/debugging and also operate without a computer. Powering the complete system from the computer's USB connection is desirable if the verified board paths and load budget support it; external power remains an option. Firmware must start and perform its gauge functions without waiting indefinitely for a USB host or serial console.

The selected W01 arrangement uses one USB power source at a time: computer USB for power and development, or a suitable standalone USB supply for operation without a computer. Unplugging and restarting when changing sources is acceptable. The [power plan](../components/esp32-s3-dev-board/power-plan.md) selects native USB, IN-OUT closed, USB-OTG open and L21 nominal 5 V distribution (Q30). Display VCC uses board 3V3 (Q31). Actual rail voltage, regulator margin and source/cable capacity remain normal bring-up checks (Q05/Q12). The standalone supply is not yet selected. A converter-fed USB source would additionally require Q11 verification.

Simultaneous computer and external power, and uninterrupted source switching, are outside the selected W01 mode. Q19 remains open for later converter/vehicle integration. If Q05/Q12 show the selected USB arrangement cannot support the complete load, revisit the implementation explicitly; do not silently add another supply. Neither the two pictured USB ports nor a generic ESP32-S3 schematic proves the purchased board supports simultaneous sources.

## Bench construction and retention

W01 must form a sturdy assembly that can be moved without intermittent contacts or repeated reconnection. Loose jumper pins inserted into solderless breadboards are not the intended final bench construction. Temporary probing fixtures may be used during checks, but must not define the completed harness.

The selected construction is a solderable protoboard/perfboard carrier with female header strips soldered to it. Modules use male pin headers and plug into those sockets for removal and replacement. Permanent carrier wiring and component connections are soldered. The available sockets are female header strips, not solderless breadboard contacts. Protoboard, male headers and female socket strips are reported on hand in existing inventory. Use nominal 2.54 mm (0.1 inch) pitch as the accepted planning assumption; no photos or product identification are required to continue design. Check module row spacing, clearance, contact fit and retention during layout/assembly.

Identify the actual carrier pad/track pattern before laying out connections: isolated pads and linked strips require different wiring and isolation. Do not assume a solderable board has the same internal connections as a solderless breadboard. Record any required cuts or bridges in the assembly documentation. Carrier size and pad pattern remain layout details; nominal 2.54 mm pitch is assumed. These checks do not block drafting the electrical connectivity.

Secure modules mechanically and provide strain relief so cable movement does not pull on contacts or solder joints. Choose a common support or carrier and retain cables/connectors where needed; do not rely on solder alone as the mechanical support for loose modules. Record connector orientation, wire identity and retention in W01, and check continuity and operation after normal handling of the assembled bench unit.

Q16 is resolved as a construction policy. Use a convenient mixture of soldered leads and secure removable connections at assembler discretion, including off-board display, button and sensor wiring. Do not mandate a connector family or exact mechanical arrangement unless an electrical or fit requirement makes it necessary.

W01 must specify endpoint connectivity, polarity, return routing and applicable wire/current/voltage requirements. Follow its [wire color convention](bench/generated/connections.md#wire-color-convention) for added wiring; label both ends and record substitutions when stock differs. The assembler may choose compatible terminations, practical lengths and mechanical placement within those constraints. Record the actual connectors, their pin orientation, wire identity/length and any departures in the build record or as-built harness. A chosen connector pin order must be mapped explicitly before use; it is not implied by a generic drawing.

Electrical wire sizing and return routing remain harness design work, not unanswered user preferences. Routine construction choices do not require separate consultation. The completed assembly still needs firm retention, mechanical support and strain relief. Vehicle mounting and vibration requirements remain a separate W05 design.

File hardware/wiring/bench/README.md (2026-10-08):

# W01: N16R8 bench harness

**Document state: Draft. Not assembly-ready.** W01 covers the complete intended bench gauge: one N16R8 controller, one GC9A01 display, one ADS1115, the FTP sensor and built RC input filter, a bidirectional I2C translator, one multifunction button, and USB-derived power distribution. The controller has not arrived and no connections have been bench verified. The XIAO and vehicle converter configurations remain separate work.

The design establishes intended signal and power wiring from listing/reference evidence, with hardware validation and remaining sensor interfaces explicit. Assemble and energize a section only after its listed prerequisites are resolved. P04 supplies the working sensor cavity map. Native USB, IN-OUT closed, USB-OTG open, the L21 nominal 5 V takeoff and 3.3 V display supply are selected (Q30/Q31). Rail/load checks, translator bring-up and filter power/protection review remain assembly checks.

## Drawing and authoritative source

W01 full draft harness

Open the [full SVG](generated/bench-harness.svg) to zoom. The smaller phase views below are derived from the same source. Use the [generated connection schedule and controller assignment table](generated/connections.md) for readable endpoints and wire identities.

- **Connectivity source:** [bench-harness.yml](bench-harness.yml). Edit connections here, then regenerate; do not edit generated drawings or the schedule.
- **Source identity and tools:** [generation record](generated/generation.md).
- **Instructional component view:** [L01 / Wokwi](../../../simulation/wokwi/README.md), covering all intended non-USB conductors, the internal RC node and a USB annotation. W01 remains the wiring authority; virtual parts are not purchased-board header layouts or functioning peripheral models.
- **Component-view PNG:** [L01 preview](../../../simulation/wokwi/diagram-preview.png), generated from the Wokwi source for viewing without opening the editor.
- **Follow-up:** [open questions](../../../docs/open-questions.md), especially Q04-Q10, Q12, Q14, Q17, Q18 and Q29.

All drawn connections are planned or proposed. Blue module blocks identify interfaces from P01/P03/P05; amber blocks or bundles contain unresolved functional boundaries. Wire colors follow the [W01 color convention](generated/connections.md#wire-color-convention): black for ground, red for 5 V, orange for 3.3 V, and separate signal colors. The complete USB cable has no conductor color assignment and renders neutrally; it does not denote ground. Display VCC is orange for its selected 3.3 V rail. The full drawing is a design-review view, not an assembly-ready rendering. Blank/unconnected terminals are intentional where explained below.

### Endpoint and orientation conventions

| Identifier | Meaning and view | Evidence / limitation |
| --- | --- | --- |
| J1 | N16R8 board; `L1` etc. are left-row coordinates from the component side, antenna up and USB down | [P01](../../pinouts/esp32-s3-devkit.md). Only relevant interfaces are displayed; these are documentation coordinates, not manufacturer connector numbers. USB is a whole-port symbol, not a contact. Q04/Q05 remain open |
| J2 | Display header; screen side, connector tab down; labels read left to right | [P05](../../pinouts/gc9a01.md): 3.3 V VCC/logic selected Q31; current/backlight and operation Q06/Q20 |
| J3 | ADC header; back side, mounting holes up; labels read left to right | [P03](../../pinouts/ads1115.md). Module identity and pull-up/bias checks Q07/Q08 |
| S1 | Normally open button; `CONTACT_A/B` identify opposite electrical contacts | Physical terminal numbering not selected. On a multi-leg switch, identify which legs are internally common before wiring |
| RAILS | Functional distribution nets on the carrier | Not a purchased connector or pad-order drawing. Each named net is separate; repeated appearances of GND denote the same reference |
| FTP | Sensor/pigtail assembly, using the pigtail mating face with latch up: A/B/C left to right | [P04](../../pinouts/ftp-sensor.md) adopts the GM-family map: A ground, B signal, C 5 V. Working assumption for the listed replacement; Q09 retains as-built lead/fit check, Q10 calibration. Sensor mating face mirrors this view |
| LS1 | hiBCTR BSS138 module; solder/back side with HV row above LV row | [Component terminal reference](../../components/i2c-level-shifter/README.md). Channel 1 SDA, channel 2 SCL; GND_HV/GND_LV alias the two GND pads. Q28 selected; bring-up Q29 |
| COND | Built RC input filter: IN/OUT/GND electrical nodes | [Internal circuit and assembly](../../components/rc-input-filter/README.md): R1=470 ohm between IN/OUT; C1=1 uF nonpolar between OUT/GND. Node labels are not connector pin numbers. Q17 validation/power review remains |
| USB_SOURCE / W_USB | One external USB source and a complete factory cable | Computer power/data or standalone power, one at a time. The single graphic line represents the cable, not one conductor or a USB contact map |

Wire bundles group related connections for documentation. They do not require jacketed cables or a particular removable connector. Their conductor numbers are stable wire identities, not pigtail cavity numbers. Follow the [construction policy](../README.md#bench-construction-and-retention): on-hand nominal 2.54 mm protoboard/header stock, firm retention and strain relief, with soldered or removable terminations at assembler discretion. Record each chosen connector's actual mating view and mapping in the as-built record.

## Proposed signal allocation

The [generated controller table](generated/connections.md#proposed-controller-assignments) is derived directly from J1 in the YAML. Q14 contains a concrete proposal now, rather than an empty pin plan. It remains subject to matching the actual carrier and checking onboard uses under Q04/Q05; no firmware pin configuration has been implemented.

The allocation groups display signals and I2C on the board's left header. It leaves GPIO0/3/45/46 boot-related pins, GPIO35-37 memory connections, GPIO19/20 native USB, GPIO43/44 UART, GPIO39-42 JTAG and provisional GPIO48 RGB use out of gauge wiring. Reserve the unused exposed pins instead of connecting them by default. These restrictions come from P01 and its linked manufacturer references; a header label alone does not prove a pin is available on the actual carrier.

The button uses an internal GPIO pull-up with a normally open contact to GND. No button supply wire is required by this proposed interface. Validate pull-up/noise behavior for the assembled lead length. Preserve the [selected BetterButton interactions](../../../firmware/README.md#multifunction-button), including the separate zero-confirmation state. No backlight-control GPIO or display readback wire is assigned.

### ADC bring-up candidate

The 5 V supply and +/-6.144 V gain are selected. Other settings below remain Q18 candidates; none are recorded working settings:

| Setting | Proposal | Reason / prerequisite |
| --- | --- | --- |
| Channel | A0 single-ended to GND | One pressure channel; sensor output first passes through COND |
| Address | ADDR to GND, 7-bit `0x48` | Simple single-module address. Verify existing board bias before fitting W_ADDR; do not short an existing VDD strap |
| Gain range | **Selected: +/-6.144 V** | Covers the unscaled nominal 0-5 V envelope; 187.5 uV/count. Actual input must stay within GND to ADC VDD |
| Conversion | Single-shot, 128 SPS conversion setting | Poll completion/status, read one completed result, then request the next. Avoid counting repeated reads as new samples; effective acquisition rate includes software and bus overhead |
| Bus | Initial 100 kHz I2C | Bring-up candidate through LS1; verify separate 3.3 V and 5 V pull-up domains and communication |
| Readiness | Poll over I2C; ALERT unconnected | Saves one GPIO and provides explicit conversion completion in single-shot mode. Disable unused comparator/ALERT function |

Sources: [preserved TI datasheet](../../datasheets/ads1115-datasheet.pdf), sections 7.3.3, 7.4.2, 7.5.1 and Config register Table 8-3; [ADC component notes](../../components/adc/README.md). The existing 100-200 samples/s goal is not guaranteed by a nominal 128 SPS setting. Measure effective cadence with display/button activity and adjust Q18 if needed.

J3 A1-A3 are unused and externally unconnected in this draft; final unused-input treatment remains part of Q07/Q17. ALERT is intentionally unused for the polling proposal. Module decoupling and bus pull-ups must be checked under Q08; the absence of external resistor symbols is not a claim that pull-ups are unnecessary.

## Selected power and remaining checks

The [board power plan](../../components/esp32-s3-dev-board/power-plan.md) owns the internal USB/jumper explanation. W01 selects the native USB port (left in P01's front view), IN-OUT closed and USB-OTG open. W_RAIL conductor 3 connects J1 L21 / 5Vin to RAILS.5V. The sensor, ADC and translator HV share that nominal USB-fed rail. W_RAIL conductor 1 connects J1 L1 to RAILS.3V3, which supplies the display and translator LV. The native input diode remains in circuit; 5V is a nominal net name, not a precision 5.000 V guarantee.

The display listing specifies 3-5 V module power. Q31 selects 3.3 V VCC and direct 3.3 V logic. No display supply boundary is left deliberately unfed. RAILS contains only 3V3, 5V and GND; never bridge the two supply domains.

| Selected interface | Remaining assembly/bring-up check | Question |
| --- | --- | --- |
| J1 native USB; COM unused | Normal board/reference comparison, native programming/console/debug setup and startup without a host | [Q04/Q05](../../../docs/open-questions.md) |
| J1 L1 to RAILS.3V3; display and LS1 LV | Check rail voltage and usable regulator margin with display activity | [Q06/Q12](../../../docs/open-questions.md) |
| J1 L21 to RAILS.5V with IN-OUT closed | Check nominal USB-fed voltage after diode/cable drop and source/load margin; USB-OTG stays open | [Q05/Q10/Q12](../../../docs/open-questions.md) |
| LS1 LV/HV | Account for fitted pull-ups and verify bus/power behavior | [Q29](../../../docs/open-questions.md) |
| J3 power, bus and ADDR | Check header, pull-ups and existing address bias during bring-up | [Q07/Q08/Q18](../../../docs/open-questions.md) |
| FTP A/B/C | Use P04's sourced working map; check lead continuity/fit at assembly and calibrate | [Q09/Q10](../../../docs/open-questions.md) |
| COND IN/OUT/GND | Record stock parts; check node wiring, DC levels and power behavior | [Q17](../../../docs/open-questions.md) |

These are documented working assumptions and normal phased checks, not a requirement for additional photographs or independent authentication before designing the harness. Concrete discrepancies require correcting the affected connection.

Q03 selects one computer USB source or one standalone USB supply. Disconnect before changing and restart. No simultaneous USB sources, external header injection, converter/host combination or automatic switchover is included in W01. Source/load capability remains Q12; see [A02](../../architecture/power-system.md).

RAILS.GND is the proposed common electrical reference for the controller, display, ADC, translator, button, sensor return and conditioning. Its symbol does not require a particular terminal strip or chassis bond. Keep the sensor/conditioning/ADC reference path short and avoid using a display power-return conductor as the sole return for the analog section. Actual pad layout and branch routing belong in the build record; confirm common references and powered/unpowered signal behavior before use.

The [electrical review](../../components/adc/conditioning-review.md) selects a shared 5 V sensor/ADC branch and no analog divider. LS1 separates the controller's 3.3 V I2C from the ADC's 5 V I2C: at 5 V VDD, the ADC requires at least 3.5 V for a guaranteed logic high. COND implements the initial 470 ohm / 1 uF RC filter; stock-part recording, response and power/protection review remain Q17; LS1 uses the selected hiBCTR BSS138 module; physical pull-up/bus checks remain Q29. Further circuit documentation can remain nearby or use S01 if its complexity warrants a schematic.

### Wire and construction requirements

- Wire gauge is explicitly **TBD AWG** pending the actual current budget, length/voltage drop, insulation needs and connector fit. W01 is not a numeric wire-sizing specification yet. Record lengths in mm and the final gauge in AWG or mm2 before assembly release.
- Use the planned colors in the [generated schedule and legend](generated/connections.md#wire-color-convention) for added harness wiring. Label each wire by bundle/conductor or net identity; clock and data colors repeat across the separate SPI/I2C bundles. If available stock requires a substitution, identify both ends and record the actual color in the as-built record. Red and orange distinguish the two supply domains. Display VCC uses orange for the selected 3.3 V rail. Purchased pigtail colors remain evidence to record separately, never a basis for assigning sensor terminals.
- USB uses an appropriate factory data cable for computer operation; W_USB is not a cable-fabrication specification. Confirm the selected standalone source/cable can supply the verified load.
- Internal carrier wiring may be soldered; off-board leads may be soldered or use secure removable connectors. Record connectors, splice locations, pad/track cuts and bridges, and test points. Keep exposed conductors insulated and module insertion aligned.
- No shield or chassis connection is selected for this bench design. If noise or cable length requires one, document its termination and update the source instead of adding an undocumented ground path.
- Secure modules and cables independently of fragile signal contacts. Record and inspect strain relief; movement of the completed assembly must not produce intermittent connections.

## Phased assembly and verification

These are planned steps with prerequisites, not completed test results. All wiring changes occur with power disconnected. At each phase, record the actual configuration, supply conditions, instrument and readings using the [data conventions](../../../data/README.md). Retain only verified preceding connections; do not attach later-phase loads to unverified rails.

### Phase 0: identify and prepare

Match the received controller and selected modules to P01/P03/P04/P05. Record orientations and resolve each terminal used in the phase. Check protoboard pad connectivity and socket spacing, and plan support/strain relief. Inspect solder bridges, unintended rail shorts and wire identity before inserting modules. Compare continuity to the generated connection schedule, not a mirrored back-side view.

### Phase 1: controller and distribution

Controller and power section

**Prerequisites:** Q04/Q05 for the selected port and board paths; define the intended source/current limit and Q12 rail limits. Keep peripherals disconnected.

With power disconnected, follow the [selected jumper plan](../../components/esp32-s3-dev-board/power-plan.md): close IN-OUT if open and leave USB-OTG open. Check the intended bridge and rail shorts. Connect one source to native USB; verify controller startup and programming/console behavior. Measure 3V3 and 5Vin against GND before adding loads, then connect W_RAIL using its documented polarity. Record actual diode/cable drop, source/current limit and any heating. No second USB port or external header supply is attached.

**Proceed when:** the controller works in the selected mode, polarity and rails are documented, and there is a supported load budget for the next phase. A stable unloaded rail alone does not prove full-load capacity.

### Phase 2: display and button

Display and button section

**Prerequisites:** Q06/Q12 supply and logic compatibility, Q14 actual-board pin checks, and a chosen display initialization for Q20. The diagram selects RAILS.3V3 to display VCC; use the listed 3-5 V range as the working module supply basis.

With power off, install the display and button connections. Verify the button contact pair is open at rest and closes when pressed. After power-up, verify the input changes between the planned idle and pressed levels, and test display orientation, colors, clipping and signed text. Measure supply voltage/current with display activity. Test the chosen gestures without applying calibration changes to an uncalibrated sensor; verify prompt actions do not also trigger normal-view peak reset.

**Proceed when:** stable display/button operation and current measurements support adding the ADC. Once gauge firmware exists, this test must also show that rendering and gesture handling do not block acquisition.

### Phase 3: ADC without sensor

ADC section

**Prerequisites:** Q07/Q08 module and bus/strap checks, Q05/Q12 shared 5 V source/margin, selected LS1 terminal mapping and Q29 bring-up checks and Q18 configuration review. Sensor and COND remain disconnected.

Inspect existing pull-ups and ADDR bias before installing W_ADDR. Connect ADC power to the shared 5 V branch and LS1 references to their respective rails. Verify each bus segment's idle voltage before attaching the controller: 3.3 V on LV, 5 V on HV. Check address response and register configuration through LS1. An address scan alone does not authenticate the chip. Use a separately documented known-voltage fixture, referenced to the same ground and within verified ADC limits, to check fresh conversions and gain scaling. Record temporary connections; use an independent known voltage for this check rather than treating the uncalibrated sensor as a voltage standard.

**Proceed when:** measured conversions, timing and rail behavior agree with the configured device, including during display activity. Inputs used for a test must have defined values; an unconnected input is not a zero-voltage reference.

### Phase 4: conditioning and sensor

Pressure-chain requirements

**Prerequisites:** P04 working terminal map and Q09 as-built lead/fit check, Q10 applicable pressure limits, Q17 recorded filter parts and circuit/power review, selected LS1 translator and Q29 bus checks and verified shared 5 V distribution. The COND block now links to a concrete internal circuit; remaining load and interface checks still prevent treating the complete harness as electrically validated.

Build R1/C1 using the [component assembly steps](../../components/rc-input-filter/README.md#building-from-existing-inventory). Check IN-to-OUT resistance, capacitor connection and actual parts. Validate the filter with a suitable stimulus and documented limits, including the intended power sequence. A multimeter can check DC levels but does not establish millisecond response or high-frequency attenuation. Check ADC-node voltage before attaching A0. With power off, connect the verified pigtail/circuit and then measure sensor supply, sensor output and ADC input at atmosphere. Follow the [sensor calibration procedure](../../../docs/testing/test-plan.md) within verified pressure limits. Confirm sign, zero, slope, repeatability, validity handling and peaks using the complete assembled chain.

**Proceed when:** the chain has a traceable calibration and no unexplained saturation, drift or power-sequence behavior. Selecting an unscaled input does not establish calibration or fault protection.

### Phase 5: complete bench operation

Use the full diagram and selected firmware configuration. Check combined startup/operating load and rail stability, acquisition cadence under rendering, button actions and invalid/stale indication. Confirm source changes by unplugging, reconnecting the standalone supply and restarting without a computer. Firmware must not wait indefinitely for a host. Verify connector retention and continuity after normal handling. Test persistent settings only when that feature exists; no firmware is implemented by W01.

Promote the documented connections to assembly-ready only as their evidence is recorded. Bench success does not validate the XIAO power path, vehicle transients or W05 installation.

## Rendering and validation

Tested with Python 3.12.10, WireViz 0.4.1 and Graphviz 16.1.0. The [pinned Python requirements](requirements.txt) are drawing tools, not firmware dependencies. Install [Graphviz](https://graphviz.org/download/) separately and put `dot` on PATH; the Python graphviz package does not supply that executable. See [WireViz documentation](https://github.com/wireviz/WireViz) for its native format and CLI.

From the repository root, an isolated environment can be used without a global installation:

```powershell
python -m venv _staging/work/w01/tools/venv
& _staging/work/w01/tools/venv/Scripts/python.exe -m pip install -r hardware/wiring/bench/requirements.txt
# After adding the installed Graphviz bin directory to PATH:
& _staging/work/w01/tools/venv/Scripts/python.exe hardware/wiring/bench/render.py --preview-dir _staging/work/w01/previews
```

`render.py` validates terminal references, conductor coverage and view selection, then produces the full SVG, four section SVGs, a connection schedule and a source/tool record. The optional PNG previews stay private. View membership lives in `x-w01-views` within the authoritative YAML; the renderer never overrides connectivity. Native WireViz can render the full source directly:

```powershell
wireviz -f s -o hardware/wiring/bench/generated hardware/wiring/bench/bench-harness.yml
```

Use `render.py` after source changes so sectional views and the schedule are refreshed together. Native BOM output is not published: functional TBD blocks are not orderable parts, and missing lengths/gauges would make that output unsuitable as a construction BOM. The [procurement BOM](../../bom/parts.md) remains separate.

The full view and four section views were rendered and visually inspected. Terminal references and conductor coverage passed the renderer's checks. These checks validate document generation, not electrical operation; no physical bench results are recorded.

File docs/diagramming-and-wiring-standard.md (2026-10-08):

# Diagramming and wiring standard

This standard defines formats, locations, evidence labels and review practices for system diagrams, interfaces and wiring. It favors maintainable text sources and keeps conceptual architecture distinct from physical connections.

## Choose the simplest useful format

| Purpose | Authoritative format | Use |
| --- | --- | --- |
| Requirements, interfaces, pinouts, rationale | Markdown tables and prose | Default when topology adds no value |
| System, pneumatic, power, signal or data flow | Mermaid embedded in Markdown | Relationships and conceptual boundaries, not exact harness wiring |
| Firmware modes, sequencing, test decisions | Mermaid state, sequence or flowchart in Markdown | Choose the diagram type that answers the question |
| Exact connector-to-connector wiring | WireViz `.yml` | Pin mapping, cables, splices, shields, wire color/gauge/length |
| Electronics component-and-wire illustration; temporary solderless breadboard view | Wokwi `diagram.json` | Recognizable components and colored terminal-to-terminal leads, synchronized with the harness |
| Virtual ESP32 firmware testing | Wokwi JSON and build configuration | Document synthetic inputs, model coverage and differences from physical hardware |
| Other installation or spatial illustration | Editable `.drawio.svg` | When other formats do not express placement well |
| Detailed permanent perfboard layout | DIY Layout Creator, if needed | Optional future hole/copper map; no current tooling dependency |
| Custom circuitry, electrical-rule checking or PCB | KiCad native project | Introduce when circuit complexity warrants it; no PCB is required to justify a real circuit schematic |

Markdown owns explanatory context; Mermaid owns conceptual relationships; pinout pages own terminal identity/evidence; WireViz owns designed point-to-point connectivity; the existing BOM owns purchases. Wokwi provides a synchronized instructional view and virtual model, not a competing wiring authority. A generated harness BOM describes build requirements, not purchased inventory. Native CAD remains authoritative for dimensions. See the [Wokwi adoption decision](wokwi-adoption.md).

## Locations and naming

| Location | Responsibility |
| --- | --- |
| `hardware/components/<component>/` | Component descriptions, design notes and import records; indexed in `hardware/components/README.md` |
| `hardware/DIAGRAMS.md` | Central proposed/artifact inventory and selection queue |
| `hardware/architecture/` | System, PCV, power and measurement architecture in Markdown/Mermaid |
| `hardware/pinouts/` | Verified or explicitly unresolved module/connector interface tables |
| `hardware/wiring/bench/` | Development harness source and accompanying build notes |
| `hardware/wiring/vehicle/` | Separate vehicle harness source and installation notes |
| `hardware/wiring/<configuration>/generated/` | WireViz renderings next to their owning source |
| `simulation/wokwi/` | Maintained Wokwi illustration/simulation JSON, physical mappings, model limits and opening instructions |
| `hardware/schematics/drawio/` | Editable layout/installation illustrations when needed |
| `hardware/schematics/<circuit>/` | Future circuit schematic projects, if justified |
| `firmware/` | Firmware architecture/state/data-flow documentation near future code |
| `docs/testing/` | Test/calibration workflow diagrams near procedures |
| Existing `media/` folders | Photos, vendor references and CAD views; no duplicate harness renders |

Use lowercase kebab-case basenames; retain the requested `DIAGRAMS.md` index name. Create artifact and generated subdirectories with their first useful content. Keep sources and outputs on the same basename. Prefer Git history to filenames such as `final-v2`; record formal build revisions inside documents when needed. Do not move existing component notes or replace `hardware/bom/parts.md`.

Keep the `hardware/` root for shared navigation/index documents. Component-specific folders belong under `hardware/components/`; shared architecture, pinout, wiring, schematic, BOM and datasheet records stay in their purpose-specific directories. Moving a component document does not move its CAD or media.

## Writing style

Explain the design for readers unfamiliar with its development history. Lead with purpose, current choices and remaining work. Use direct technical prose such as "The sensor and ADC share the regulated 5 V branch" and keep compatibility checks beside that statement.

Use Git history for routine editing and selection chronology. Dates belong where they identify an installation, test, calibration, import or source revision. Keep provenance in dedicated records or sections. A short scope/status statement is sufficient for a conceptual design; repeat uncertainty only where it changes how a specific detail should be used.

## Required context

Each artifact's Markdown page or adjacent README records: purpose, scope/configuration (concept, bench or vehicle), document state, authoritative source, evidence links, assumptions/TBDs, related inventory ID and applicable hardware revision. Generated artifacts also record source revision/hash, tool versions and exact command. A review applies only to the documented configuration. Use Git history for routine drafting and selection dates; retain dates for test, calibration, installation and source records.

Document states: **Proposed**, **Selected**, **Draft**, **Reviewed**, **Superseded**. Record blockers separately. Reviewed means reviewed documentation, not tested hardware.

Evidence labels on facts/connections: **Planned**, **Manufacturer Spec**, **Vendor Listing**, **Measured**, **Bench Verified**, **Vehicle Verified**, or **Unknown**. Include dated evidence and method for measurements/tests; one tested connection does not validate an entire harness. Distinguish designed from as-built wiring.

## Diagram and interface rules

- Give every diagram a descriptive title, scope and legend. Use labels and line styles as well as color; keep text legible in normal repository previews and printed copies.
- In architecture, distinguish fluid, power and signal paths, label directions and voltage domains, and mark future features/TBD choices. Concept diagrams do not imply terminal mapping or safe assembly instructions.
- Use simple Mermaid syntax compatible with the target preview; visually review the rendered result. Do not create parallel editable Mermaid and Draw.io versions of the same diagram.
- Pinout pages identify exact board/module revision, connector part/marking, cavity numbers, mating versus wire-entry view, latch/key orientation, and source photograph/drawing. Distinguish chip pins, module header labels, board aliases and MCU GPIO numbers.
- Pinout tables record terminal, label/function, power/logic domain, direction, evidence/status and references. A destination may link to the harness; do not maintain a second independent connection table.
- Assign stable, unique connector/cable/net identifiers within each harness, and explicitly map identifiers shared by subassemblies. Reuse them in pinouts, renders and test records. Do not invent unverified physical pin numbers to complete a drawing.
- Wiring notes specify endpoint connector/pin, wire identity, gauge with units, color, length with units, cable/shield grouping, splices, termination and grounding as applicable. Mark unknowns explicitly in accompanying notes. Keep unresolved connections out of assembly-ready renders.
- Never infer FTP pin function from aftermarket wire colors. Use the purchased sensor/pigtail record; the proposal's PT2782 designation is not an established identity for this purchase.
- Show the sensor conditioning boundary; do not turn a conceptual sensor-to-ADC line into a direct connection. Treat protection, rail capacity, USB/backfeed handling, GPIO assignments, and display power as unresolved until documented.
- Keep peak acquisition separate from display smoothing; no engine-running automatic zero. Bench and vehicle configurations are separate artifacts, not interchangeable revisions.

## Sources, outputs and review

WireViz YAML is the editable connectivity source. Resolve errors against evidence, correct the source and regenerate; never manually repair only the output. Commit SVG as the default browsable render with each selected harness. HTML and TSV are optional when useful; PNG/PDF are derivatives only when needed. Keep generated files trackable, and update them with their sources.

Specify planned conductor colors in the harness source and show them in renders and connection schedules. Start with [W01's color convention](../hardware/wiring/bench/generated/connections.md#wire-color-convention) for new project wiring: black ground, red 5 V, orange 3.3 V and labeled signal colors. Keep unresolved color choices explicit. Distinguish designed wire colors from observed factory leads; color never establishes an unknown terminal function. Labels remain authoritative, and as-built records capture substitutions. A whole factory-cable symbol does not specify its internal conductor colors.

Editable Draw.io SVG must include embedded diagram data. Reopen it to verify editability and check its repository preview. If editable SVG is unsuitable, keep `.drawio` source plus a clearly labeled SVG derivative. See the [official editable-image guidance](https://www.drawio.com/docs/manual/collaboration/diagram-data-image-formats/).

Wokwi JSON is the maintained component-and-wire illustration source. Use stable interface IDs, explicit voltage-domain labels and W01 conductor colors; preserve actual GPIO decisions. Record virtual-to-physical terminal mappings, substitutions and omitted connections beside it. Confirm types/pins against official Wokwi definitions, check JSON syntax and unique IDs, and inspect the rendered diagram. Keep unrelated movement/routing out of electrical edits. Update W01 first when changing actual wiring, then synchronize affected Wokwi views and scenarios. Use one diagram for illustration and simulation when practical; explain differences if separate configurations are needed.

Graphical representations and functional models are separate. Clearly mark unsupported or purely illustrative components, and review community model sources/licenses before adoption. Simulated measurements are synthetic; describe whether a fault scenario exercises application logic, a peripheral driver or a modeled bus. Simulation does not validate the RC filter, power paths, translator voltage levels, current capacity or sensor calibration. The selected solderable protoboard construction remains in effect; a Wokwi arrangement is not a dimensional solder-hole map.

Review source and rendered output for clipped text, swapped terminals, orientation ambiguity, units, evidence labels, missing connections, public metadata and private paths. Rendering proves syntax/presentation, not electrical correctness. Physical verification needs a linked test record. Keep source edits, generated changes and inventory state consistent.

## Tooling

Mermaid lives in Markdown; no Node toolchain is required just to author these pages. Use GitHub rendering and an available Mermaid-capable editor preview. Add an editor extension only if needed; no personal editor settings are required.

Use the [Wokwi guide](../simulation/wokwi/README.md) for online/VS Code opening instructions, model status and current licensing limitations. The initial diagram can be inspected without firmware. Add `wokwi.toml` against actual build artifacts when firmware exists; keep compiled outputs and credentials local. Wokwi remains optional for ordinary firmware builds. Add custom chips/scenarios only with useful content; do not add a second component or pinout inventory.

For harness work, use WireViz plus Graphviz (`dot` executable on PATH). Prefer an isolated pipx installation of WireViz; Graphviz is a separate prerequisite. Follow [WireViz installation/usage](https://github.com/wireviz/WireViz) and the installed `wireviz --help`; output options have changed between releases, as documented in [release notes](https://github.com/wireviz/WireViz/releases).

W01 rendering is validated with Python 3.12.10, WireViz 0.4.1 and Graphviz 16.1.0. Use its [pinned requirements and reproduction commands](../hardware/wiring/bench/README.md#rendering-and-validation); the local venv is an alternative to pipx. The [renderer](../hardware/wiring/bench/render.py) generates the complete harness, sectional views and connection schedule from one YAML source. Mermaid preview commands and tested versions are recorded in the architecture pages. For harness changes:

1. Install Graphviz separately and use an isolated Python environment with the harness's pinned requirements.
2. Check `dot -V` and `wireviz --help`; record actual versions.
3. Verify the installed output-directory/format flags and render the selected YAML into its adjacent `generated/` directory.
4. Record the working command and pin the tested WireViz version in repository tooling before adding repeatable automation. Record Graphviz/Python versions as well.
5. Visually inspect the result, then commit selected outputs with their source.

Do not claim rendering passed until a real artifact has been rendered. Regenerate W01 section views and the connection schedule with its renderer after connectivity changes. Add CI or optional graphical tools only when a selected artifact needs them.

## Selection workflow

Use the [inventory](../hardware/DIAGRAMS.md) to identify scope and dependencies. Document architecture, verify module interfaces, design wiring, render/review, and record bench results. A selected conceptual diagram can show TBDs; production pin mapping must not be guessed. Promote a tested bench design into a separately reviewed vehicle harness when installation details are known.

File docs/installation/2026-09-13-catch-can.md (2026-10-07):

# Temporary vented catch-can installation - 2026-09-13

## Timeline and scope

This was an earlier project, completed before creation of this repository. There was **no catch can in the original September 6 planning state**. The September 13 installation introduced a temporary vented can; it did not complete the manifold-vacuum PCV system now being developed.

The September 6 project notes describe a connected passenger-front fresh-air hose, a capped driver-rear crankcase outlet, and a capped suspected manifold-vacuum connection. No rear passenger-side valve-cover port was found. Port identity and final routing still require verification; the earlier context's generic description of capped rear ports was too broad.

## Reported installation

- EVIL ENERGY 300 ml baffled catch can with top breather; purchase notes identify product B087LZHFGC.
- Custom bracket on the front of the passenger-side cylinder head, using aluminum angle and a fabricated steel mounting piece.
- M10 x 1.5 steel bolt and washer into the aluminum head, with Permatex Seal+Lock compound, as reported in the installation note.
- Two reported 3.5 mm pop rivets joining the catch-can bracket to the custom mount.
- Vent-to-atmosphere operation: crankcase vapor enters the can and exits through the top filter. Manifold vacuum was not connected.

These are installation observations, not a torque specification, validated structural design, or confirmation of final hose/port assignments. The mounting-detail photo has an unattached inlet hose barb; it documents assembly rather than a complete running configuration.

## Initial observations and follow-up

The installation notes report approximately ten minutes of idle with a few revs, light wispy vapor from the breather, and no visible oil discharge or heavy smoke. No crankcase pressure was measured, so these observations do not establish adequate pressure control, relief capacity, or engine condition.

The note called for inspecting the bracket/rivets after heat cycles, monitoring can contents, checking oil-cap sealing, and measuring crankcase pressure after completing the vacuum circuit. Those checks remain unverified here.

At that time, an Improved Racing FO-06R restrictor and an ADD W1 check valve were being considered. They were not reported installed. The later project baseline is a custom printed 3 mm restrictor and a separately evaluated low-pressure relief path; historical purchase ideas do not supersede the current BOM.

## Photographs

Public copies retain the photographed content with embedded metadata removed. Four portrait photos had EXIF orientation applied to their pixels and were re-encoded as high-quality JPEGs; the landscape installation photo was stripped without recompression. No visual redactions or generative edits were applied.

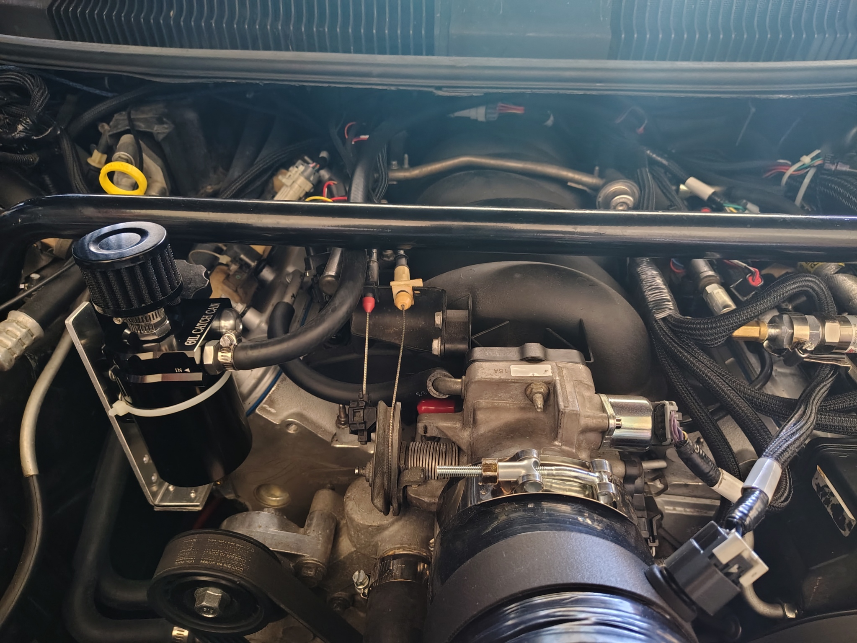
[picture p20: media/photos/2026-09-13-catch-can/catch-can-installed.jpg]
Installed catch can in engine bay


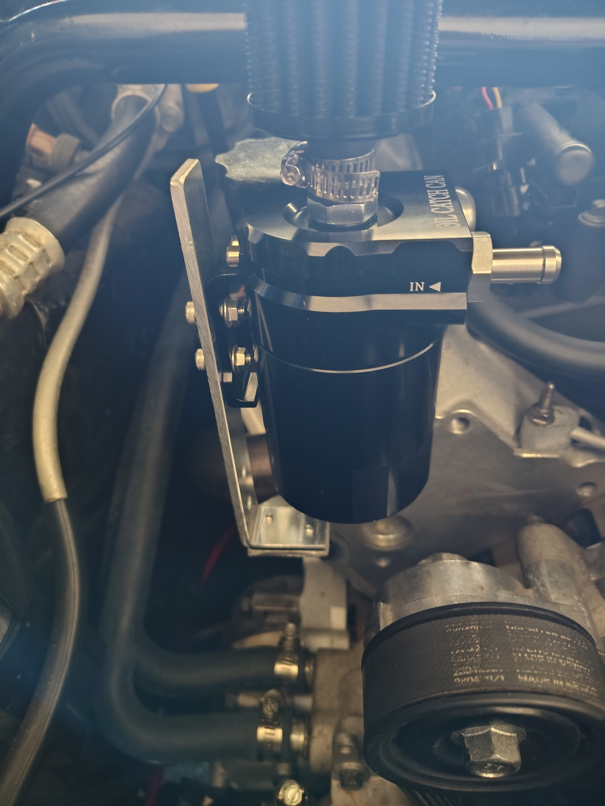
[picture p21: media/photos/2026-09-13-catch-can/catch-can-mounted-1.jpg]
Catch can mounting detail during assembly


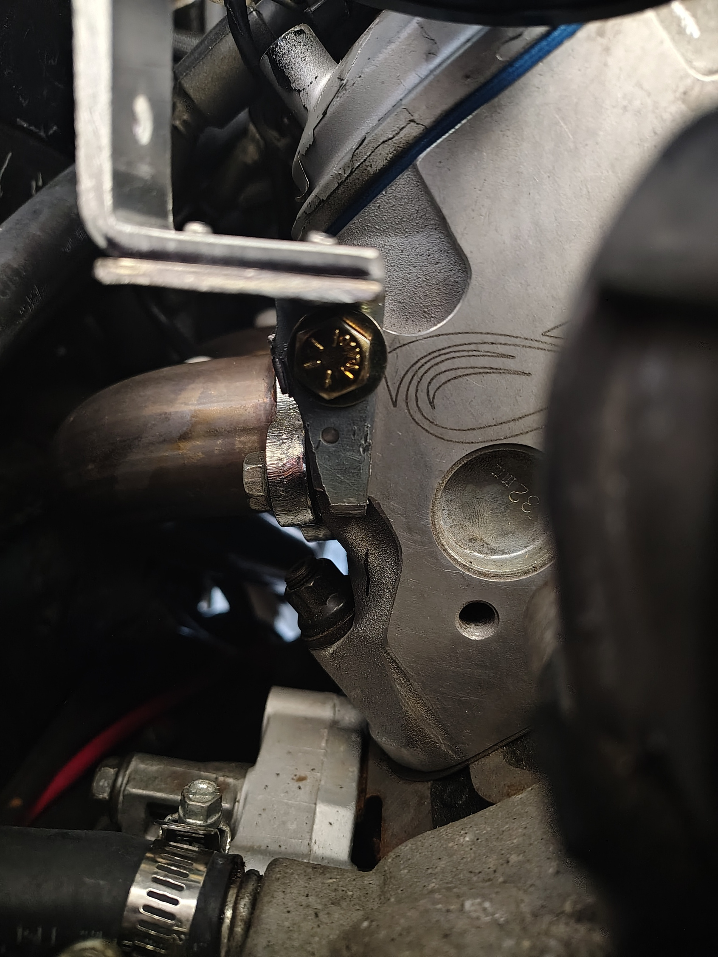
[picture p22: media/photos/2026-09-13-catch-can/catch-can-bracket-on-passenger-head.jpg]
Bracket attached to passenger-side head


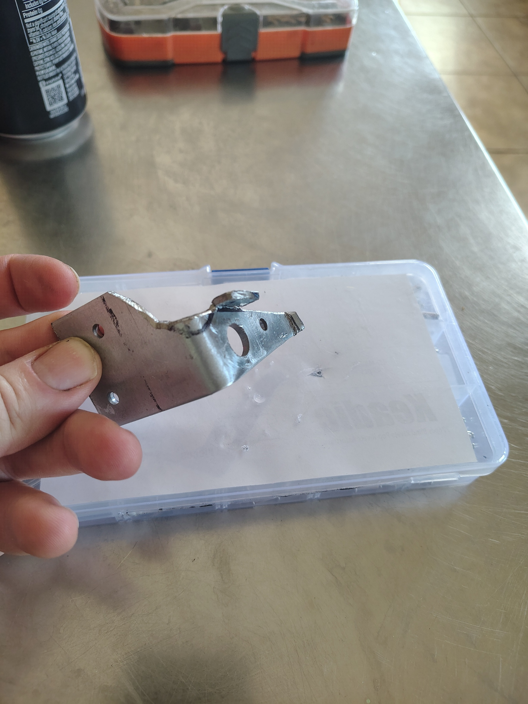
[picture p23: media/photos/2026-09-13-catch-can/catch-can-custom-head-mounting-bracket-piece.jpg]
Fabricated head mounting piece


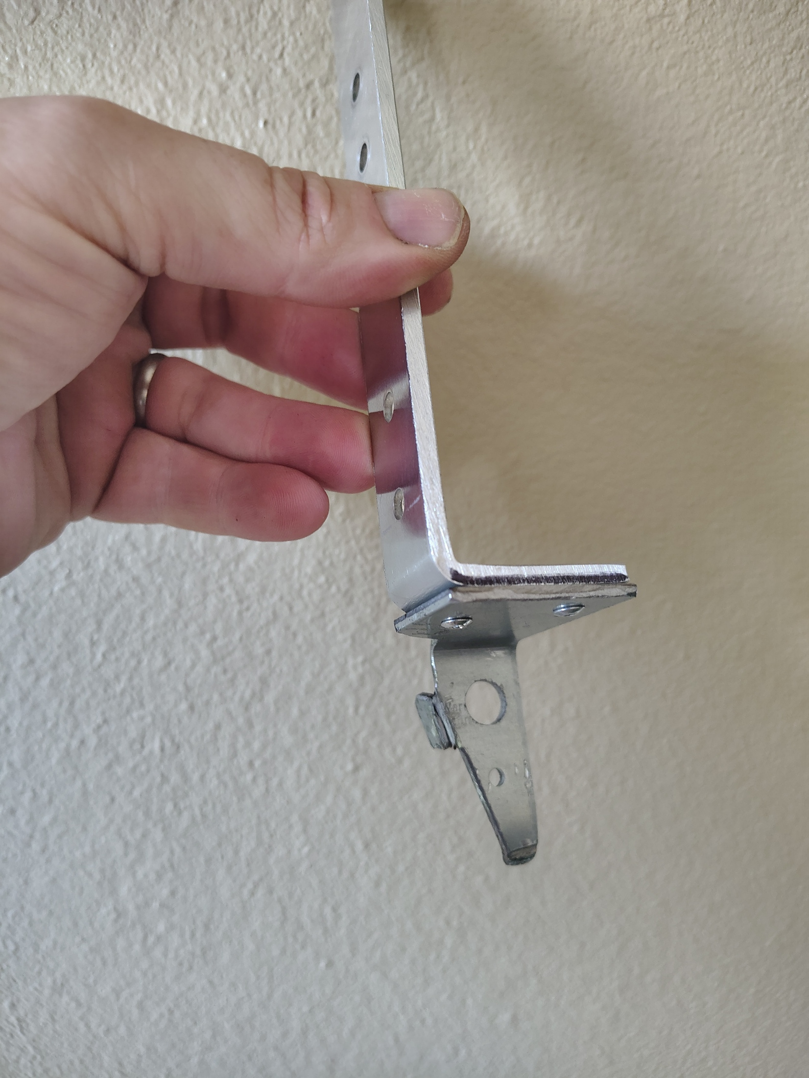
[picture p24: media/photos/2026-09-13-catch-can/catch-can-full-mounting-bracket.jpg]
Complete bracket assembly


## Import provenance and limits

Imported from supplied batch `2026-09-06-pcv`: planning notes, a dated September 13 installation note, and five installation photographs. The folder date indicates planning; the installation date comes from the note, not an asserted camera timestamp. Originals remain in private local staging. One public filename corrects `peice` to `piece`.

The public record omits exact vehicle mileage, purchase transaction details, private log/tune identifiers and paths, URL tracking parameters, and unrelated discussion. Downloaded vendor product images remain private; they are unnecessary to document this installation. No faces, plates, addresses, or other obvious personal identifiers were observed in the five selected photos.

The planning notes also report a prior warm-idle log analysis supporting the 3 mm starting point. Its underlying logs were not supplied in this batch, so those statistics are not imported as verified measurements. General break-in advice and supplier availability claims from the older notes are not adopted as current guidance.

See the [current BOM](../../hardware/bom/parts.md), [project status](../status.md), and [test plan](../testing/test-plan.md) for ongoing work.

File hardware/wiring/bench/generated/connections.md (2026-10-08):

# W01 connection schedule

Generated from [bench-harness.yml](../bench-harness.yml); do not edit this table.
**Draft: not assembly-ready.** `TBD` names are functional requirements, not terminal IDs.
`W_USB` represents a complete USB cable, not one conductor. Other wire numbers identify
conductors within a documentation bundle, not connector cavities. Colors specify added bench wiring,
not purchased pigtail colors or verified terminal functions. Label and record substitutions.

| Bundle / wire | Net or function | Planned color | Endpoint A | Endpoint B | Evidence / dependency |
| --- | --- | --- | --- | --- | --- |
| W_USB / 1 | USB cable | Unassigned (see note) | USB_SOURCE.PLUG | J1.USB_NATIVE | Complete USB cable, NOT one conductor.; Native USB: left front view / USB label; COM unused.; Computer cable must support data; source/load capacity Q12.; Color unspecified: complete factory cable. |
| W_RAIL / 1 | 3V3 | OG / Orange | J1.L1 | RAILS.3V3 | Carrier feeds: L1 3V3, L22 GND, L21 nominal 5 V.; IN-OUT closed; USB-OTG open; family assumption Q30.; 5 V is after USB input diode; voltage/load checks Q05/Q12.; Length (mm), termination and substitutions: as-built record. |
| W_RAIL / 2 | GND | BK / Black | J1.L22 | RAILS.GND | Carrier feeds: L1 3V3, L22 GND, L21 nominal 5 V.; IN-OUT closed; USB-OTG open; family assumption Q30.; 5 V is after USB input diode; voltage/load checks Q05/Q12.; Length (mm), termination and substitutions: as-built record. |
| W_RAIL / 3 | 5V_USB | RD / Red | J1.L21 | RAILS.5V | Carrier feeds: L1 3V3, L22 GND, L21 nominal 5 V.; IN-OUT closed; USB-OTG open; family assumption Q30.; 5 V is after USB input diode; voltage/load checks Q05/Q12.; Length (mm), termination and substitutions: as-built record. |
| W_LCD / 1 | DISP_RST | WH / White | J1.L5 | J2.RST | Proposed signal allocation Q14.; Verify display logic domain Q06.; Length (mm), termination and color substitutions: as-built record. |
| W_LCD / 2 | DISP_CS | BU / Blue | J1.L16 | J2.CS | Proposed signal allocation Q14.; Verify display logic domain Q06.; Length (mm), termination and color substitutions: as-built record. |
| W_LCD / 3 | DISP_DC | VT / Violet | J1.L4 | J2.DC | Proposed signal allocation Q14.; Verify display logic domain Q06.; Length (mm), termination and color substitutions: as-built record. |
| W_LCD / 4 | SPI_MOSI | GN / Green | J1.L17 | J2.SDA | Proposed signal allocation Q14.; Verify display logic domain Q06.; Length (mm), termination and color substitutions: as-built record. |
| W_LCD / 5 | SPI_CLK | YE / Yellow | J1.L18 | J2.SCL | Proposed signal allocation Q14.; Verify display logic domain Q06.; Length (mm), termination and color substitutions: as-built record. |
| W_LCD_PWR / 1 | DISP_3V3 | OG / Orange | RAILS.3V3 | J2.VCC | Selected 3.3 V display power Q31; listing range 3-5 V.; Current/backlight and regulator margin checks Q06/Q12.; Length (mm), termination and substitutions: as-built record. |
| W_LCD_PWR / 2 | GND | BK / Black | RAILS.GND | J2.GND | Selected 3.3 V display power Q31; listing range 3-5 V.; Current/backlight and regulator margin checks Q06/Q12.; Length (mm), termination and substitutions: as-built record. |
| W_ADC / 1 | 5V_SHARED | RD / Red | RAILS.5V | J3.V | Shared 5 V ADC power and LS1 HV1/HV2 bus.; Verify Q07/Q08/Q12; translator bring-up Q29.; Length (mm), termination and substitutions: as-built record. |
| W_ADC / 2 | GND | BK / Black | RAILS.GND | J3.G | Shared 5 V ADC power and LS1 HV1/HV2 bus.; Verify Q07/Q08/Q12; translator bring-up Q29.; Length (mm), termination and substitutions: as-built record. |
| W_ADC / 3 | I2C_SDA_HV | GN / Green | LS1.HV1 | J3.SDA | Shared 5 V ADC power and LS1 HV1/HV2 bus.; Verify Q07/Q08/Q12; translator bring-up Q29.; Length (mm), termination and substitutions: as-built record. |
| W_ADC / 4 | I2C_SCL_HV | YE / Yellow | LS1.HV2 | J3.SCL | Shared 5 V ADC power and LS1 HV1/HV2 bus.; Verify Q07/Q08/Q12; translator bring-up Q29.; Length (mm), termination and substitutions: as-built record. |
| W_ADDR / 1 | ADDR_GND | BK / Black | RAILS.GND | J3.ADDR | PROPOSED address 0x48.; Inspect existing bias before fitting Q08/Q18.; Length (mm), termination and color substitutions: as-built record. |
| W_BUTTON / 1 | BUTTON | GY / Gray | J1.L6 | S1.CONTACT_A | Normally open; internal pull-up proposed.; GPIO6 candidate Q14; wire to real contact pair.; Length (mm), termination and color substitutions: as-built record. |
| W_BUTTON / 2 | GND | BK / Black | RAILS.GND | S1.CONTACT_B | Normally open; internal pull-up proposed.; GPIO6 candidate Q14; wire to real contact pair.; Length (mm), termination and color substitutions: as-built record. |
| W_FTP_PWR / 1 | SENSOR_5V | RD / Red | RAILS.5V | FTP.C | P04: GM-family map assumed; C=5 V, A=return.; USB-fed L21 with IN-OUT closed; voltage/load checks Q05/Q12.; Q09: check lead mapping/fit at assembly.; Colors apply to added leads, NOT factory pigtail.; Length (mm), termination and substitutions: as-built record. |
| W_FTP_PWR / 2 | SENSOR_RETURN | BK / Black | RAILS.GND | FTP.A | P04: GM-family map assumed; C=5 V, A=return.; USB-fed L21 with IN-OUT closed; voltage/load checks Q05/Q12.; Q09: check lead mapping/fit at assembly.; Colors apply to added leads, NOT factory pigtail.; Length (mm), termination and substitutions: as-built record. |
| W_RAW / 1 | SENSOR_OUTPUT | BN / Brown | FTP.B | COND.IN | FTP B signal to RC filter IN.; R1/C1 circuit in rc-input-filter component guide.; BN applies to added lead, NOT factory pigtail.; Length (mm), termination and substitutions: as-built record. |
| W_A0 / 1 | FILTERED_A0 | PK / Pink | COND.OUT | J3.A0 | RC OUT (R1/C1 junction) to A0.; Keep short; input stays within ADC GND to VDD.; Power/protection review Q17.; Length (mm), termination and substitutions: as-built record. |
| W_ANALOG_GND / 1 | ANALOG_RETURN | BK / Black | RAILS.GND | COND.GND | C1 return to common analog reference.; No display-only return path.; Length (mm), termination and substitutions: as-built record. |
| W_I2C_LV / 1 | I2C_SDA_LV | GN / Green | J1.L12 | LS1.LV1 | ESP32 3.3 V I2C to LS1 LV1/LV2.; Selected channels 1=SDA, 2=SCL.; Pull-up/communication bring-up Q29. |
| W_I2C_LV / 2 | I2C_SCL_LV | YE / Yellow | J1.L15 | LS1.LV2 | ESP32 3.3 V I2C to LS1 LV1/LV2.; Selected channels 1=SDA, 2=SCL.; Pull-up/communication bring-up Q29. |
| W_LS_REF / 1 | LS_3V3_REF | OG / Orange | RAILS.3V3 | LS1.LV | Selected module LV/HV supplies and both GND pads.; 5 V shares the sensor/ADC branch.; No enable pin; bring-up Q29; selected source Q30; load checks Q12. |
| W_LS_REF / 2 | LS_5V_REF | RD / Red | RAILS.5V | LS1.HV | Selected module LV/HV supplies and both GND pads.; 5 V shares the sensor/ADC branch.; No enable pin; bring-up Q29; selected source Q30; load checks Q12. |
| W_LS_REF / 3 | LS_GND_LV | BK / Black | RAILS.GND | LS1.GND_LV | Selected module LV/HV supplies and both GND pads.; 5 V shares the sensor/ADC branch.; No enable pin; bring-up Q29; selected source Q30; load checks Q12. |
| W_LS_REF / 4 | LS_GND_HV | BK / Black | RAILS.GND | LS1.GND_HV | Selected module LV/HV supplies and both GND pads.; 5 V shares the sensor/ADC branch.; No enable pin; bring-up Q29; selected source Q30; load checks Q12. |

## Wire color convention

Project convention for W01 additions, not a universal electrical color standard.
Use labels to distinguish buses sharing clock/data colors. Color alone does not identify a net.
Display VCC uses orange for the selected 3.3 V supply; the nominal 5 V branch uses red.
The factory USB cable has no specified jacket or internal-conductor color.
Blank-color lines render neutrally; they are not instructions to use ground wire.

| Code | Color | Use |
| --- | --- | --- |
| BK | Black | Ground/return, including ADDR-to-GND strap |
| RD | Red | Nominal USB-fed 5 V supply, shared sensor/ADC branch and translator HV reference; Q30 selected, voltage/load checks Q12 |
| OG | Orange | 3.3 V supply |
| YE | Yellow | Clock: SPI CLK or I2C SCL, identified by bundle/net |
| GN | Green | Data: SPI MOSI or I2C SDA, identified by bundle/net |
| BU | Blue | Display chip select |
| VT | Violet | Display data/command |
| WH | White | Display reset |
| GY | Gray | Button signal |
| BN | Brown | Raw sensor output, added harness lead only |
| PK | Pink | Conditioned ADC A0 signal |

## Proposed controller assignments

Derived from J1 in the same source. L coordinates refer to P01's front-view left row.
These are design proposals under Q14, not measured pin functions.

| J1 location | GPIO / function |
| --- | --- |
| USB_NATIVE | Native USB / left |
| L1 | 3V3 |
| L4 | GPIO4 / DISP_DC |
| L5 | GPIO5 / DISP_RST |
| L6 | GPIO6 / BUTTON |
| L12 | GPIO8 / I2C_SDA |
| L15 | GPIO9 / I2C_SCL |
| L16 | GPIO10 / DISP_CS |
| L17 | GPIO11 / SPI_MOSI |
| L18 | GPIO12 / SPI_CLK |
| L21 | 5Vin / USB-fed 5 V |
| L22 | GND |

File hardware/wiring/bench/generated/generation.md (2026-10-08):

# W01 generation record

Generated from the authoritative source and renderer; no electrical validation is implied.

- Source SHA-256: `9fd5208733972fa7e8c556b8aabb85f99c0d8c655bb8cd3743ea9349efe6fc80`
- Renderer SHA-256: `729c4617566f788393f86395a12dd72861730cacc7a703e169d572d6d3db8099`
- Python: `3.12.10`
- WireViz: `0.4.1`
- PyYAML: `6.0.3`
- Python graphviz binding: `0.21`
- Graphviz executable: `dot - graphviz version 16.1.0 (20260904.0139)`

Command from repository root, with dependencies installed and `dot` on PATH:

```powershell
python hardware/wiring/bench/render.py
```

Each sectional view selects complete cable groups from `x-w01-views` in the source.
No pin or wire mapping is overridden. Colors follow the source's W01 convention;
the blank USB cable color is unassigned, not a ground indication.

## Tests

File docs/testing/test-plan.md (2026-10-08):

# PCV system test plan

This proposed test procedure covers the current component selections. No physical test results or validated operating limits are recorded yet. Earlier rationale is preserved in the [historical context](../LS_PCV_SYSTEM_CONTEXT.md).

Use [A04: PCV system overview](../../hardware/architecture/pcv-system.md), [A01: overall gauge architecture](../../hardware/architecture/gauge-system.md) and [A02: power architecture](../../hardware/architecture/power-system.md) as conceptual configuration references. Record the actual test setup and any deviations; these drafts do not establish installed or verified connections.

Use [A03: pressure measurement signal chain](../../hardware/architecture/measurement-system.md) when defining calibration, stale/fault, zero/reset and peak-response checks. Its behavior is proposed, not a record of completed tests.

## Objective and conventions

Compare restrictors using repeatable measured crankcase pressure, oil carryover, and operating behavior. Use `inH2O` relative to atmosphere, with negative values indicating vacuum. The 3 mm restrictor and roughly -3 to -8 inH2O hot-idle/cruise range are working assumptions, not pass/fail limits.

Record configuration and evidence using the [data conventions](../../data/README.md). Do not interpret the relief valve's published cracking pressure as measured behavior or proof of sufficient flow capacity.

## 1. Document the configuration

- Record hose routing, fresh-air path, catch-can port assignments, pressure tap, restrictor measured bore, and relief orientation.
- Identify actual sensor, connector terminals, power supply, ADC/reference, and firmware revision when present.
- Measure crankcase/catch-can pressure upstream of the restrictor; protect the sensor from direct liquid oil exposure.
- Inspect hoses, retention, mounting, wiring, and catch-can condition before testing.

For gauge bench work, start with the documented [power integration checks](../../hardware/components/gauge-power-supply/README.md), [P04 sensor terminal/fit checks](../../hardware/pinouts/ftp-sensor.md), and [ADS1115 setup](../../hardware/components/adc/README.md). Record the actual conditioning components, gain, conversion rate, channel/address, and supply arrangement with the calibration. The former divider is superseded; the initial signal filter is 470 ohm / 1 uF, with stock parts and response to record/validate; fuse values remain design work. Verify the shared 5 V branch and separate I2C voltage domains before integrating the sensor and ADC.

[W01's phased assembly guide](../../hardware/wiring/bench/README.md#phased-assembly-and-verification) adds configuration-specific prerequisites and section views for the N16R8 USB bench setup. Resolve each phase's marked interfaces before connection or power; converter checks apply only when that source is introduced. Q30/Q31 define native USB, IN-OUT closed, USB-OTG open, nominal USB-fed 5 V and 3.3 V display power. Include actual diode/cable drop and source/load margin in phase checks. The harness draft and rendering checks are not bench-test results.

## 2. Characterize the sensor on the bench

1. Verify terminal positions and electrical compatibility before applying power.
2. Equalize the pressure port to atmosphere and record raw zero, supply/reference, and setup conditions.
3. Use a water manometer to apply known positive and negative differential pressures within the verified sensor range. Read total water-level difference, not just one leg's displacement; prevent water entering the sensor.
4. Record multiple points in both directions and repeat zero. Points such as +5 and -5 inH2O are examples only, pending range verification.
5. Derive calibration from readings; check residuals, sign, repeatability, and usable range. Preserve raw points and calculation method.
6. Check zero/reset controls, sensor fault indication, and min/max capture against known pressure changes. Record sample rate and filtering so missed or smoothed peaks can be assessed.

Do not proceed to tuning on an unverified sensor equation or unexplained zero drift.

## 3. Characterize the relief path on the bench

1. Confirm flow orientation from catch can to atmosphere; crankcase vacuum should close the valve.
2. Measure opening and reseating pressure over repeated slow pressure ramps using a suitable reference.
3. Check reverse leakage under vacuum and effects of installation orientation.
4. If modifying the spring, record original/replacement dimensions and results for each configuration. Do not infer the outcome from spring cutting alone.
5. Evaluate relief flow behavior separately from cracking pressure; document the setup and limitations of the test.

Approximately 0.08-0.12 PSI (2.2-3.3 inH2O) is the desired initial opening range. The published 0.5 PSI setting is approximately 13.8 inH2O and has not been accepted for the intended relief function.

## 4. Vehicle comparison

Before increasing load, establish and record configuration-specific stop criteria and an independently checked pressure indication. Stop for unexplained readings, excessive pressure/vacuum relative to those criteria, leaks, hose movement, or abnormal oil carryover. Investigate before continuing; this document does not yet establish validated numeric limits.

Start with the 3 mm baseline. Change one variable at a time and record a separate run for each configuration. Progress through engine-off atmospheric verification, cold idle, warm idle, light/moderate cruise, closed-throttle deceleration, moderate acceleration, and hot restart. High-load/WOT tests follow only after earlier checks support proceeding, in a controlled appropriate setting.

Use logging or stored peaks; do not require the driver to watch the gauge during a pull. Record RPM, MAP, and throttle position when available; label absent channels rather than estimating them.

For each run capture positive/negative peaks, steady-state pressure, engine temperature/operating state, ambient conditions, idle quality, vapor/leaks, catch-can contents, and oil-consumption observations over a stated interval. Compare 2 and 4 mm variants under similar conditions; repeat the baseline to assess variability.

## Results and decisions

Link raw logs, calibration, configuration revision, observations, and analysis. Record what the evidence supports, uncertainties, and the next action. Update component documents and [project status](../status.md) when the evidence changes a design decision. Document review or a successful firmware build does not validate physical hardware.

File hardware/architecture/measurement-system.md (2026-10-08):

# Pressure measurement signal chain

A03 describes the planned pressure measurement chain, from the FTP sensor through calibration, peak capture and display. It applies to either selected ESP32-S3 board. The embedded Mermaid defines measurement responsibilities; firmware implementation and physical validation remain pending.

## From pressure to indication

```mermaid
flowchart TD
    pressure["Pressure at proposed upstream-of-restrictor tap"]
    sensor["FTP sensor: pressure to analog voltage"]
    analog["Analog filtering and protection; no divider"]
    adc["ADS1115: new conversion"]
    acquire["ESP32-S3: acquire counts, timestamp and status"]
    calibrate["Apply measured calibration and accepted zero offset"]
    valid{"Sample and calibrated result valid?"}
    accepted["Valid signed pressure in inH2O"]
    peaks["Update min/max from each accepted sample"]
    smooth["Display smoothing only"]
    fault["Mark invalid or stale; do not substitute zero"]
    state["Gauge state: live value, min/max, validity and age"]
    display["GC9A01: render at display cadence"]
    calibration["Calibration record for actual sensor and ADC chain"]
    zero["Deliberate atmospheric zero: conditions verified"]
    reset["Deliberate peak reset"]

    pressure ---|"Pressure sense hose"| sensor
    sensor -->|"Analog voltage"| analog
    analog -->|"Filtered ADC input"| adc
    adc -->|"I2C via 5 V / 3.3 V translator"| acquire
    acquire --> calibrate
    calibration -.->|"Coefficients and valid configuration"| calibrate
    zero -.->|"Accepted zero correction"| calibrate
    calibrate --> valid
    valid -->|"Yes"| accepted
    valid -->|"No"| fault
    acquire -.->|"Read failure or timeout"| fault
    accepted --> peaks
    accepted --> smooth
    reset -.-> peaks
    peaks --> state
    smooth --> state
    fault --> state
    state --> display

    classDef physical fill:#e8f3fc,stroke:#245a81,color:#142c3e
    classDef processing fill:#e8f4e8,stroke:#376b37,color:#173717
    classDef decision fill:#fff1d6,stroke:#956000,color:#493000
    classDef reference fill:#f3f3f3,stroke:#666,color:#333,stroke-dasharray:5 5
    class pressure,sensor,analog,adc physical
    class acquire,calibrate,accepted,peaks,smooth,state,display processing
    class valid,fault decision
    class calibration,zero,reset reference
```

**Legend:** solid arrows carry signals or derived data; the solid line without an arrow is pressure sensing; dashed arrows are configuration, user actions or an exceptional acquisition path. The validity diamond is a processing decision, not a pressure alarm threshold. Every block is planned. Physical and software boundaries are functional, not thread/task assignments.

## Measurement boundary and supplies

The [PCV overview (A04)](pcv-system.md) proposes sensing the catch-can outlet line before the restrictor. This measures pressure at the tap relative to atmosphere, not intake manifold pressure. Hose/catch-can losses may separate tap pressure from actual crankcase pressure; sensor mounting and this difference need evaluation. No second pressure sensor is selected here.

The [overall gauge architecture (A01)](gauge-system.md) supplies system context. Per [A02](power-system.md), the FTP sensor and ADS1115 share regulated 5 V. I2C translation connects the ADC to the ESP32's 3.3 V logic. Select +/-6.144 V for the assumed 0-5 V signal envelope; no divider compensation applies. The initial [470 ohm / 1 uF RC filter](../components/rc-input-filter/README.md) is selected; its physical response and any justified additional protection remain Q17, with translator selection resolved under Q28 and physical bus checks under Q29.

## Stage responsibilities

| Stage | Preserve or produce | Decision / evidence still needed |
| --- | --- | --- |
| Pressure sense and FTP sensor | Pressure-relative-to-atmosphere signal | Actual sensor terminals, reference arrangement, range, mounting and pneumatic response |
| Analog conditioning | Unscaled sensor voltage with filtering/protection | Final values, loading, tolerances, fault behavior and settling; preliminary values are in the [ADC notes](../components/adc/README.md) |
| ADS1115 conversion | New raw conversion counts | Chip/module identity, channel, gain, mode, address and supported conversion rate |
| Acquisition | Counts, sample timestamp/age and acquisition status | Readiness detection, timeouts and measured effective sample cadence |
| Calibration | Signed inH2O using an identified calibration record and accepted zero correction | Measured transfer model, coefficient units, validity range and matching hardware/configuration |
| Validity handling | Accepted result or explicit invalid/stale state | Testable limits and fault detection; no invented numeric thresholds |
| Peak path | Lowest and highest accepted pressure since the chosen reset boundary | Reset/initialization policy, persistence and measured response |
| Display path | Smoothed live indication plus independent min/max and status | Smoothing method and display cadence/readability |

Input checks occur before conversion as needed; the single validity diamond summarizes checks across acquisition, calibration and the resulting pressure. Missing/mismatched calibration, failed reads and stale samples must not become valid numbers. Detection of every physical fault is not guaranteed by this diagram: disconnected sensors or implausible values require an actual detection design and tests.

## Calibration and zero

Calibrate the complete sensor/conditioning/ADC chain against a known pressure reference. A fitted conversion may map raw counts directly to pressure; this diagram does not require reconstructing sensor voltage as an intermediate step or assume a generic OE transfer curve. Preserve raw readings and the model/configuration under the [data conventions](../../data/README.md).

If voltage columns are recorded, use the actual ADC range: nominally 187.5 uV/count at +/-6.144 V. The selected circuit has no divider correction. ADC input voltage and sensor voltage can differ because of filtering/loading or wiring; do not describe a computed sensor voltage as an independent measurement. Historical divider configurations retain their own calibration and ratio.

Atmospheric zero is a deliberate operation with the pressure port equalized to atmosphere. Never automatically zero while the engine runs or treat a running average as atmosphere. Zero correction cannot replace slope/range calibration or repair an invalid sensor. The diagram shows an accepted offset, not a chosen button count or automatic acceptance algorithm.

When calibration or zero changes, existing peaks may no longer be comparable. Reset, rebase from preserved raw data, or retain them under their prior calibration identity only through an explicitly chosen policy; that policy and persistence remain TBD. Peak reset is a separate user action from atmospheric zero.

## Timing, smoothing and faults

Use each new accepted conversion for peak tracking before display-only smoothing. Do not sample only when the screen refreshes, count repeated reads of the same conversion as new samples, or let drawing operations silently reduce acquisition cadence. Specific scheduling, buffering and task structure belong to future firmware design.

The [ADC plan](../components/adc/README.md) records provisional acquisition and display-rate goals. A supported ADS1115 rate and actual throughput must be selected/measured together; no timing guarantee is established here. Pneumatic response, sensor response, analog filtering and ADC conversion already limit bandwidth before software sees a reading. Bypassing display smoothing does not imply every physical pressure spike is captured.

Invalid or stale samples do not update valid live pressure or min/max. Show validity/age explicitly; any retained last-good value must be identified as such. Retained peaks describe valid samples only and do not prove coverage during a fault interval. Initialize peaks from an accepted sample rather than inventing a zero reading. Exact stale limits, fault recovery, reset behavior and alarm thresholds remain design tasks.

## Validation and next work

Use the [test plan](../../docs/testing/test-plan.md) to establish sensor zero/slope/repeatability and test the full chain. Future checks should cover sign, units, calibration/configuration mismatch, deliberate zero/reset, stale/failed acquisition, peak preservation during display smoothing, and response to known pressure changes. Keep actual measurements distinct from expected behavior.

See [firmware requirements](../../firmware/README.md) for implementation boundaries. No firmware, calibration coefficients, numeric validity thresholds or measured response results were created with A03. Choose further work through the [inventory](../DIAGRAMS.md).

## Diagram validation

Rendered and visually reviewed with Mermaid CLI 12.0.0 and Node 24.15.0. Checked labels, validity branches, zero/reset inputs and the separate peak/display paths; no clipping was observed. This validates presentation only. The preview remains private scratch output; the embedded Mermaid is the published source.

To reproduce, extract the Mermaid block to `measurement-system.mmd` in a scratch directory and run:

```powershell
npx.cmd --yes --package @mermaid-js/mermaid-cli@12.0.0 mmdc -i measurement-system.mmd -o measurement-system.png --size 2200 -b white
```

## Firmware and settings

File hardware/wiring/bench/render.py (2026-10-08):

"""Render W01 and assembly views from one WireViz source; no connectivity overrides."""

from __future__ import annotations

import argparse
import copy
import hashlib
from importlib.metadata import version
from pathlib import Path
import platform
import subprocess

import yaml
from wireviz import wireviz


HERE = Path(__file__).resolve().parent


def selected_view(source: dict, cable_names: list[str]) -> dict:
    """Select complete connection groups without changing endpoints or wire IDs."""
    unknown = set(cable_names) - source["cables"].keys()
    if unknown:
        raise ValueError(f"Unknown cables in view: {sorted(unknown)}")
    result = copy.deepcopy(source)
    result["connections"] = [
        group for group in result["connections"] if next(iter(group[1])) in cable_names
    ]
    connector_names = {
        next(iter(group[end])) for group in result["connections"] for end in (0, 2)
    }
    result["connectors"] = {
        key: value for key, value in result["connectors"].items() if key in connector_names
    }
    result["cables"] = {
        key: value for key, value in result["cables"].items() if key in cable_names
    }
    return result


def validate(source: dict) -> None:
    """Validate the explicit three-part connection form used by this harness."""
    terminals = source["connectors"]
    cables = source["cables"]
    used_wires: set[tuple[str, int]] = set()
    for name, connector in terminals.items():
        pins = connector["pins"]
        if len(pins) != len(set(pins)) or len(pins) != len(connector["pinlabels"]):
            raise ValueError(f"Invalid pin/label list in {name}")
    for name, cable in cables.items():
        if len(cable["colors"]) != cable["wirecount"]:
            raise ValueError(f"Missing conductor colors in {name}")
        if any(code and code not in source["x-w01-color-convention"] for code in cable["colors"]):
            raise ValueError(f"Undefined color convention in {name}")
    for group in source["connections"]:
        if len(group) != 3 or any(len(part) != 1 for part in group):
            raise ValueError("W01 requires explicit endpoint / cable / endpoint groups")
        (left, left_pins), (cable, wires), (right, right_pins) = [
            next(iter(part.items())) for part in group
        ]
        if not all(isinstance(values, list) for values in (left_pins, wires, right_pins)):
            raise ValueError("Use explicit lists for W01 pins and wires")
        if not len(left_pins) == len(wires) == len(right_pins):
            raise ValueError(f"Mismatched endpoint lengths in {cable}")
        for name, pins in ((left, left_pins), (right, right_pins)):
            if name not in terminals or not set(pins) <= set(terminals[name]["pins"]):
                raise ValueError(f"Unknown terminal in {name}: {pins}")
        for wire in wires:
            if not isinstance(wire, int) or not 1 <= wire <= cables[cable]["wirecount"]:
                raise ValueError(f"Invalid wire {cable}/{wire}")
            if (cable, wire) in used_wires:
                raise ValueError(f"Wire {cable}/{wire} defined twice")
            used_wires.add((cable, wire))
    expected = {
        (name, number)
        for name, cable in cables.items()
        for number in range(1, cable["wirecount"] + 1)
    }
    if used_wires != expected:
        raise ValueError(f"Unconnected cable conductors: {expected - used_wires}")
    for view in source["x-w01-views"].values():
        selected_view(source, view["cables"])


def markdown_cell(value: object) -> str:
    return str(value).replace("|", "\\|").replace("\n", "; ")


def connection_table(source: dict) -> str:
    lines = [
        "# W01 connection schedule",
        "",
        "Generated from [bench-harness.yml](../bench-harness.yml); do not edit this table.",
        "**Draft: not assembly-ready.** `TBD` names are functional requirements, not terminal IDs.",
        "`W_USB` represents a complete USB cable, not one conductor. Other wire numbers identify",
        "conductors within a documentation bundle, not connector cavities. Colors specify added bench wiring,",
        "not purchased pigtail colors or verified terminal functions. Label and record substitutions.",
        "",
        "| Bundle / wire | Net or function | Planned color | Endpoint A | Endpoint B | Evidence / dependency |",
        "| --- | --- | --- | --- | --- | --- |",
    ]
    for group in source["connections"]:
        (left, lp), (cable, wires), (right, rp) = [next(iter(p.items())) for p in group]
        spec = source["cables"][cable]
        for a, wire, b in zip(lp, wires, rp):
            cells = [
                f"{cable} / {wire}",
                spec["wirelabels"][wire - 1],
                (f"{spec['colors'][wire - 1]} / "
                 f"{source['x-w01-color-convention'][spec['colors'][wire - 1]]['name']}"
                 if spec['colors'][wire - 1] else "Unassigned (see note)"),
                f"{left}.{a}",
                f"{right}.{b}",
                spec["notes"],
            ]
            lines.append("| " + " | ".join(markdown_cell(c) for c in cells) + " |")
    lines.extend([
        "", "## Wire color convention", "",
        "Project convention for W01 additions, not a universal electrical color standard.",
        "Use labels to distinguish buses sharing clock/data colors. Color alone does not identify a net.",
        "Display VCC uses orange for the selected 3.3 V supply; the nominal 5 V branch uses red.",
        "The factory USB cable has no specified jacket or internal-conductor color.",
        "Blank-color lines render neutrally; they are not instructions to use ground wire.", "",
        "| Code | Color | Use |", "| --- | --- | --- |",
    ])
    for code, color in source["x-w01-color-convention"].items():
        lines.append(f"| {code} | {color['name']} | {color['use']} |")
    lines.extend([
        "", "## Proposed controller assignments", "",
        "Derived from J1 in the same source. L coordinates refer to P01's front-view left row.",
        "These are design proposals under Q14, not measured pin functions.", "",
        "| J1 location | GPIO / function |", "| --- | --- |",
    ])
    for pin, label in zip(source["connectors"]["J1"]["pins"], source["connectors"]["J1"]["pinlabels"]):
        lines.append(f"| {markdown_cell(pin)} | {markdown_cell(label)} |")
    return "\n".join(lines) + "\n"


def main() -> None:
    parser = argparse.ArgumentParser(description=__doc__)
    parser.add_argument("--output-dir", type=Path, default=HERE / "generated")
    parser.add_argument("--preview-dir", type=Path, help="Optional private PNG preview directory")
    args = parser.parse_args()
    source_path = HERE / "bench-harness.yml"
    source_bytes = source_path.read_bytes()
    source = yaml.safe_load(source_bytes)
    validate(source)
    args.output_dir.mkdir(parents=True, exist_ok=True)
    if args.preview_dir:
        args.preview_dir.mkdir(parents=True, exist_ok=True)

    views = {"bench-harness": copy.deepcopy(source)}
    for name, config in source["x-w01-views"].items():
        view = selected_view(source, config["cables"])
        view["tweak"]["append"][0] = view["tweak"]["append"][0].replace(
            "W01 - DRAFT / NOT ASSEMBLY READY",
            f"W01 - {config['title']} - DRAFT / NOT ASSEMBLY READY",
        )
        views[f"bench-harness-{name}"] = view
    for name, view in views.items():
        wireviz.parse(copy.deepcopy(view), output_formats=("svg",),
                      output_dir=args.output_dir, output_name=name)
        # Graphviz emits platform line endings; keep public text artifacts LF.
        svg_path = args.output_dir / f"{name}.svg"
        svg_text = svg_path.read_text(encoding="utf-8")
        svg_path.write_text(svg_text, encoding="utf-8", newline="\n")
        if args.preview_dir:
            wireviz.parse(copy.deepcopy(view), output_formats=("png",),
                          output_dir=args.preview_dir, output_name=name)
    (args.output_dir / "connections.md").write_text(connection_table(source), encoding="utf-8", newline="\n")
    graphviz_version = subprocess.run(["dot", "-V"], capture_output=True, text=True, check=True)
    dot = (graphviz_version.stdout + graphviz_version.stderr).strip()
    record = [
        "# W01 generation record", "",
        "Generated from the authoritative source and renderer; no electrical validation is implied.", "",
        f"- Source SHA-256: `{hashlib.sha256(source_bytes).hexdigest()}`",
        f"- Renderer SHA-256: `{hashlib.sha256(Path(__file__).read_bytes()).hexdigest()}`",
        f"- Python: `{platform.python_version()}`",
        f"- WireViz: `{version('wireviz')}`",
        f"- PyYAML: `{version('PyYAML')}`",
        f"- Python graphviz binding: `{version('graphviz')}`",
        f"- Graphviz executable: `{dot}`", "",
        "Command from repository root, with dependencies installed and `dot` on PATH:", "",
        "```powershell", "python hardware/wiring/bench/render.py", "```", "",
        "Each sectional view selects complete cable groups from `x-w01-views` in the source.",
        "No pin or wire mapping is overridden. Colors follow the source's W01 convention;",
        "the blank USB cable color is unassigned, not a ground indication.", "",
    ]
    (args.output_dir / "generation.md").write_text("\n".join(record), encoding="utf-8", newline="\n")
    print(f"Validated and rendered {len(views)} views plus connection schedule and generation record.")


if __name__ == "__main__":
    main()

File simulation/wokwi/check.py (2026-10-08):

"""Check L01 against W01; optionally synchronize wires while preserving routes."""

import argparse
from collections import Counter
import json
from pathlib import Path

import yaml


ROOT = Path(__file__).resolve().parent
COLORS = {
    "BK": "black", "RD": "red", "OG": "orange", "YE": "yellow",
    "GN": "green", "BU": "blue", "VT": "violet", "WH": "white",
    "GY": "gray", "BN": "brown", "PK": "pink",
}
# Used native pins, verified against Wokwi's linked official board definition.
NATIVE_PINS = {
    "board-esp32-s3-devkitc-1": {
        "3V3.1", "GND.1", "5V", "4", "5", "6", "8", "9", "10", "11", "12",
    },
    "wokwi-pushbutton": {"1.l", "1.r", "2.l", "2.r"},
    "wokwi-resistor": {"1", "2"},
    "wokwi-text": set(),
}


def edge(a, b, color):
    return (*sorted((a, b)), color)


def main():
    parser = argparse.ArgumentParser(description=__doc__)
    parser.add_argument("--sync", action="store_true", help="Update connection endpoints/colors from W01; inspect routes afterward")
    args = parser.parse_args()
    diagram_path = ROOT / "diagram.json"
    diagram = json.loads(diagram_path.read_text(encoding="utf-8"))
    projection = json.loads((ROOT / "interface-map.json").read_text(encoding="utf-8"))
    source = yaml.safe_load((ROOT / projection["w01_source"]).read_text(encoding="utf-8"))
    endpoints = projection["endpoints"]
    parts = {part["id"]: part for part in diagram["parts"]}
    if len(parts) != len(diagram["parts"]):
        raise ValueError("Duplicate part IDs")
    if diagram["version"] != 1 or diagram["editor"] != "wokwi":
        raise ValueError("Unexpected diagram format")

    pin_sets = {}
    for part_id, part in parts.items():
        if part_id in projection["part_definitions"]:
            path = ROOT / projection["part_definitions"][part_id]
            definition = json.loads(path.read_text(encoding="utf-8"))
            pins = [pin for pin in definition["pins"] if pin]
            if len(pins) != len(set(pins)):
                raise ValueError(f"Duplicate custom pins: {path.name}")
            if part["type"] != "chip-" + path.name.removesuffix(".chip.json"):
                raise ValueError(f"Custom type/definition mismatch: {part_id}")
            if not path.with_suffix(".c").exists():
                raise ValueError(f"Missing online placeholder stub: {path.name}")
            pin_sets[part_id] = set(pins)
        else:
            if part["type"] not in NATIVE_PINS:
                raise ValueError(f"Unreviewed native type: {part['type']}")
            pin_sets[part_id] = NATIVE_PINS[part["type"]]

    for physical, virtual in endpoints.items():
        part_id, pin = virtual.split(":")
        if part_id not in pin_sets or pin not in pin_sets[part_id]:
            raise ValueError(f"Unknown mapped virtual endpoint: {virtual}")
        owner, terminal = physical.split(".")
        if terminal not in source["connectors"][owner]["pins"]:
            raise ValueError(f"Unknown W01 terminal: {physical}")
        if owner == "J1" and virtual.startswith("J1:") and pin.isdigit():
            j1 = source["connectors"]["J1"]
            label = j1["pinlabels"][j1["pins"].index(terminal)]
            if not label.startswith(f"GPIO{pin} /"):
                raise ValueError(f"GPIO mismatch for {physical}: {label} versus {virtual}")

    expected = []
    seen_omissions = set()
    for group in source["connections"]:
        (a, ap), (bundle, nums), (b, bp) = [next(iter(item.items())) for item in group]
        if not len(ap) == len(nums) == len(bp):
            raise ValueError(f"Unequal W01 conductor lists: {bundle}")
        if bundle in projection["omitted_bundles"]:
            seen_omissions.add(bundle)
            continue
        for x, number, y in zip(ap, nums, bp):
            expected.append((endpoints[f"{a}.{x}"], endpoints[f"{b}.{y}"], COLORS[source["cables"][bundle]["colors"][number - 1]]))
    if seen_omissions != {"W_USB"} or set(projection["omitted_bundles"]) != {"W_USB"}:
        raise ValueError("Only the documented whole USB cable may be omitted")
    expected.extend(tuple(connection) for connection in projection["internal_connections"])
    if projection["internal_connections"] != [["R1:2", "C1:OUT", "pink"]]:
        raise ValueError("Unexpected internal RC wiring; review component topology")
    if parts["R1"]["attrs"].get("value") != "470":
        raise ValueError("R1 no longer matches the selected 470 ohm filter")

    if args.sync:
        routes = {(a, b, color): route for a, b, color, route in diagram["connections"]}
        diagram["connections"] = [[a, b, color, routes.get((a, b, color), [])] for a, b, color in expected]
        diagram_path.write_text(json.dumps(diagram, indent=2) + "\n", encoding="utf-8", newline="\n")

    for a, b, color, route in diagram["connections"]:
        if not isinstance(route, list):
            raise ValueError("Wire route must be a list")
        for virtual in (a, b):
            part_id, pin = virtual.split(":")
            if part_id not in pin_sets or pin not in pin_sets[part_id]:
                raise ValueError(f"Unknown wire endpoint: {virtual}")
    actual = Counter(edge(a, b, color) for a, b, color, _ in diagram["connections"])
    target = Counter(edge(*connection) for connection in expected)
    if actual != target:
        raise ValueError(f"W01 mismatch. Missing: {list((target - actual).elements())}; extra: {list((actual - target).elements())}")
    print(f"PASS: {len(parts)} parts, {len(diagram['connections'])} wires; W01 endpoints/colors, unique IDs, custom/native pins and RC topology. USB cable is annotated.")


if __name__ == "__main__":
    main()

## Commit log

2026-10-07 Establish hardware documentation and bench-planning foundations
    - Organize hardware records under hardware/components
    - Adopt public-facing documentation and diagramming standards
    - Add PCV, gauge, power and measurement architecture diagrams
    - Document P01–P06 controller, ADC, sensor, display and converter interfaces
    - Import component references and reconcile restrictor notes with CAD
    - Add an open-questions register for verification and W01 planning
    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
    [pcv-restrictor-2mm.3mf, pcv-restrictor-3mm.3mf, pcv-restrictor-4mm.3mf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]
2026-10-07 Define bench harness requirements and track design decisions
    - Add open-question tracking with resolved decisions and evidence links
    - Select N16R8 bench controller and alternate USB power modes
    - Define complete wiring plans with phased assembly and verification
    - Plan shared firmware with explicit N16R8 and XIAO configurations
    - Select BetterButton controls, zero confirmation and persistent settings
    - Establish sturdy protoboard construction with assembler discretion
    - Import sanitized board references and Espressif module datasheet
    - Update inventory, interface notes and remaining verification requirements
2026-10-08 Document bench gauge wiring and expand component learning guides
    - Add W01 harness with wire colors, connection schedule and phased assembly views
    - Adopt shared 5 V sensor/ADS1115 power with translated 3.3 V I2C
    - Document purchased BSS138 level shifter and built RC input filter
    - Select native USB bench power/debugging and 3.3 V display supply
    - Split controller/display component guides and explain their functions
    - Reframe project purpose around crankcase health monitoring
    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
2026-10-08 Adopt Wokwi for bench illustrations and future firmware simulation
    - Add L01 with complete intended bench wiring and custom visual parts
    - Preserve W01 connections, GPIO assignments, and wire colors
    - Add PNG preview, reusable renderer, and connectivity checker
    - Document model limitations and diagram maintenance workflow
    - Update diagram standards, inventory, cross-references, and AGENTS.md
2026-10-10 Added a pressure tap
    [pressure-tap.FCStd]
2026-10-11 Printed out the pressure-tap
2026-10-11 Document bench layouts and pressure-tap prototype; reconcile project records
    - Add L03 breadboard placement, protoboard guidance and reproducible PNG previews
    - Simplify L01 routing while preserving W01 connectivity
    - Document pressure-tap CAD, exports, PAHT-CF print and planned annealing
    - Import sanitized CAD views and reconcile dimensional discrepancies
    - Update architecture, hardware status, open questions and cross-references
    - Add repeatable repository validation and refine contributor guidance
    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
2026-10-14 Created a protoboard solder plan for initial testing
2026-10-23 Bump pillow from 12.3.0 to 13.0.0 in /hardware/wiring/bench
    Bumps [pillow](https://github.com/python-pillow/Pillow) from 12.3.0 to 13.0.0.
    - [Release notes](https://github.com/python-pillow/Pillow/releases)
    - [Changelog](https://github.com/python-pillow/Pillow/blob/main/CHANGES.rst)
    - [Commits](https://github.com/python-pillow/Pillow/compare/12.3.0...13.0.0)
    ---
    updated-dependencies:
    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
2026-10-26 feat(firmware): establish M00 development foundation
    Add the PlatformIO ESP32-S3 N16R8 project scaffold, board profile,
    startup message, and heartbeat firmware. Document the Windows/Linux
    VS Code setup and record the Windows build, upload, and USB serial
    verification. Leave native Linux verification open.
2026-10-31 Continued work on M01 - We have a working display and button interactions
2026-11-01 Testing and tweaks on Phase 5 of M01. Fixed button polling, and ensured everything is working properly
2026-11-02 docs(firmware): define M02 sensor-to-display milestone
    Add the approved M02 feature, research, architecture, implementation plan,
    and task checklist for the live FTP sensor-to-display measurement path.
2026-11-03 feat(firmware): add and verify ADS1115 voltage acquisition bench path
2026-11-03 feat(firmware): integrate live FTP sensor readings with gauge
2026-11-10 feat(firmware): add live sensor gauge and saved zero reference
2026-11-11 Complete M02 live sensor-to-display prototype
